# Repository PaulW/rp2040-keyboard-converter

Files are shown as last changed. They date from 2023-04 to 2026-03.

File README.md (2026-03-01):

# RP2040 Multi-Protocol Keyboard & Mouse Converter



A USB HID converter for keyboards and mice, using the RP2040's PIO (Programmable I/O) hardware to support multiple protocols.

**Features:**
- Multi-protocol support (AT/PS2, XT, Amiga, Apple M0110)
- Simultaneous keyboard and mouse conversion
- USB HID Boot Protocol for BIOS/UEFI compatibility
- Command Mode for firmware updates without physical access
- Persistent configuration storage

**Quick Links:** [📖 Full Documentation](docs/README.md) | [🚀 Getting Started](docs/getting-started/README.md) | [🔧 Hardware Setup](docs/hardware/README.md) | [💬 Discussions](https://github.com/PaulW/rp2040-keyboard-converter/discussions)

---

## 📚 Documentation

Complete documentation is available in the [`docs/`](docs/) directory. Here's what's covered:

**For Users:**
- [Getting Started](docs/getting-started/README.md) - Setup, building, and flashing firmware
- [Hardware Setup](docs/hardware/README.md) - Wiring diagrams and connector information
- [Supported Protocols](docs/protocols/README.md) - AT/PS2, XT, Amiga, M0110 specifications
- [Supported Keyboards](docs/keyboards/README.md) - Compatible keyboards and configurations
- [Scancode Sets](docs/scancodes/README.md) - Scancode sets and translation reference
- [Features Guide](docs/features/README.md) - Command Mode, LED support, configuration

**For Developers:**
- [Development Guide](docs/development/README.md) - Contributing, code standards, adding keyboards/protocols
- [Advanced Topics](docs/advanced/README.md) - Architecture, performance analysis, troubleshooting

**Quick Reference:**

| I want to... | See... |
|---|---|
| Build and flash firmware | [Getting Started](docs/getting-started/README.md) |
| Connect my keyboard | [Hardware Setup](docs/hardware/README.md) |
| Check compatibility | [Supported Keyboards](docs/keyboards/README.md) |
| Use Command Mode | [Features Guide](docs/features/README.md) |
| Contribute code | [Development Guide](docs/development/README.md) |

---

## ⚡ Quick Start

### 1. Clone Repository

```bash
git clone --recurse-submodules https://github.com/PaulW/rp2040-keyboard-converter.git
cd rp2040-keyboard-converter
```

### 2. Build Firmware

```bash
# Build Docker container (one-time setup)
docker compose build

# Compile firmware for your keyboard
docker compose run --rm -e KEYBOARD="modelm/enhanced" builder

# Optional: Add mouse support
docker compose run --rm -e KEYBOARD="modelm/enhanced" -e MOUSE="at-ps2" builder
```

### 3. Flash to RP2040

1. Hold **BOOT** button, press **RESET**, release **BOOT**
2. Copy `build/rp2040-converter.uf2` to the `RPI-RP2` drive
3. Device reboots automatically with new firmware

**📖 Detailed Instructions:** See [Getting Started Guide](docs/getting-started/README.md)

---

## 🔌 Supported Hardware

### Protocols

| Protocol | Type | Status | Documentation |
|---|---|---|---|
| **AT/PS2** | Keyboard & Mouse | ✅ Full Support | [Specification](docs/protocols/at-ps2.md) |
| **XT** | Keyboard | ✅ Full Support | [Specification](docs/protocols/xt.md) |
| **Amiga** | Keyboard | ✅ Full Support | [Specification](docs/protocols/amiga.md) |
| **M0110** | Keyboard | ⚠️ Partial Support | [Specification](docs/protocols/m0110.md) |

### Example Keyboards

| Manufacturer | Models | Protocol |
|---|---|---|
| **IBM** | Model F (PC/AT), Model M (Enhanced/122-key) | AT/PS2 |
| **Cherry** | G80-0614H, G80-1104H | XT |
| **Commodore** | Amiga A500/A2000 | Amiga |
| **Apple** | M0110/M0110A | M0110 |

**📋 Complete List:** See [Supported Keyboards](docs/keyboards/README.md)

---

## 🛠️ Available Build Configurations

Configure firmware for your specific keyboard when building:

```bash
# IBM keyboards
docker compose run --rm -e KEYBOARD="modelf/pcat" builder
docker compose run --rm -e KEYBOARD="modelm/enhanced" builder
docker compose run --rm -e KEYBOARD="modelm/m122" builder

# Other keyboards
docker compose run --rm -e KEYBOARD="cherry/G80-0614H" builder
docker compose run --rm -e KEYBOARD="amiga/a500" builder
docker compose run --rm -e KEYBOARD="apple/m0110a" builder
```

**🔍 See all configurations:** [`src/keyboards/`](src/keyboards/)

---

## ⚙️ Key Features

### Command Mode
Access firmware functions without physical board access:
- **Bootloader Mode** - Update firmware via USB (press B)
- **Debug Logging** - Adjust UART output level (press D)
- **Factory Reset** - Restore default settings (press F)
- **LED Brightness** - Adjust status LED (press L)
- **Shift Override** - Toggle non-standard shift legend remapping (press S)
- **Flow Tracking** - Toggle pipeline latency tracing, developer builds only (press T)

**Activation:** Hold both Shift keys for 3 seconds

**📖 Details:** [Command Mode Documentation](docs/features/command-mode.md)

### Configuration Storage
Settings persist across reboots and firmware updates:
- Log level preferences
- LED brightness
- Future: Macros and key remapping

**📖 Details:** [Configuration Storage](docs/features/config-storage.md)

### USB HID Boot Protocol
6-key rollover for maximum compatibility:
- Works in BIOS/UEFI
- Compatible with all operating systems
- No driver installation required

**📖 Details:** [USB HID Documentation](docs/features/usb-hid.md)

---

## 🔍 Debugging & Development

For troubleshooting and development information:
- **UART Debug Output** - Connect USB-UART adapter to GPIO 0/1 for diagnostics
- **Command Mode** - Adjust log levels without reflashing (press D in Command Mode)
- **Architecture Details** - See [Advanced Topics](docs/advanced/README.md) for system architecture
- **Development Tools** - See [Development Guide](docs/development/README.md) for lint scripts and testing

---

## 🤝 Contributing

Contributions are welcome! The project welcomes:
- New keyboard/protocol support
- Feature development (NKRO, dynamic keymaps, etc.)
- Hardware designs (PCBs, adapters, cases)
- Documentation improvements

**Before submitting PRs:**
1. Run `./tools/lint.sh` (must pass with zero errors/warnings)
2. Test your configuration builds successfully
3. Review [Development Guide](docs/development/README.md) for coding standards

---

## 📜 License

The project is licensed under **GPLv3** or later. Third-party libraries and code used in this project have their own licenses as follows:

* **Pico-SDK (https://github.com/raspberrypi/pico-sdk)**: License information can be found in the Pico-SDK repository.

* **TinyUSB (https://github.com/hathach/tinyusb)**: License information can be found in the TinyUSB repository. These licenses remain intact in any included portions of code from those shared resources.

* **Ringbuffer implementation (source files: ringbuf.c, etc.)**:
  * Based on code originally created by Hasu@tmk for the TMK Keyboard Firmware project.
  * Potential source references:
    * https://github.com/tmk/tinyusb_ps2/blob/main/ringbuf.h
    * https://github.com/tmk/tmk_keyboard/blob/master/tmk_core/ring_buffer.h
  * License: Likely GPLv2 or later (same as TMK) due to its inclusion in the TMK repository, but the exact origin is unclear.

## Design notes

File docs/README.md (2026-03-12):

# Documentation

**RP2040 Multi-Protocol Keyboard & Mouse Converter**

The RP2040 Multi-Protocol Keyboard & Mouse Converter lets you use vintage keyboards and mice with modern computers via USB. It originally started out as a converter for an IBM Model F PC/AT Keyboard I found in my parents' attic, and has since expanded to support a growing list of protocols, so you can connect a variety of vintage keyboards and mice to modern systems.

This documentation aims to cover everything from initial setup and configuration, through to hardware requirements, the different protocols supported, available features, and how to contribute to the project if you're interested. It may not cover absolutely everything, but should help you understand how it all works and get you up and running.

---

## 🚀 Getting Started

If you're new to the project, or just want to get up and running quickly, the [Quick Start Guide](getting-started/README.md) will walk you through everything from basic hardware setup to building and flashing the firmware.

## 🔧 Hardware

I've used a Waveshare RP2040-Zero for this project, as that's what I already had to hand. The RP2040's PIO (Programmable I/O) hardware provides dedicated state machines that can handle the microsecond-level timing requirements of vintage keyboard protocols without CPU intervention, which is why I chose it for this converter—and it was also a good excuse to learn something new.

- **[Hardware Overview](hardware/README.md)** - In-depth hardware guide with wiring diagrams
- **[Custom PCB](hardware/custom-pcb.md)** - Custom PCB design for IBM Model F

## 📡 Protocols

I've been working on adding support for a variety of protocols used by different devices, and I'm planning to expand this further as I get hold of more keyboards or mice to test with. The [Protocol Overview](protocols/README.md) provides details on what's currently supported, along with technical details on how each protocol is implemented.

### ⌨️ Keyboards

I've documented details about specific devices I currently own and have used to develop this project—hopefully enough detail that you can work out a configuration for your own device too. Check out [Supported Keyboards](keyboards/README.md) for more information.

### ✨ Features

As the project's evolved, I've added various features to make using the converter a bit more streamlined. This will continue to evolve over time as new features are added, but current documentation can be found in the [Features Documentation](features/README.md).

### 🔢 Scancodes

When a key is pressed, the keyboard sends a scancode—just a number identifying which key it was. Different protocols use different scancode sets, and the [Scancode Documentation](scancodes/README.md) explains how each one works, which keyboards use them, and how translation to HID keycodes happens.

### 🎓 Advanced Topics

If you're interested in understanding how the converter works, or need more specific information, I've put together some more technical information which covers things like the architecture, performance characteristics, and inner workings:

- **[Architecture Overview](advanced/README.md)** - System architecture, performance, PIO programming, build system, and troubleshooting

### 👨‍💻 Development

If you're interested in contributing to the project, or want to understand the codebase better, the development guide covers everything you need to know about the project's structure, coding standards, and how to add support for new devices or protocols:

- **[Development Guide](development/README.md)** - Contributing guidelines, code standards, testing, and architecture decisions

---

## 🔍 Quick Reference

### Common Tasks

| I want to... | Go to... |
| --- | --- |
| **Get started quickly** | [Quick Start Guide](getting-started/README.md) |
| **Build the firmware** | [Building Firmware](getting-started/building-firmware.md) |
| **Connect my keyboard** | [Hardware Setup](getting-started/hardware-setup.md) |
| **See what keyboards are already supported** | [Supported Keyboards](keyboards/README.md) |
| **Check supported Protocols** | [Protocol Overview](protocols/README.md) |
| **Understand scancode translation** | [Scancode Sets](scancodes/README.md) |
| **Understand architecture** | [Advanced Topics](advanced/README.md) |
| **Add a new keyboard** | [Development Guide](development/README.md) |
| **Contribute code** | [Development Guide](development/README.md) |

---

## 🔗 External Resources

- **[Main README](../README.md)** - Project overview
- **[Source Code](../src/)** - Firmware source code
- **[Pico SDK Documentation](https://www.raspberrypi.com/documentation/pico-sdk/)** - RP2040 SDK
- **[TinyUSB Documentation](https://docs.tinyusb.org/)** - USB stack
- **[GitHub Issues](https://github.com/PaulW/rp2040-keyboard-converter/issues)** - Report bugs or request features
- **[GitHub Discussions](https://github.com/PaulW/rp2040-keyboard-converter/discussions)** - Ask questions

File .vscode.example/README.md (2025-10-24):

# VS Code Configuration Examples

This directory contains example VS Code configuration files for local development with IntelliSense and CMake integration.

## Setup for Local Development (Optional)

**Note:** Local development setup is **optional**. You can use Docker for all builds without any local tooling.

### Prerequisites

#### macOS

1. **CMake** (for IntelliSense and build configuration)
   ```bash
   brew install cmake
   ```

2. **ARM GCC Toolchain** (for compiling)
   ```bash
   brew install --cask gcc-arm-embedded
   ```
   - Installs to: `/Applications/ArmGNUToolchain/*/arm-none-eabi/bin/`
   - Symlinked to: `/opt/homebrew/bin/arm-none-eabi-gcc`

3. **Pico SDK Submodule** (already included if you cloned with `--recurse-submodules`)
   ```bash
   git submodule update --init --recursive
   ```

#### Linux

1. **CMake**
   ```bash
   # Debian/Ubuntu
   sudo apt-get install cmake
   
   # Fedora
   sudo dnf install cmake
   
   # Arch
   sudo pacman -S cmake
   ```

2. **ARM GCC Toolchain**
   ```bash
   # Debian/Ubuntu
   sudo apt-get install gcc-arm-none-eabi
   
   # Fedora
   sudo dnf install arm-none-eabi-gcc-cs
   
   # Arch
   sudo pacman -S arm-none-eabi-gcc
   ```
   - Typically installs to: `/usr/bin/arm-none-eabi-gcc`

3. **Pico SDK Submodule**
   ```bash
   git submodule update --init --recursive
   ```

#### Windows

1. **CMake**
   - Download from [cmake.org](https://cmake.org/download/)
   - Or use: `winget install Kitware.CMake`

2. **ARM GCC Toolchain**
   - Download from [ARM Developer](https://developer.arm.com/tools-and-software/open-source-software/developer-tools/gnu-toolchain/gnu-rm)
   - Typically installs to: `C:\Program Files (x86)\GNU Arm Embedded Toolchain\<version>\bin\arm-none-eabi-gcc.exe`

3. **Pico SDK Submodule**
   ```bash
   git submodule update --init --recursive
   ```

### Installation

1. Copy the example configuration files to `.vscode/`:
   ```bash
   cp -r .vscode.example/ .vscode/
   ```

2. Configure CMake to generate `compile_commands.json`:
   ```bash
   mkdir -p .build-cache
   cd .build-cache
   cmake -DCMAKE_BUILD_TYPE=Debug \
         -DCMAKE_EXPORT_COMPILE_COMMANDS=ON \
         -DKEYBOARD=modelm/enhanced \
         -DMOUSE=at-ps2 \
         ../src
   cp compile_commands.json ..
   ```

3. Reload VS Code:
   - Press `Cmd+Shift+P` (Mac) or `Ctrl+Shift+P` (Windows/Linux)
   - Run **"Developer: Reload Window"**

### What You Get

- ✅ **IntelliSense** - Autocomplete for Pico SDK functions
- ✅ **Go to Definition** - Navigate to SDK headers and implementation
- ✅ **Error Checking** - Real-time syntax and type checking
- ✅ **Symbol Navigation** - Jump between functions and definitions
- ✅ **CMake Integration** - Configure and build from VS Code
- ✅ **File Associations** - 24+ header files properly recognized as C (project headers, Pico SDK, TinyUSB)
- ✅ **Code Formatting** - Google style with 100 column limit pre-configured
- ✅ **Doxygen Comments** - `/**` style for documentation

### Customization

Edit `.vscode/settings.json` to change the keyboard/mouse configuration:

```json
"cmake.configureEnvironment": {
  "KEYBOARD": "your-keyboard-here",
  "MOUSE": "at-ps2"
}
```

Available keyboards: `modelm/enhanced`, `modelf/pcat`, `xt/ibm5150`, `apple/m0110a`, `amiga/a500`

### Platform-Specific Notes

#### macOS
- ARM toolchain path: `/opt/homebrew/bin/arm-none-eabi-gcc` (Apple Silicon) or `/usr/local/bin/arm-none-eabi-gcc` (Intel)
- The example `c_cpp_properties.json` uses the Homebrew path
- If you installed the toolchain differently, update `compilerPath` in `.vscode/c_cpp_properties.json`

#### Linux
- ARM toolchain typically at: `/usr/bin/arm-none-eabi-gcc`
- Update `compilerPath` in `.vscode/c_cpp_properties.json` to match your installation
- Configuration name can be changed from "RP2040" to "Linux" if desired

#### Windows
- ARM toolchain path example: `C:/Program Files (x86)/GNU Arm Embedded Toolchain/10 2021.10/bin/arm-none-eabi-gcc.exe`
- Use forward slashes (`/`) in paths, not backslashes
- Update `compilerPath` in `.vscode/c_cpp_properties.json` to match your installation
- Create a "Windows" configuration in `c_cpp_properties.json` if needed

### Notes

- `.vscode/` is in `.gitignore` - your settings won't be committed
- `compile_commands.json` is regenerated each time you run CMake
- Docker builds don't require any of this setup
- **Compiler path varies by platform**: Update `compilerPath` in `c_cpp_properties.json` to match your system
  - macOS (Homebrew): `/opt/homebrew/bin/arm-none-eabi-gcc`
  - Linux: `/usr/bin/arm-none-eabi-gcc`
  - Windows: `C:/Program Files (x86)/GNU Arm Embedded Toolchain/<version>/bin/arm-none-eabi-gcc.exe`

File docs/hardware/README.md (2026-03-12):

# Hardware Guide

This guide covers everything you need to know about the hardware side of building the converter—from choosing the right components to understanding why certain design decisions were made. Whether you're planning a simple breadboard prototype or designing a custom PCB to fit inside your keyboard, you'll find what you need here.

---

## What's in This Guide

- **[Build Approaches](#choosing-your-build-approach)** - Breadboard vs PCB: which is right for you?
- **[Component Deep Dive](#understanding-components)** - Everything about RP2040 boards and level shifters
- **[Connectors and Cables](#connectors-and-cables)** - Finding the right connectors and where to get them
- **[Status LEDs](#status-leds)** - Adding visual feedback with WS2812B RGB LEDs
- **[Breadboards and Prototyping Supplies](#breadboards-and-prototyping-supplies)** - What you need for breadboard builds
- **[Custom PCB](#custom-pcb)** - Professional PCB design for internal installations

---

## Choosing Your Build Approach

There are a few different ways you can build this converter, and each has its trade-offs. I'd say it's worth taking a few minutes to think about what you're trying to achieve before you start buying components or wiring things up.

### Breadboard Prototype

**Best for**: First-time builds, testing, experimentation, or if you want to support multiple keyboards

A breadboard build is where I'd recommend starting. There's no soldering involved, you can put it together in under an hour, and if something's not working you can easily swap things around. It's forgiving, which is great if you're new to this or just want to test whether your keyboard actually works before you commit to anything permanent.

**What makes breadboards great:**

- **Quick to set up**: You can have it up and running in a single sitting
- **No soldering needed**: Just jumper wires and pre-made modules
- **Easy to modify**: Want to try different pins? Just pull it out and move it
- **Low cost**: Just the cost of a microcontroller, some jumper wires, and a connector
- **Reusable**: Take it apart and use the bits for something else
- **Great for learning**: You can actually see all the connections

**The trade-offs:**

- **Needs an external enclosure**: Breadboards require external housing
- **Connections can work loose**: Breadboards are fine for testing, but they're not great for long-term reliability
- **More wiring**: It's not as tidy as a PCB
- **Not ideal for portability**: If you're taking your keyboard places, loose connections aren't brilliant

**When this makes sense:**

- You're new to electronics and want something forgiving
- You're testing multiple keyboards or protocols
- You're developing new features or troubleshooting issues
- You want to try it out before committing to something permanent
- Budget's a concern

For the step-by-step breadboard build, check out the **[Getting Started Guide](../getting-started/hardware-setup.md)**.

---

### Custom PCB

**Best for**: Permanent installations, internal keyboard mounting, or if you want it to look professional

If you have a keyboard you really care about—maybe it's a collectible, or just something you want to use long-term—a custom PCB is worth considering. Everything's on one neat board, no loose wiring, and if you design it right you can mount it inside the keyboard so it's completely hidden. I built one for my IBM Model F PC/AT, and you'd never know it was there from the outside.

**What makes PCBs great:**

- **Looks professional**: Clean and compact
- **Internal installation**: Hide it inside the keyboard case—no external box
- **Solid connections**: Soldered joints don't work loose
- **Compact**: You can design boards to fit specific spaces
- **Integrated**: Everything on one board—level shifter, RP2040, connectors
- **Strain relief**: Proper mounting means cables aren't going to pull things apart

**The trade-offs though:**

- **Higher upfront cost**: PCB fabrication and components cost more upfront than a dev board solution
- **Needs PCB skills**: You'll need to know your way around KiCad or similar, and be comfortable soldering
- **Less flexible**: If you want to change protocols or pins, you're designing a new board
- **Keyboard-specific**: Designs are optimised for particular keyboards
- **Takes longer**: Design, order, wait for delivery, and assemble—longer than a breadboard build

**When this makes sense:**

- You have a valuable or collectible keyboard that deserves a proper installation
- You're comfortable with PCB design and soldering (or keen to learn)
- You want the converter to be invisible or minimally invasive
- You have a specific keyboard in mind for permanent conversion
- You're planning to convert multiple units of the same keyboard

**Real example**: My custom PCB for the IBM Model F PC/AT is only 40×30mm and mounts on the keyboard's internal frame using existing screw holes. It's got the level shifter, USB-C, RP2040, everything—completely invisible from outside.

Check out the **[Custom PCB Guide](custom-pcb.md)** for the full design, fabrication files, and installation photos.

---

## Understanding Components

Every converter needs the same core components, whether you're building on breadboard or designing a PCB. Let me walk you through what each one does and why it matters.

### RP2040 Microcontroller Board

This is the brain of the whole operation. The RP2040 handles all the protocol translation, USB communication, and features like Command Mode and Keytest.

**Why the RP2040 works so well for this:**

Other converters use Atmel AVR chips (like in Arduino Pro Micro boards), and they work fine. But the RP2040 has something really useful: **PIO state machines**. These are like little independent hardware processors that can monitor signals with microsecond precision without the main CPU needing to do anything. This means the converter can handle keyboard timing without using much CPU at all.

Traditional microcontrollers either bit-bang protocols in software (struggles with timing) or use fixed hardware peripherals like UART or SPI (not flexible enough). PIO gives you hardware-level timing with software-level flexibility—each state machine runs independently, watching the CLOCK and DATA lines.

**Key specs:**

- **Dual ARM Cortex-M0+ cores** running at 125MHz (we only use one)
- **264KB SRAM** - plenty of room, we run the code from RAM for performance
- **Eight PIO state machines** - hardware-level I/O with microsecond precision
- **30 GPIO pins** - flexible, can be assigned to any function
- **Native USB 1.1** support via TinyUSB
- **Low power** - minimal CPU usage even when typing

**Which board should you get?**

They're all based on the same RP2040 chip, so they're functionally identical. It comes down to size and USB connector.

| Board | Size | USB |
| --- | --- | --- |
| **Raspberry Pi Pico** | 51×21mm | Micro-B |
| **WaveShare RP2040-Zero** | 23.5×18mm | USB-C |
| **Pimoroni Tiny 2040** | 22×18mm | USB-C |
| **Adafruit Feather RP2040** | 51×23mm | USB-C |

The Raspberry Pi Pico has an RP2040 dual-core microcontroller, 26 multi-function GPIO pins, and is available with or without pre-soldered headers. The Waveshare RP2040-Zero has a smaller physical footprint (23.5×18mm), a USB-C connector, and a built-in WS2812B RGB LED on GPIO 16. This LED is compatible with the converter's WS2812B status LED support — set `LED_PIN` to 16 in [`config.h`](../../src/config.h) to use it. See [Status LEDs](#status-leds) for details.

### Bi-Directional Level Shifter

**This is the most important safety component** - don't skip it!

Here's the thing: your keyboard speaks 5V logic, but the RP2040 speaks 3.3V logic. The RP2040's GPIO pins are **NOT 5V tolerant**. If you connect 5V directly to them, you'll damage the chip. There's no "it might survive"—it just dies.

**What it does:**

It sits between your keyboard and the RP2040, translating voltages in both directions:

- Keyboard → RP2040: Converts 5V down to 3.3V (safe for the RP2040)
- RP2040 → Keyboard: Converts 3.3V up to 5V (proper logic levels for the keyboard)

**Why bi-directional?**

Many keyboard protocols require both the keyboard and host to drive the signal lines in both directions. A bi-directional level shifter handles this automatically without needing any direction control signals.

**Which level shifter should you get?**

**BSS138-Based 4-Channel Level Shifter**

Uses BSS138 N-channel MOSFETs for bidirectional level shifting. Suitable for the low-frequency clock and data signals used by AT/PS2 and XT protocols:

- **Channels**: 4 independent channels (2 used for CLOCK/DATA, 2 spare)
- **Speed**: Capable of MHz-range signals; more than sufficient for kHz keyboard protocols

**TXB0104 4-Bit Level Shifter** (Alternative)

Uses the TXB0104 with automatic direction sensing:

- **Chip**: TXB0104 automatic direction sensing
- **Channels**: 4 channels
- **Speed**: 100 Mbps data rate

**Important notes:**

- Both sides need their voltage references (LV=3.3V, HV=5V)
- All grounds must be tied together (keyboard, level shifter, RP2040)
- Never connect keyboard signals directly to RP2040—always through the level shifter
- GPIO pins are configurable in firmware (no fixed assignments)

**How to wire it:**

```text
Level Shifter Module:
LV (Low Voltage)  ─── RP2040 3V3 pin
LV1 (Channel 1)   ─── RP2040 GPIO (you choose which one)
LV2 (Channel 2)   ─── RP2040 GPIO (you choose which one)
LV3, LV4          ─── Unused (available for mouse or future expansion)
GND               ─── Common ground

HV (High Voltage) ─── Keyboard +5V or RP2040 VSYS
HV1 (Channel 1)   ─── Keyboard CLOCK line
HV2 (Channel 2)   ─── Keyboard DATA line
HV3, HV4          ─── Unused
GND               ─── Common ground
```

---

## Connectors and Cables

The connector you need depends on your keyboard. IBM-compatible connectors are widely used, but other keyboards use different types entirely.

### Most Common Connectors

**PS/2 (Mini-DIN-6)**

This is what you'll find on AT/PS2 keyboards and mice from the late 1980s onwards. It's a 6-pin round connector that was widespread through the '90s and 2000s.

- **Used by**: AT/PS2 keyboards and mice
- **Availability**: Pretty easy to find—eBay, electronics distributors, or just buy a PS/2 extension cable and cut it in half

**DIN-5 (180°)**

The older, larger connector you'll find on IBM PC/XT and early AT keyboards. It's got a 180° pin arrangement (not the 240° arrangement used for audio equipment—don't mix them up).

- **Used by**: IBM PC/XT and early AT keyboards
- **Availability**: eBay, or salvage from old motherboards

**Other Keyboards**

Some keyboards use completely different connectors—telephone-style modular jacks, internal PCB headers, or proprietary designs. You'll need to identify what your specific keyboard uses and find the pinout.

### Where to Get Connectors

**Easiest option**: Buy a keyboard extension cable on eBay and cut it in half. You get a connector with wires already attached.

**Other options:**

- **Breakout boards**: Search for "PS/2 breakout Arduino"—these give you screw terminals or pin headers
- **Salvage**: Desolder connectors from damaged motherboards or old keyboards (free, but needs desoldering skills)
- **Distributors**: Mouser, Digi-Key, or Farnell stock panel mount sockets if you want something proper

### Finding Your Keyboard's Pinout

The documentation might help—check if there's a specific page for your keyboard model in the **[protocol documentation](../protocols/README.md)**. If not, you'll need to trace the connections yourself or search online for pinout diagrams.

### USB Cables

Don't forget you'll need a USB cable to connect the RP2040 to your computer!

**What you need depends on your board:**

- **Raspberry Pi Pico**: USB-A to Micro-B
- **WaveShare RP2040-Zero / Pimoroni Tiny 2040**: USB-A to USB-C (or USB-C to USB-C for modern computers)

**Quality matters**: Cheap charging-only cables won't work—make sure it's rated for data transfer. If your converter isn't being recognised by your computer, try a different cable before you start troubleshooting everything else. Cable issues can be easy to miss.

---

## Status LEDs

The converter supports WS2812B addressable RGB LEDs for visual feedback. This is completely optional, but it's useful—you can see at a glance what state the converter's in without needing to check your computer.

### What the LED Shows

**Status Colours:**

- **🟢 Green**: Everything's working, converter's ready
- **🟠 Orange**: Waiting for keyboard initialisation
- **🟣 Magenta**: Bootloader mode (ready for firmware flashing)
- **💚💙 Flashing Green/Blue**: Command Mode active
- **💚💖 Flashing Green/Pink**: Log level selection mode
- **🌈 Rainbow**: Brightness adjustment mode

**Lock Indicators:**
If you use 4 LEDs instead of 1, the extra 3 show lock key states:

- **LED 2**: Num Lock
- **LED 3**: Caps Lock
- **LED 4**: Scroll Lock

### What You Need

**WS2812B LEDs** (also called "NeoPixels"):

- **Individual LEDs**: Around £1-2 each, easiest for breadboard
- **LED strips**: £5-8, useful if you want multiple LEDs (just use the first 1-4)
- **Breakout boards**: £2-5, pre-mounted LEDs with easier connections

**Where to buy**: Adafruit, SparkFun, Amazon, eBay—just search for "WS2812B" or "NeoPixel"

### Wiring

The WS2812B is 3.3V tolerant, so you can connect it straight to the RP2040:

```text
WS2812B LED:
3.3V  ──→ RP2040 3V3 (not 5V!)
GND   ──→ RP2040 GND
DIN   ──→ RP2040 GPIO 29 (default, can be changed)
```

**Important**: Use DIN (Data In), not DOUT (Data Out).

### Multiple LEDs (For Lock Indicators)

Chain them together by connecting DOUT of one LED to DIN of the next:

```text
GPIO 29 ──→ LED1 DIN
            LED1 DOUT ──→ LED2 DIN
                          LED2 DOUT ──→ LED3 DIN
                                        LED3 DOUT ──→ LED4 DIN

All LEDs share 3.3V and GND in parallel
```

**LED assignments:**

1. Status LED
2. Num Lock indicator
3. Caps Lock indicator
4. Scroll Lock indicator

### Using LED Strips

For WS2812B LED strips:

1. Cut after the 4th LED (if you want 4 total)
2. Find the input end (arrows show data direction)
3. Connect 3.3V, GND, and DIN to the first LED
4. The strip's already chained internally

**Tip**: LED strips often use JST connectors—you can either get a JST breakout adapter or solder wires directly to the pads.

### Changing the GPIO Pin

Default is GPIO 29 (defined in [`src/config.h`](../../src/config.h)). To change it:

1. Edit [`src/config.h`](../../src/config.h)
2. Find `#define LED_PIN 29`
3. Change to your preferred GPIO
4. Rebuild firmware

---

## Breadboards and Prototyping Supplies

If you're building a breadboard prototype (which I'd recommend for your first build), here's what you'll want to get.

### Breadboards

**Half-size breadboard** (400 tie-points, ~30 rows): About £3-5, and it's plenty big enough for the converter plus level shifter and RP2040 board. Full-size breadboards work too, but they're overkill unless you're planning to add loads of extra stuff.

### Jumper Wires

Get yourself an assorted kit with different lengths—you're looking at £5-10 for a decent set. Colour coding really helps keep track of what's what:

- **Red**: Power (VCC, 5V, 3.3V)
- **Black**: Ground
- **Yellow**: Clock signals
- **Green**: Data signals
- **Other colours**: Whatever else you need

**Wire types you'll want:**

- **Male-to-Male**: Breadboard-to-breadboard connections
- **Male-to-Female**: Breadboard to pin headers (on the RP2040 or level shifter)
- **Female-to-Female**: Less common for this project, but sometimes handy

**Tip**: Pre-formed wire kits are worth the small extra cost over loose assortments. Poor connections cause intermittent faults that can be difficult to debug.

### Enclosures (Optional but Recommended)

Once you have everything working, you'll want to protect it and stop things from shorting out:

**Project boxes**: Hammond 1591 series, Takachi cases, or generic ABS boxes run about £5-15. You'll want something around 100×60×25mm minimum to fit the RP2040, breadboard, and level shifter comfortably. Make sure you can access the USB port and route the keyboard cable properly.

**3D printed cases**: Loads of designs on Thingiverse and Printables for specific RP2040 boards. Search for "[your board name] case" and you'll find plenty of options. Some even include mounting for breadboards.

**DIY**: If you have access to CAD software (FreeCAD, Fusion 360, OnShape), you can design your own. Just measure your components, add a few mm clearance, design some mounting features, and export the STL.

---

## Custom PCB Guide

For detailed information about designing and building custom PCBs, including a complete worked example for the IBM Model F PC/AT, see the dedicated **[Custom PCB Guide](custom-pcb.md)**.

That guide covers:

- Complete PCB design process (schematic, layout, fabrication)
- Bill of materials and component selection
- Fabrication options (JLCPCB SMT assembly, DIY soldering)
- Installation guide with photos
- Cost considerations and fabrication options

---

## Related Documentation

**For building your first converter:**

- **[Getting Started Guide](../getting-started/README.md)** - Step-by-step build instructions
- **[Hardware Setup](../getting-started/hardware-setup.md)** - Detailed breadboard wiring guide

**Protocol-specific information:**

- **[Protocols Overview](../protocols/README.md)** - All supported protocols

**Keyboard configurations:**

- **[Supported Keyboards](../keyboards/README.md)** - Keyboard-specific configs and quirks

**Source code:**

- Keyboard configurations: [`src/keyboards/`](../../src/keyboards/)
- Protocol implementations: [`src/protocols/`](../../src/protocols/)

---

**Questions or stuck on something?**
Use [GitHub Discussions](https://github.com/PaulW/rp2040-keyboard-converter/discussions) or [open an issue](https://github.com/PaulW/rp2040-keyboard-converter/issues) if you've found a problem.

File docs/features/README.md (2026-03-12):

# Features Documentation

The converter includes several features that make it practical for daily use whilst keeping the architecture clean and non-blocking. This page gives you an overview of what's available—each feature has its own detailed guide linked below if you want to dive deeper.

## Core Features

### USB HID Interface

**[USB HID Guide](usb-hid.md)**

The converter uses standard USB HID Boot Protocol, which means it works everywhere without drivers—BIOS screens, UEFI setup, Windows, macOS, Linux, BSD, and other operating systems. The Boot Protocol is intentionally simple and universally supported, which is exactly what you want when converting keyboards.

The interface reports up to 6 simultaneous regular keys plus all 8 modifiers (left and right Shift, Ctrl, Alt, and GUI). This is called 6-Key Rollover (6KRO), and mirrors the USB HID Boot Protocol report format used by the converter.

When built with mouse support, the converter can handle simultaneous keyboard and mouse conversion if you have an AT/PS2 mouse to connect. LED indicators (Caps Lock, Num Lock, Scroll Lock) synchronise properly with the host OS, so the keyboard's lock LEDs update when you press the lock keys—assuming your keyboard protocol supports LED control.

**See:** [USB HID Guide](usb-hid.md) for complete technical details about report formats, timing, and USB polling

---

### Command Mode

**[Command Mode Guide](command-mode.md)**

Command Mode provides access to special functions without requiring firmware reflashing or device disconnection.

**Activation:**

- Hold both shift keys for 3 seconds
- LED begins alternating between green and blue
- Mode auto-exits after 3 seconds of inactivity or immediately after executing a command

**Available Commands:**

- 🔄 **'B'**: Enter bootloader (BOOTSEL mode for firmware updates)
- 🐛 **'D'**: Change log level (then press 1/2/3 for ERROR/INFO/DEBUG)
- ⚙️ **'F'**: Factory reset (restore default configuration and reboot)
- 💡 **'L'**: LED brightness (then press +/- to adjust, 0=off to 10=max)
- ↕️ **'S'**: Toggle shift-override (keyboards with non-standard shift legends only)
- 🔬 **'T'**: Toggle flow tracking _(developer builds only — requires `FLOW_TRACKING_ENABLED 1` and DEBUG log level)_

**See also:** [Flow Tracking Guide](../advanced/flow-tracking.md) for enabling, reading the UART output, and how it works internally

**LED Feedback:**

- Alternating green/blue - Command Mode active
- Solid green - Normal operation resumed

**See:** [Command Mode Guide](command-mode.md) for complete activation instructions and command reference

---

### Configuration Storage

**[Configuration Storage Guide](config-storage.md)**

Configuration settings persist across reboots using the flash storage system. LED brightness, log level, and protocol settings are saved to the last 4KB sector of internal flash memory, eliminating the need for reconfiguration after power cycling.

The implementation uses a dual-copy redundancy system for data integrity. Two copies (A and B) are stored, each with CRC validation to detect corruption. Writes alternate between the copies for wear leveling, which extends flash life to about 10,000 write cycles per location before degradation. That's plenty for configuration updates that happen occasionally rather than continuously.

Currently stored settings include your log level (ERROR, INFO, or DEBUG), LED brightness level (0-10 scale), protocol initialisation parameters, and timing thresholds.

**See:** [Configuration Storage Guide](config-storage.md) for technical details about flash allocation and redundancy

---

### LED Indicators

**[LED Support Guide](led-support.md)** · **[LED Indicators Guide](led-indicators.md)**

LED indicators provide visual feedback about converter status, including operational state, Command Mode activation, and error conditions. Every converter requires at least one status LED, with optional WS2812 RGB LEDs available for enhanced visibility.

**Converter Status Indicators:**

- Status LED (RGB): Shows operational state and command mode
- Power indication
- Error states and protocol issues

The status LED shows different colours depending on what's happening. Solid green means everything's working normally. Solid orange (`CONVERTER_LEDS_STATUS_NOT_READY_COLOUR`) appears whenever the converter is not ready—during startup whilst firmware initialises, or if the keyboard/mouse is uninitialised. Alternating green and blue indicates Command Mode is active and waiting for you to press a command key. Solid magenta means bootloader mode (firmware flash mode). These patterns make it easy to tell what's going on without needing to connect debug tools.

**Keyboard Lock Indicators:**

For keyboard lock indicators (Caps Lock, Num Lock, Scroll Lock), the converter handles synchronisation automatically. When a lock key is pressed, the host OS sends LED states back through the HID protocol. The converter forwards these states to the keyboard using the appropriate LED command format for the protocol. AT/PS2 keyboards receive the standard 0xED LED command followed by a bitmap. Amiga keyboards have special handling for CAPS LOCK only (bit 7 of the CAPS LOCK scancode represents the LED state). XT and Apple M0110 keyboards do not support LED control—both use unidirectional protocols with no host-to-keyboard commands. See the protocol implementations in `src/protocols/` and respective protocol documentation for detailed behaviour.

**Optional WS2812 RGB LED:**

- Status indicator (Command Mode)
- Configurable brightness

WS2812 RGB LEDs (NeoPixels) can be added for enhanced visual feedback. These connect to GPIO 29 by default and support configurable brightness through Command Mode. WS2812 support is optional and disabled by default to conserve power.

**See:** [LED Support Guide](led-support.md) for status patterns, WS2812 configuration, and brightness control; [LED Indicators Guide](led-indicators.md) for keyboard lock LED synchronisation and protocol details

---

### Mouse Support

**[Mouse Support Guide](mouse-support.md)**

Mouse support allows connection of a mouse alongside the keyboard, providing complete period-accurate input hardware. The mouse operates independently from the keyboard using separate GPIO pins and a separate PIO state machine, preventing any signal interference.

AT/PS2 protocol mice that follow the standard packet formats are currently supported. The converter handles standard 3-byte packets (buttons, X movement, Y movement) and extended 4-byte packets for mice with scroll wheels (IntelliMouse protocol). Scroll wheel detection occurs automatically during initialisation.

Mouse support is protocol-agnostic and works with any keyboard protocol. An AT/PS2 mouse can be paired with XT, Amiga, or M0110 keyboards because the mouse uses dedicated hardware lines (CLOCK and DATA separate from keyboard lines), allowing parallel operation without coordination. Press keys whilst moving the mouse, scroll whilst holding modifier keys, click whilst typing—everything works as expected because the signals never cross paths.

To enable mouse support, add the MOUSE environment variable when building firmware:

**Example:**

```bash
# Build with keyboard + mouse
docker compose run --rm -e KEYBOARD="modelm/enhanced" -e MOUSE="at-ps2" builder
```

**Hardware Requirements:**

- Separate CLOCK and DATA lines for mouse (independent from keyboard)
- Level shifters required (5V → 3.3V)
- GPIO pins configured in [`config.h`](../../src/config.h)

**See:** [Mouse Support Guide](mouse-support.md) for complete wiring instructions and protocol details

---

### Keyboard Layers

**[Keyboard Layers Guide](layers.md)**

Keyboard layers provide a way to access multiple sets of key functions from the same physical keys. Think of them as transparent overlays—activate a layer and the keys do different things. Use cases include compact keyboards or adding media controls to hardware that lacks dedicated keys.

The converter supports 4 switchable layers plus base Layer 0 (layers 0–4). Layer 0 is always active as the base layer, and upper layers overlay on top. Keys can be transparent in upper layers, falling through to lower active layers until a keycode is found, so you only need to define the keys that actually change.

**Layer activation methods:**

- **Momentary (MO)**: Active whilst held, like a traditional layer key (does not persist)
- **Toggle (TG)**: Stays on until toggled off again (persists across reboots via `config_set_layer_state()` and `config_save()`)
- **Switch To (TO)**: Permanently switches to that layer (persists across reboots via `config_set_layer_state()` and `config_save()`)
- **One-Shot (OSL)**: Activates for exactly one keypress (does not persist)

Practical use cases include adding media controls (volume, playback) to keyboards that lack dedicated keys, accessing function keys F13-F24 on compact keyboards, providing numpad navigation on keyboards without a NumLock key, or switching between QWERTY and alternative layouts like Dvorak or Colemak.

The layer system is entirely optional. If you do not use any layer-switch keycodes (MO, TG, TO, OSL), a single-layer keymap will work as expected. Layers add flexibility without requiring hardware modifications.

**See:** [Keyboard Layers Guide](layers.md) for concepts and practical examples, or [Custom Keymaps Guide](../development/custom-keymaps.md) for implementation details

---

### Logging

**[Logging Guide](logging.md)**

The converter provides detailed UART-based logging to help you understand what it's doing and diagnose problems. This is particularly useful when you're adding support for a new keyboard or troubleshooting protocol issues—you can watch the raw scancodes come in, see how they're processed, and spot where things go wrong.

The logging implementation uses DMA-driven UART, which means log messages transmit in the background without blocking keyboard processing. Even at DEBUG log level (which outputs every scancode), logging never adds latency to your keystrokes. The UART operates completely independently from USB, so debug output keeps working even if the USB connection has problems—exactly when you need it most.

You can adjust the log level through Command Mode without reflashing firmware. Press D in Command Mode, then 1 for ERROR (just critical errors), 2 for INFO (initialisation and state changes), or 3 for DEBUG (everything including individual scancodes). The setting persists across reboots, so you only need to set it once.

Log output looks like this:

```text
[INFO] Keyboard interface initialised (AT/PS2)
[DBG] Scancode: 0x1C (Make)
[ERR] Parity error detected
[INFO] Command mode activated
```

To view logs, connect a USB-to-UART adapter to GPIO 0 (TX) and GPIO 1 (RX, optional) with a shared ground connection. Set your terminal program to 115200 baud, 8 data bits, no parity, 1 stop bit. Any standard terminal program works—screen, minicom, PuTTY, or CoolTerm.

**See:** [Logging Guide](logging.md) for complete wiring instructions, terminal setup, and log format reference

---

## Architectural Principles

All these features follow the same architectural principles that keep the converter responsive and reliable.

### Non-Blocking Architecture

Nothing in the converter ever blocks. No `sleep_ms()`, no `busy_wait_us()`, no polling loops that halt execution. This is critical for maintaining the microsecond-level timing that keyboard protocols require. Even a brief blocking operation can cause the ring buffer to overflow and drop scancodes.

Instead, everything uses non-blocking state machines with timeouts:

```c
// ❌ BAD: Blocking
sleep_ms(100);

// ✅ GOOD: State machine with timeout
static uint32_t state_start = 0;
if (to_ms_since_boot(get_absolute_time()) - state_start > 100) {
  // Timeout reached, proceed
}
```

This pattern appears throughout the codebase—protocol handlers, Command Mode, LED updates. The main loop runs continuously without blocking, checking state machines and processing events as they occur, which is what keeps the converter working reliably.

**Note:** `config_save()` is an intentional exception. Calling it during layer Toggle (TG) or Switch-To (TO) operations does block — it issues `flash_range_erase()` and `flash_range_program()` to persist the new layer state to flash, which briefly halts HID events and USB reports during the erase/write cycle. This is by design, as flash writes require interrupts to be disabled.

**See:** [Architecture Guide](../advanced/architecture.md) for complete details about the non-blocking design

---

### Performance Optimisation

The converter runs on an RP2040 microcontroller with 264KB SRAM and dual 125MHz ARM Cortex-M0+ cores — the converter uses a single core only.

The 32-byte ring buffer provides adequate burst handling—it can queue up several scancodes before the main loop processes them. The non-blocking architecture ensures the converter remains responsive even under continuous input.

Actual memory figures are reported in the build output.

**See:** [Advanced Topics](../advanced/README.md) for detailed performance analysis and measurements

---

## Related Documentation

If you want to dive deeper into how these features work or understand the implementation details, have a look at these guides:

**Getting Started:**

- [Getting Started Guide](../getting-started/README.md) - Initial setup and first firmware build
- [Hardware Setup](../getting-started/hardware-setup.md) - Wiring diagrams and connections

**Technical Details:**

- [Protocols Overview](../protocols/README.md) - How keyboard protocols work
- [Advanced Topics](../advanced/README.md) - System architecture and troubleshooting
- [Development Guide](../development/README.md) - Contributing and code standards

**Source Code References:**

- Command Mode: [`command_mode.c`](../../src/common/lib/command_mode.c)
- HID Interface: [`hid_interface.c`](../../src/common/lib/hid_interface.c)
- Config Storage: [`config_storage.c`](../../src/common/lib/config_storage.c)
- Flow Tracker: [`flow_tracker.c`](../../src/common/lib/flow_tracker.c)

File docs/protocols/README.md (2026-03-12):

# Protocol Documentation

Early keyboards used different communication protocols. With no standardised interface in the early computer marketplace, each manufacturer developed their own approach. As I've collected different keyboards over time, I've implemented support for multiple protocols to get them working with modern systems, and I hope to add more as and when I get hold of anything new.

Below you'll find details on each protocol, plus quick reference tables if you're not sure which one your keyboard uses.

---

## Supported Protocols

### Keyboard Protocols

| Protocol | Example Keyboards | Documentation |
| --- | --- | --- |
| **AT/PS2** | IBM Model M, IBM Model F PC/AT | **[→ Full Guide](at-ps2.md)** |
| **XT** | IBM Model F XT | **[→ Full Guide](xt.md)** |
| **Amiga** | Commodore Amiga A500/A1000/A2000/A3000 | **[→ Full Guide](amiga.md)**  |
| **Apple M0110** | Macintosh M0110, M0110A, M0110B | **[→ Full Guide](m0110.md)**  |

### Mouse Protocols

| Protocol | Documentation |
| --- | --- |
| **AT/PS2 Mouse** | **[→ Full Guide](at-ps2.md#mouse-implementation)** |

**Note**: Mouse protocol documentation is included in the AT/PS2 guide, as both keyboard and mouse use the same underlying protocol with different data formats.

---

## Quick Protocol Selection

If you're not sure which protocol your keyboard uses, this table should help:

| Your Keyboard | Protocol |
| --- | --- |
| IBM Model M Enhanced (1391401) | AT/PS2 |
| IBM Model M (101/102-key) | AT/PS2 |
| IBM Model F PC/AT | AT/PS2 |
| IBM Model F XT | XT |
| Commodore Amiga keyboard (any model) | Amiga |
| Apple Macintosh M0110/M0110A | M0110 |
| Keyboards with 5-pin DIN connector | See note 1 |
| Keyboards with 6-pin mini-DIN connector | See note 2 |

> **Note 1 — 5-pin DIN connector:** The 5-pin DIN connector was shared by XT, AT/PS2, and Amiga keyboards — the connector alone doesn't tell you the protocol. See [xt.md](xt.md), [at-ps2.md](at-ps2.md), [amiga.md](amiga.md) to identify yours.
>
> **Note 2 — 6-pin mini-DIN connector:** The 6-pin mini-DIN (PS/2-style) connector indicates PS/2-era keyboards; consult [at-ps2.md](at-ps2.md) and the model-specific docs to confirm the protocol.

**Still unsure?** See the [Keyboards Documentation](../keyboards/README.md) for detailed keyboard identification.

---

## Feature Comparison

Here's how the protocols stack up against each other:

| Feature | AT/PS2 | XT | Amiga | M0110 |
| --- | --- | --- | --- | --- |
| **Direction** | Bidirectional | Unidirectional | Bidirectional | Poll-based |
| **LED Control** | ✅ Yes | ❌ No | ❌ No (keyboard manages own state) | ❌ No |
| **Error Detection** | ✅ Parity | ❌ None | ✅ Handshake | ❌ Minimal |
| **Host Commands** | ✅ Yes | ❌ No | ✅ Limited | ✅ Yes |
| **Complexity** | High | Low | High | Medium |

**For detailed technical specifications, timing diagrams, and implementation notes, see each protocol's dedicated documentation.**

**Hardware note:** Most vintage keyboards and mice use 5V logic, but the RP2040's GPIO pins are 3.3V and not 5V tolerant. You'll need bidirectional level shifters (BSS138-based modules work well) on both the CLOCK and DATA lines. See the [Hardware Setup](../hardware/README.md) guide for wiring details.

---

## Related Documentation

**Detailed Guides:**

- **[AT/PS2 Protocol](at-ps2.md)** - Comprehensive guide with keyboard and mouse implementation
- **[XT Protocol](xt.md)** - Full specifications and genuine vs clone detection
- **[Amiga Protocol](amiga.md)** - Handshake timing and special features
- **[Apple M0110 Protocol](m0110.md)** - Poll-based protocol and command reference

**Hardware and Setup:**

- **[Hardware Setup](../hardware/README.md)** - Physical connections and wiring
- **[Keyboards](../keyboards/README.md)** - Supported keyboard models
- **[Getting Started](../getting-started/README.md)** - Quick start guide

**Advanced Topics:**

- **[Advanced Topics](../advanced/README.md)** - Implementation details and PIO programs
- **[Scancode Sets](../scancodes/README.md)** - Scancode translation and encoding

**Source Code:**

- Protocol implementations: [`src/protocols/`](../../src/protocols/)
- PIO programs: within [`src/protocols/`](../../src/protocols/) (e.g., `interface.pio`, `keyboard_interface.pio`)

---

**Questions or stuck on something?**
Use [GitHub Discussions](https://github.com/PaulW/rp2040-keyboard-converter/discussions) or [open an issue](https://github.com/PaulW/rp2040-keyboard-converter/issues) if you've found a problem.

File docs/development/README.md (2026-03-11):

# Development Documentation

This guide helps developers contribute to the RP2040 keyboard converter project, whether you're adding support for a new keyboard, implementing a different protocol, or fixing bugs. The project maintains strict architectural constraints to achieve precise timing and deterministic performance, so understanding these principles before contributing is essential.

## Getting Started with Development

### Contributing Guide

Contributing to an embedded systems project requires understanding both the hardware constraints and the software architecture. Before writing any code, you need to internalise the critical design principles that make this converter work reliably across dozens of keyboard models.

Start by reviewing the [Code Standards](code-standards.md) documentation—this contains the critical architecture rules that must never be violated. The standards explain why blocking operations break protocol timing, why Core 1 stays disabled, and how the ring buffer maintains data integrity without locks. Every rejected pull request traces back to violating principles documented there.

Next, review the [Advanced Topics guide](../advanced/README.md) to understand how PIO state machines handle protocol timing, how the ring buffer coordinates interrupt and main loop contexts, and why code executes from SRAM rather than flash. This architectural overview connects the individual rules to the overall system design, helping you understand the "why" behind each constraint.

Finally, familiarise yourself with the [Protocol Documentation](../protocols/README.md) and the `src/protocols/` directory to understand the supported interfaces and their timing constraints.

The contribution process follows standard Git workflows with careful attention to quality. Fork the repository and clone it locally, then create a feature branch using conventional commit prefixes (`git checkout -b feat/my-feature`). Make your changes following the code standards detailed below, ensuring every function has clear comments and variable names explain their purpose. Before committing, run [`./tools/lint.sh`](../../tools/lint.sh) to catch architecture violations—the script must pass with zero errors and zero warnings, or continuous integration will reject your pull request.

Commit messages follow the conventional commits format, using prefixes like `feat:` for new features, `fix:` for bug corrections, `docs:` for documentation updates, `refactor:` for code restructuring, and `test:` for testing additions. Each commit message should explain what changed and why, helping reviewers understand your reasoning without needing to decode the diff. Finally, create a pull request with a clear description of what you've changed, why the change is necessary, and how you've tested it.

The CI pipeline automatically builds all keyboard configurations in the build matrix, runs lint checks, and enforces memory limits (Flash <230KB, RAM <150KB). CodeRabbit provides automated review focusing on embedded systems best practices and architecture compliance.

---

### Code Standards

Code quality in embedded systems goes beyond style preferences—it's about writing deterministic, maintainable code that behaves predictably under timing constraints. The project follows C11 standards with conventions optimised for readability and debugging.

Use 4-space indentation throughout (never tabs), which ensures consistent display across editors without configuration. Function and variable names use snake_case for familiarity to C programmers, whilst macros and constants use UPPER_CASE to make their compile-time nature immediately obvious. Choose descriptive names that explain purpose without needing comments—`keyboard_state_machine_task()` tells you more than `kbd_sm()` ever could.

The critical architecture rules deserve special emphasis because violating them breaks functionality rather than just style. Never use blocking operations like `sleep_ms()`, `sleep_us()`, `busy_wait_ms()`, or `busy_wait_us()` anywhere in production code. The main loop must continuously service the ring buffer and USB stack, so even brief blocking causes scancode loss. If you need time-based behaviour, implement non-blocking state machines that check elapsed time on each iteration using `to_ms_since_boot(get_absolute_time())`.

Never call multicore APIs (`multicore_*`, `core1_*`) or attempt to use Core 1. The single-core architecture eliminates synchronisation complexity and delivers predictable latency. Adding multicore would introduce bugs without performance benefit. Never use `printf()` or related functions in interrupt context—these functions use DMA-driven UART that conflicts with interrupt handlers. Use the `LOG_*` macros instead, which handle interrupt-safe output buffering.

Never call `ringbuf_reset()` with interrupts enabled. The ring buffer implements lock-free single-producer/single-consumer (SPSC) semantics, which breaks if you reset both pointers whilst an interrupt might be writing. Only reset during initialisation before enabling interrupts, or within an explicit interrupt-disabled critical section. All code must execute from SRAM using the `copy_to_ram` binary type—this ensures deterministic timing without flash cache misses affecting latency measurements.

Use volatile qualifiers and memory barriers (`__dmb()`) when sharing data between interrupt and main contexts. The compiler and CPU both reorder operations for optimisation, which breaks interrupt communication without explicit synchronisation. Place `volatile` on variables written in IRQ and read in main, then use `__dmb()` after volatile writes and before volatile reads to enforce ordering.

Here's the pattern for non-blocking timeouts:

- ❌ No multicore APIs (`multicore_*`, `core1_*`)
- ❌ No `printf` in IRQ context (use `LOG_*` macros)
- ❌ No `ringbuf_reset()` with IRQs enabled
- ✅ All code runs from SRAM (`copy_to_ram`)
- ✅ Non-blocking state machines for timing
- ✅ Volatile + memory barriers for IRQ communication

**Example (Non-blocking timeout):**

```c
static uint32_t timer = 0;
static enum { IDLE, WAITING, DONE } state = IDLE;

void my_task(void) {
  uint32_t now = to_ms_since_boot(get_absolute_time());

  switch (state) {
    case IDLE:
      timer = now;
      state = WAITING;
      break;
    case WAITING:
      if (now - timer >= TIMEOUT_MS) {
        state = DONE;
      }
      break;
    case DONE:
      // Process
      state = IDLE;
      break;
  }
}
```

---

### Testing

Testing embedded systems requires multiple verification layers—automated checks catch architecture violations, build testing ensures compilation across configurations, and hardware validation confirms real-world functionality. Each layer serves a different purpose in the quality assurance process.

Run the lint script before every commit: `./tools/lint.sh` must pass with zero errors and zero warnings. The script runs 17 comprehensive checks including blocking operations (`sleep_ms`, `sleep_us`, `busy_wait_us`, `busy_wait_ms`), multicore API usage (`multicore_*`, `core1_*`), printf calls in interrupt context, indentation consistency (4-space required), volatile variable usage with memory barriers, header guards, include order, file headers, and protocol setup patterns. The script provides detailed error messages showing exactly which line violates which rule, making fixes straightforward. See [`tools/README.md`](../../tools/README.md) for complete check descriptions.

Build testing verifies that your changes compile successfully across different keyboard configurations. Test at least one configuration locally using Docker: `docker compose run --rm -e KEYBOARD="modelm/enhanced" builder`. If your changes affect protocol handling, test multiple protocols: `modelf/pcat` (AT/PS2), `modelf/xt` (XT), and `amiga/standard` (Amiga). The CI pipeline tests all configurations in the build matrix automatically, but catching build failures locally saves iteration time.

Hardware testing with actual keyboards remains essential—timing behaviour, signal characteristics, and protocol quirks manifest only with real hardware. Follow the [Hardware Setup guide](../getting-started/hardware-setup.md) for wiring and level shifting. Test all keys systematically, paying special attention to extended keys (E0 prefixes), modifiers, and the Pause key (eleven-byte sequence). Use [Command Mode's keytest function](../features/command-mode.md) to verify HID reports for each key press. Test Command Mode bootloader entry (hold Left Shift + Right Shift for 3 seconds) to ensure the special mode still works. Monitor UART logs using the [Logging guide](../features/logging.md) to observe protocol state transitions and catch errors.

Additional testing resources include [`./tools/lint.sh`](../../tools/lint.sh) for lint checks, [`.github/workflows/ci.yml`](../../.github/workflows/ci.yml) for the complete CI build matrix, and [Building Firmware](../getting-started/building-firmware.md) for Docker build procedures.

---

## Development Guides

Detailed guides for the most common development tasks:

- **[Contributing Guide](contributing.md)** - Pull request process, branch naming, and commit format
- **[Adding Keyboards](adding-keyboards.md)** - Step-by-step guide to supporting a new keyboard model
- **[Custom Keymaps](custom-keymaps.md)** - Remapping keys and configuring layers
- **[Protocol Implementation](protocol-implementation.md)** - Adding a new keyboard protocol
- **[Code Standards](code-standards.md)** - Architecture rules and coding conventions

### Adding Protocol Support

How to add support for new keyboard protocols:

**Steps:**

1. **Research**: Understand timing, framing, communication flow
2. **Create Directory**: `src/protocols/<name>/`
3. **PIO Program**: Write `.pio` for bit timing and framing

Start by researching the protocol thoroughly—you need to understand timing (clock frequency, bit duration, frame structure), signaling (voltage levels, idle states, edge polarities), and communication flow (unidirectional vs bidirectional, who generates the clock, how errors get detected). Datasheets, oscilloscope captures, and existing implementations all provide valuable information.

Create a directory structure at `src/protocols/<name>/` containing all the protocol-specific files. The PIO program (`<name>.pio`) implements the low-level bit timing and frame synchronisation in PIO assembly—this hardware state machine handles clock edge detection, bit shifting, and interrupt generation without CPU involvement. The protocol interface (`keyboard_interface.h` and `keyboard_interface.c`) implements the state machine for protocol initialisation, error recovery, and LED command handling. The common interface (`common_interface.c`) provides standardised `keyboard_init()`, `keyboard_task()`, and `keyboard_set_leds()` functions that the main loop calls, isolating protocol-specific details from the rest of the system.

**Protocol Setup Pattern:** All protocol implementations follow a standard initialisation sequence. See the [Protocol Implementation Guide](protocol-implementation.md) for the complete pattern and explanation of why each step matters. Following this pattern ensures consistency, proper resource allocation, and correct error handling across all protocols.

Document the protocol comprehensively in a `README.md` file including timing diagrams, electrical specifications, state machine descriptions, and oscilloscope captures if available. This documentation helps future maintainers understand the protocol without reverse-engineering your code.

Study the reference implementations to understand the patterns. The [`src/protocols/xt/`](../../src/protocols/xt/) implementation demonstrates simple unidirectional protocols (see [XT protocol docs](../protocols/xt.md) for details). The [`src/protocols/at-ps2/`](../../src/protocols/at-ps2/) implementation shows complex bidirectional communication with host-to-device commands (see [AT/PS2 protocol docs](../protocols/at-ps2.md)). The [`src/protocols/amiga/`](../../src/protocols/amiga/) implementation illustrates unique handshake timing (see [Amiga protocol docs](../protocols/amiga.md)). The [`src/protocols/apple-m0110/`](../../src/protocols/apple-m0110/) handles variable timing protocols (see [M0110 protocol docs](../protocols/m0110.md)).

Finally, test with actual hardware—protocol timing issues only manifest with real keyboards, not in simulation. The [Protocols overview](../protocols/README.md) explains the overall protocol architecture, whilst the [PIO helper library](../../src/common/lib/pio_helper.c) provides utilities for loading and managing PIO programs.

---

### Adding Keyboard Support

Adding support for a specific keyboard model mostly involves configuration and keymap definition—the protocol and scancode infrastructure already handle the low-level communication, so you're primarily mapping physical keys to HID keycodes and providing metadata.

Start by identifying which protocol the keyboard speaks (AT/PS2, XT, Amiga, or M0110), which scancode set it uses (Set 1, Set 2, Set 3, or protocol-specific), and what connector it has (5-pin DIN, 6-pin mini-DIN, RJ-11, etc.). The keyboard's manual, online documentation, or community knowledge bases usually provide this information. If uncertain, test with a logic analyzer to observe the actual signals.

Create a directory at [`src/keyboards/`](../../src/keyboards/)`<brand>/<model>/` to hold all keyboard-specific files. The `keyboard.config` file uses simple KEY=value pairs to specify the keyboard's characteristics:

```ini
# src/keyboards/modelm/enhanced/keyboard.config
MAKE=IBM
MODEL=Model M Enhanced PC Keyboard
DESCRIPTION=IBM Personal Computer AT Enhanced Keyboard
PROTOCOL=at-ps2
CODESET=set123
```

See [`src/keyboards/modelm/enhanced/keyboard.config`](../../src/keyboards/modelm/enhanced/keyboard.config) for a complete example. The build system reads this configuration and automatically includes the appropriate protocol handler and scancode processor.

Define the keymap in `keyboard.c` using the layout macros that match the keyboard's physical arrangement. The KEYMAP macros arrange keycodes spatially to mirror the actual key positions, making it easy to verify correctness by visual inspection:

```c
// src/keyboards/modelm/enhanced/keyboard.c
#include "keyboard.h"

const uint8_t KEYMAP[256] = KEYMAP_US_ANSI(
  KC_ESC, KC_F1, KC_F2, ...
);
```

If the keyboard lacks both shift keys (like the Apple M0110 which has only one shift), override the Command Mode activation keys by defining `CMD_MODE_KEY1` and `CMD_MODE_KEY2` in `keyboard.h` before including other headers. The default combination (Left Shift + Right Shift) won't work on single-shift keyboards. See [Command Mode customisation](../features/command-mode.md#keyboard-specific-configuration) for details on implementing these overrides.

Create a `README.md` documenting the keyboard's specifications, connector pinout, any quirks or special behaviour, and build instructions. This helps users understand what they're building firmware for and assists troubleshooting.

Build and test with the actual hardware—verify all keys produce correct characters, test modifier combinations, confirm LEDs respond to system state, and validate Command Mode entry. Explore the [`src/keyboards/`](../../src/keyboards/) directory for examples, review the [Keyboards documentation](../keyboards/README.md) for patterns, and examine [`CMakeLists.txt`](../../src/CMakeLists.txt) to understand build integration.

---

### Adding Scancode Sets

Supporting a new scancode set requires implementing a state machine that assembles multibyte sequences and a mapping table that translates scancodes to USB HID keycodes. The challenge lies in handling protocol-specific conventions like prefix bytes, make/break codes, and extended key sequences.

Research the scancode format thoroughly—understand whether the protocol uses separate make and break codes or a single code with a prefix, whether extended keys require special prefixes (like E0 in AT/PS2 Set 2), and whether any keys send multibyte sequences (like the Pause key's eleven-byte sequence). Manufacturer documentation, community reverse-engineering efforts, and existing converter projects provide this information.

Create a directory at [`src/scancodes/`](../../src/scancodes/)`<set>/` for all scancode-specific files (see existing implementations in [docs/scancodes/](../scancodes/README.md) for examples). Implement the state machine in `scancode_processor.h` and `scancode_processor.c`—this code receives individual bytes from the protocol handler and assembles them into complete scancode events. The state machine tracks whether it's expecting a prefix byte, whether the next code represents a key press or release, and how to handle special cases like Pause or Print Screen.

Define the scancode-to-HID mapping in `scancode_map.h`, creating a lookup table that translates each scancode to its corresponding USB HID keycode. This simple mapping handles the bulk of translation, with the state machine managing sequence assembly complexity.

Document the scancode set completely in `README.md`, including tables showing every scancode's meaning, the prefix conventions, and examples of multibyte sequences. This documentation becomes invaluable when debugging why a specific key doesn't work correctly.

Test exhaustively with hardware—press every key to verify correct translation, test all modifier combinations to catch mapping errors, validate that extended keys work properly, and confirm that special sequences like Pause and Print Screen generate correct HID codes.

Reference implementations demonstrate the patterns. The [Scancode Set 2](../scancodes/set2.md) implementation handles AT/PS2 with E0 and F0 prefixes. [Scancode Set 1](../scancodes/set1.md) shows simple make/break codes without prefixes. The [Amiga scancode processor](../scancodes/amiga.md) demonstrates 7-bit protocol-specific codes. The [combined Set 1/2/3 processor](../scancodes/set123.md) handles keyboards that can switch sets dynamically.

The [Scancode Sets documentation](../scancodes/README.md) provides detailed documentation for each set, whilst [HID keycodes](../../src/common/lib/hid_keycodes.h) defines all available USB HID codes for mapping.

---

### Build System

Understanding the build system helps when adding keyboards or debugging configuration issues (see [Advanced Topics - Build System](../advanced/build-system.md) for architectural details). The build flow transforms a keyboard name into a complete firmware binary tailored for that specific model.

The Docker environment provides: `docker compose run --rm -e KEYBOARD="modelm/enhanced" builder`. This command sets the `KEYBOARD` environment variable, which points to a configuration file at [`src/keyboards/`](../../src/keyboards/)`<brand>/<model>/keyboard.config`. The configuration file defines the protocol (`PROTOCOL=at-ps2`), scancode set (`CODESET=set123`), and other keyboard-specific parameters. CMake reads this configuration and automatically includes the appropriate protocol handler, scancode processor, and keymap files. The build outputs `build/rp2040-converter.uf2` ready for drag-and-drop flashing, along with `.elf` and `.elf.map` files for debugging.

For local development without Docker, initialise the Pico SDK submodule (`git submodule update --init --recursive`), configure the build directory (`cmake -B build`), and compile (`cmake --build build`). The local build path requires the Pico SDK and ARM toolchain installed manually, but provides faster iteration when actively developing.

Build resources include the [Building Firmware guide](../getting-started/building-firmware.md) for step-by-step procedures, [`CMakeLists.txt`](../../src/CMakeLists.txt) for build logic, [Docker setup](../../docker-compose.yml) for environment configuration, and [`keyboard.config` format examples](../../src/keyboards/modelm/enhanced/keyboard.config).

---

## Architecture Deep Dives

### Critical Architecture Rules

Before writing any code, read the [Code Standards](code-standards.md) documentation completely. This isn't a suggestion—it's the authoritative source for architectural constraints that must never be violated. Every architectural decision traces back to achieving precise timing with deterministic latency.

The five absolute prohibitions exist for specific technical reasons. No blocking operations (`sleep_ms`, `sleep_us`, `busy_wait_us`, `busy_wait_ms`) because the main loop must service the ring buffer and USB stack continuously—protocols require precise timing that blocking operations destroy. No multicore APIs (`multicore_*`, `core1_*`) because Core 1 stays disabled—the single-core architecture eliminates synchronisation complexity whilst delivering predictable latency. No `printf` in IRQ context because printf uses DMA-driven UART that conflicts with interrupt handlers—use `LOG_*` macros instead, which implement interrupt-safe buffering. No `ringbuf_reset()` with interrupts enabled because the lock-free SPSC design breaks if both pointers reset whilst an interrupt might be writing—only reset during initialisation or within explicit interrupt-disabled sections. No Flash execution because flash cache misses introduce unpredictable latency—code must run from SRAM using `copy_to_ram` to guarantee deterministic timing.

Understanding the "why" behind each rule helps you write compliant code naturally rather than fighting constraints. See [Advanced Topics](../advanced/README.md) for complete architecture documentation, [Code Standards](code-standards.md) for authoritative rules, and the [main loop implementation](../../src/main.c) for reference patterns.

---

### Ring Buffer Implementation

The ring buffer implements the critical handoff between interrupt context (where scancodes arrive) and the main loop (where they're processed). This lock-free single-producer/single-consumer (SPSC) design achieves thread-safety without locks, atomics, or blocking operations.

The 32-byte capacity (defined as `RINGBUF_SIZE` in [ringbuf.h](../../src/common/lib/ringbuf.h)) handles burst typing without overflow because the main loop polls frequently. The interrupt handler acts as the sole producer, writing to the head pointer. The main loop acts as the sole consumer, reading from the tail pointer. This strict separation means each context owns one pointer exclusively, eliminating concurrent modification possibilities.

Usage follows a clear pattern. In IRQ context (producer): read data from hardware, check if buffer is full using `ringbuf_is_full()`, then add to buffer with `ringbuf_put()` if space exists. In main loop context (consumer): check if buffer has data using `ringbuf_is_empty()`, then retrieve with `ringbuf_get()` if data exists, and process the scancode.

Three operations are strictly forbidden: never read from IRQ context (only write), never write from main loop (only read), and never call `ringbuf_reset()` with interrupts enabled. Violating these rules corrupts buffer state and causes dropped or duplicate scancodes. See [`src/common/lib/ringbuf.c`](../../src/common/lib/ringbuf.c) and [`ringbuf.h`](../../src/common/lib/ringbuf.h) for implementation details.

---

### PIO Programming

The RP2040's Programmable I/O subsystem provides eight independent state machines (four per PIO block) that execute custom assembly programs. These aren't general-purpose processors—they're specialised for GPIO manipulation with a minimal instruction set focused on bit shifting, pin waiting, and conditional jumps. This specialisation enables precise protocol timing without CPU involvement.

PIO handles protocol bit timing by monitoring clock edges and sampling data at precisely the right moment, frame synchronisation by detecting start/stop conditions and assembling complete bytes, clock generation when protocols require the host to provide timing signals, and edge detection with precision that software interrupt handlers can't achieve.

Rather than studying simplified examples, examine the real implementations to understand production-quality PIO programming. The [AT/PS2 PIO program](../../src/protocols/at-ps2/interface.pio) demonstrates bidirectional communication with clock synchronisation. The [XT PIO program](../../src/protocols/xt/keyboard_interface.pio) shows simple unidirectional receive with minimal state. The [Amiga PIO program](../../src/protocols/amiga/keyboard_interface.pio) implements handshake timing for synchronous protocols. The [M0110 PIO program](../../src/protocols/apple-m0110/keyboard_interface.pio) handles variable-timing protocols that adapt to signal conditions.

Additional PIO resources include the [PIO helper library](../../src/common/lib/pio_helper.c) and [header](../../src/common/lib/pio_helper.h) for loading and managing PIO programs, the [Advanced Topics](../advanced/README.md) for architectural context, and the [RP2040 Datasheet](https://datasheets.raspberrypi.com/rp2040/rp2040-datasheet.pdf) PIO specification for complete instruction set reference.

---

## Documentation

### Documentation Structure

The project maintains separate public and private documentation with clear boundaries. Public documentation (everything in `docs/`, `README.md` files, and source code comments) gets committed to version control and appears in the repository. This includes user guides, protocol specifications, architecture documentation, and development guides—anything that helps users or contributors understand and work with the project.

Private documentation (`docs-internal/`) stays local and never gets committed. This directory holds development notes, investigation findings, performance analysis, architecture decision records, and other working documents that inform development but don't need public visibility. Git hooks and lint checks actively prevent committing these files, and referencing them in public documentation triggers build failures.

The separation serves an important purpose: docs-internal provides a space for thorough investigation and analysis without worrying about polish or completeness, whilst public docs maintain high standards for accuracy and clarity. You can freely use docs-internal as a reference source during development—it often contains detailed findings and historical context that inform decisions. Just extract relevant information into properly formatted public documentation rather than linking to the private files.

Documentation resources include the project structure documented across multiple guides, the main [README](../../README.md) providing project overview, and comprehensive guides in [Getting Started](../getting-started/README.md), [Protocols](../protocols/README.md), and [Features](../features/README.md) directories.

---

## Git Workflow

### Branch Naming

Branch names follow conventional commit prefixes to indicate the type of work: `feat/add-new-protocol` for new features, `fix/at-ps2-timing` for bug fixes, `docs/protocol-guide` for documentation updates, `refactor/simplify-ringbuf` for code restructuring, and `test/add-unit-tests` for testing additions. This convention makes the branch purpose immediately clear in the branch list and Pull Request interface.

---

### Commit Messages

Commit messages follow the conventional commits format to maintain a clear, parseable history. The format includes a type prefix (`feat`, `fix`, `docs`, `refactor`, `test`, or `chore`), a colon, and a short description that completes the sentence "This commit will...". The optional body provides additional context about what changed and why. The optional footer references related issues or indicates breaking changes.

Good commit messages explain both what changed and why the change was necessary. "feat: Add support for Amiga protocol" tells you what, whilst the body explains "Implements Amiga keyboard protocol with handshake timing and Caps Lock synchronisation via pulse." Reference related issues in the footer using "Closes #42" for features or "Fixes #38" for bug fixes—this automatically links commits to issues and closes them when merged.

For bug fixes, explain the incorrect behaviour and what caused it, not just what code changed: "Device was not responding correctly to LED commands. Fixed timing to match specification (10-16.7 kHz clock). Fixes #38" tells the complete story.

---

### Pull Request Template

The pull request template (`.github/PULL_REQUEST_TEMPLATE.md`) provides structure for describing changes comprehensively. Sections include the change description explaining what you've modified and why it matters, an architecture checklist confirming you've read the code standards and followed all critical rules, testing performed detailing how you've verified the changes work correctly, breaking changes noting any incompatibilities with previous versions, and documentation updated confirming you've revised relevant guides.

Requirements for all PRs include lint script passing with zero errors and warnings, build tests passing for at least one configuration (preferably multiple if your changes affect protocols), hardware testing with actual keyboards when changes affect protocol or keyboard support, and documentation updated to reflect any new behaviour or configuration options.

---

## Tools & Enforcement

### Lint Script

The lint script (`./tools/lint.sh`) provides automated checking for architectural violations before commits reach CI. Run it before every commit—it must pass with zero errors and zero warnings, or the PR will be rejected.

The script scans for blocking operations (`sleep_ms`, `busy_wait_us`, etc.), multicore API usage (`multicore_*`, `core1_*` functions), `printf` calls in interrupt context (which cause DMA conflicts), references to `docs-internal` in public files (which would expose local-only documentation), and ring buffer safety violations (like calling `ringbuf_reset()` without proper guards).

`./tools/lint.sh` checks all source files, or `./tools/lint.sh src/main.c` checks a specific file. The script returns exit code 0 on pass, 1 when errors are found, and 2 when warnings are present. CI integration ensures all pull requests pass lint checks before merge consideration.

---

### CodeRabbit

Automated pull request reviews through CodeRabbit provide AI-assisted analysis focusing on embedded systems best practices and architectural compliance. The bot reviews every PR, highlighting potential issues with blocking operations, memory safety, protocol timing, and adherence to architectural patterns.

CodeRabbit configuration defines path-specific instructions (different rules for protocols vs keyboards vs common libraries), custom pre-merge checks (must pass lint, must compile all configurations, must respect memory limits), and knowledge base integration ensuring reviews align with project architecture.

Custom checks flag potential architectural issues for review: no blocking operations anywhere in the code, no multicore usage attempts, interrupt safety for all shared data structures, RAM execution requirements met, and checks for patterns or anti-patterns related to protocol timing that warrant manual verification. These checks are heuristic; they raise issues for further testing and review rather than proving timing correctness.

---

## Related Documentation

**Architecture:**

- [Advanced Topics](../advanced/README.md) - Complete system architecture, performance analysis, PIO programming, critical design principles
- [Code Standards](code-standards.md) - Authoritative architectural constraints and rules

**Implementation:**

- [Protocol Implementation](protocol-implementation.md) - Guide to implementing a new keyboard protocol
- [Protocol Overview](../protocols/README.md) - Protocol specifications and signal details
- [Keyboard Configuration](../keyboards/README.md) - Supported keyboards and configuration format
- [Features](../features/README.md) - Command Mode, Config Storage, LED Support, Logging, Mouse Support, USB HID

**Project:**

- [Main README](../../README.md) - Project overview and quick start
- [License](../../LICENSE) - MIT License terms

---

**Questions or stuck on something?**
Use [GitHub Discussions](https://github.com/PaulW/rp2040-keyboard-converter/discussions) or [open an issue](https://github.com/PaulW/rp2040-keyboard-converter/issues) if you've found a problem.

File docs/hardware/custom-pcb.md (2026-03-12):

# Custom PCB Design

When I found an IBM Model F PC/AT keyboard (model 6450225) in my parents' attic, I knew I wanted to convert it properly—not with an external adapter and messy cables, but with something that'd fit neatly inside the case. This custom PCB is the result of that project, and I'm sharing the design files and documentation here in case anyone else wants to build their own.

## Table of Contents

- [Custom PCB Design](#custom-pcb-design)
  - [Table of Contents](#table-of-contents)
  - [Why Build a Custom PCB?](#why-build-a-custom-pcb)
  - [Design and Specifications](#design-and-specifications)
  - [PCB Layout](#pcb-layout)
    - [PCB Trace Design (Top)](#pcb-trace-design-top)
    - [PCB Trace Design (Bottom)](#pcb-trace-design-bottom)
    - [2D PCB Render (Top)](#2d-pcb-render-top)
    - [2D PCB Render (Bottom)](#2d-pcb-render-bottom)
    - [3D PCB Render (Top)](#3d-pcb-render-top)
    - [3D PCB Render (Bottom)](#3d-pcb-render-bottom)
  - [Manufacturing](#manufacturing)
    - [Manufactured PCBs](#manufactured-pcbs)
  - [Installation](#installation)
    - [Installed Converter Board](#installed-converter-board)
    - [Fully Assembled Board](#fully-assembled-board)
  - [Design Iterations](#design-iterations)
  - [Fabrication Files](#fabrication-files)
  - [Related Documentation](#related-documentation)

---

## Why Build a Custom PCB?

The breadboard prototype worked perfectly well for testing, but it's not something you'd want to live with long-term. A custom PCB solves several problems:

**What it gives you:**

- Everything on one neat board—no loose wiring inside the keyboard
- Fits in the available space without modifying the case
- Only the USB cable exits the keyboard (looks stock from the outside)
- Proper level shifting built in (no separate modules)
- Reliable connections that won't work loose

**What it includes:**

- RP2040 microcontroller
- Bi-directional level shifters (5V ↔ 3.3V)
- USB Type-C connector
- Power regulation (3.3V LDO), decoupling capacitors, and crystal oscillator (12MHz)

---

## Design and Specifications

I designed this in EasyEDA, which is free and has decent integration with JLCPCB's manufacturing service. The board measures 40×30mm—specifically designed to fit inside the IBM Model F PC/AT (model 6450225) and mount using the existing screw holes on the internal frame.

**What's on the board:**

- **RP2040 microcontroller** - Same chip as the Raspberry Pi Pico
- **Level shifters** - BSS138 MOSFETs for bi-directional 5V ↔ 3.3V translation
- **USB Type-C connector** - Much nicer than Micro-B
- **Power regulation** - 3.3V for the RP2040 from USB 5V
- **Decoupling capacitors** - Standard RP2040 requirements
- **Crystal oscillator** - 12MHz for USB timing

**GPIO connections:**

- Keyboard CLOCK: GPIO 17
- Keyboard DATA: GPIO 16
- Status LED: GPIO 25 (built-in RP2040 LED)
- USB: Native RP2040 USB (uses dedicated USB D+/D− pins — not GPIO 20/21)

The PCB is 1.6mm thick (standard), 1oz copper, with HASL lead-free finish. Nothing exotic—just bog-standard PCB specs that any manufacturer can handle.

---

## PCB Layout

Here's what the design looks like. I went through a couple of revisions before settling on this layout—the first attempt had terrible component placement and didn't fit the keyboard properly.

### PCB Trace Design (Top)

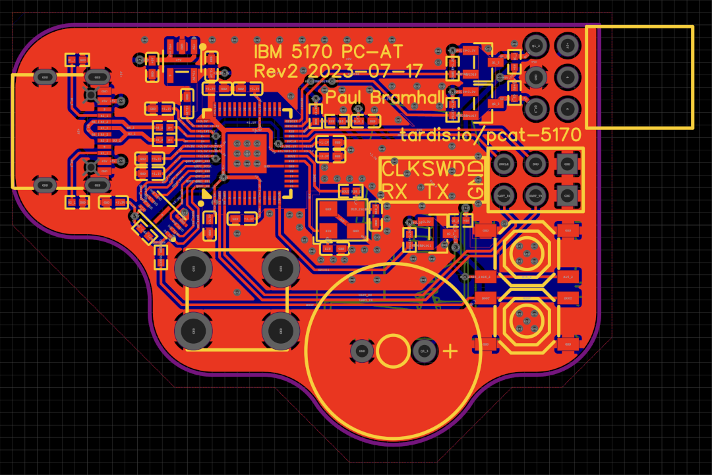
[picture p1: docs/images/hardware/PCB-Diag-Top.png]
PCB Trace Top


### PCB Trace Design (Bottom)

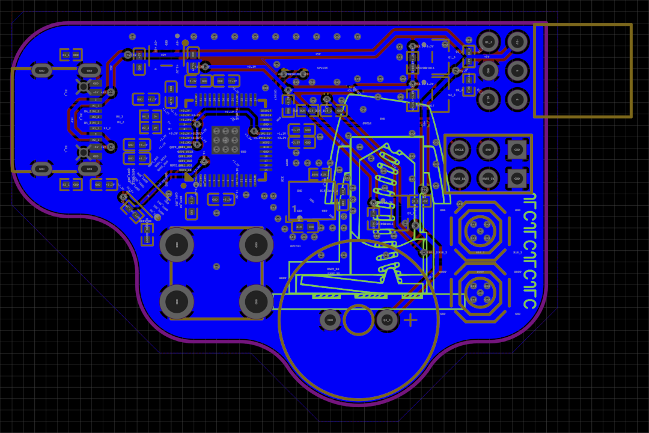
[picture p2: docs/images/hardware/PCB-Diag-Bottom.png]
PCB Trace Bottom


### 2D PCB Render (Top)

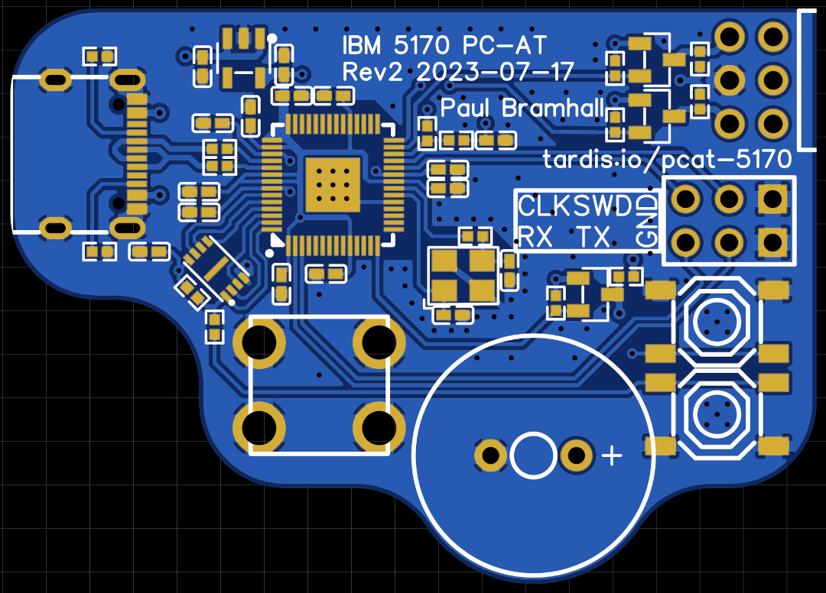
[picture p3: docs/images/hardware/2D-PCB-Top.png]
2D PCB Top


### 2D PCB Render (Bottom)

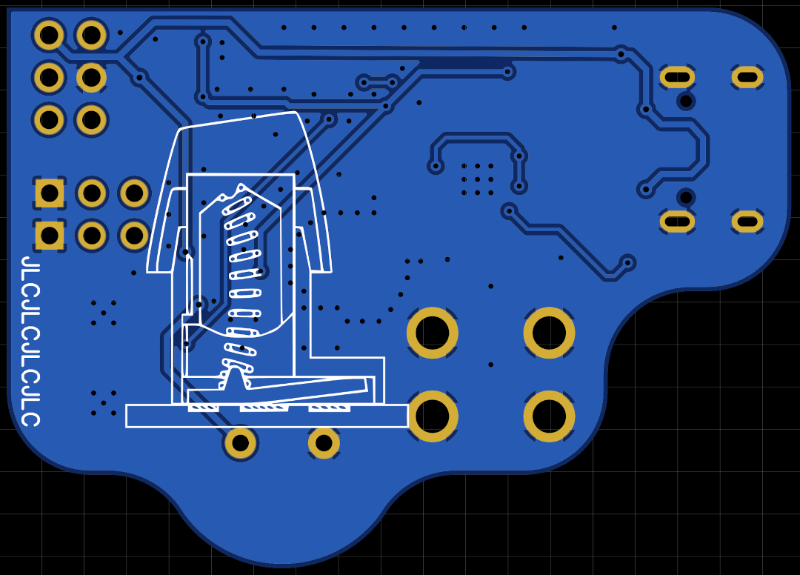
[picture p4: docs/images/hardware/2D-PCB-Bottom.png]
2D PCB Bottom


### 3D PCB Render (Top)

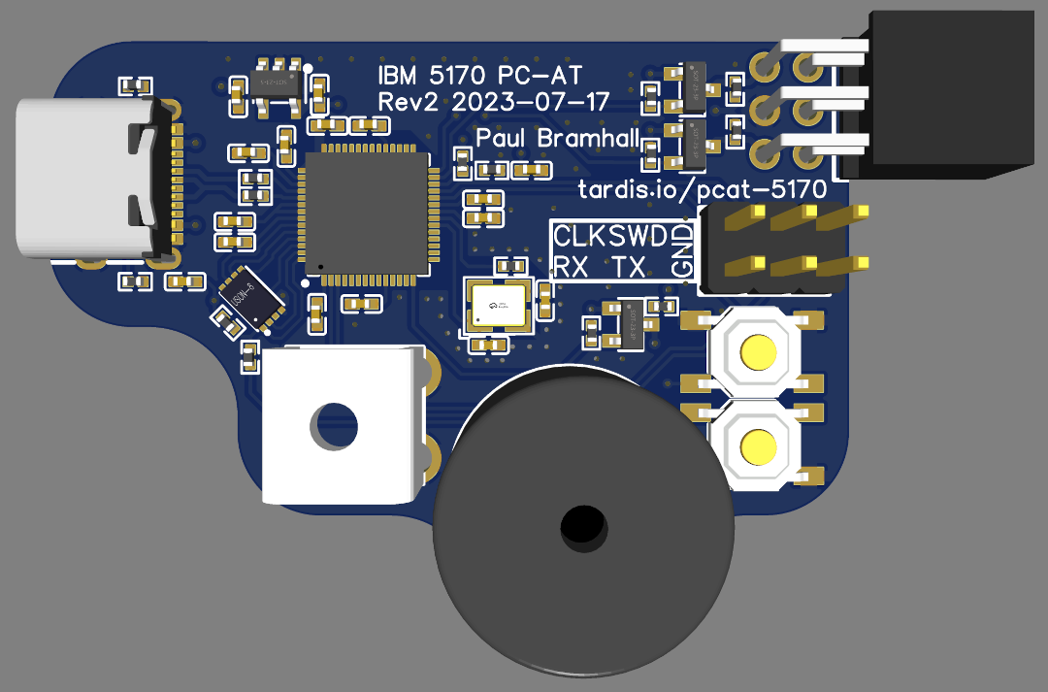
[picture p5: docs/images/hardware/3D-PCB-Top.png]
3D PCB Top


### 3D PCB Render (Bottom)

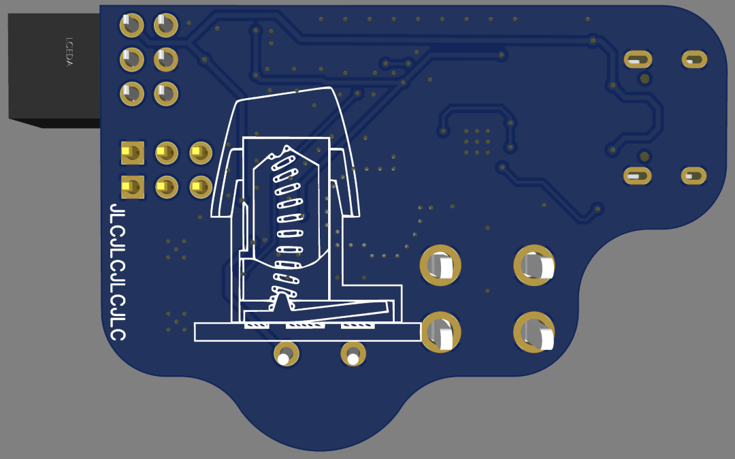
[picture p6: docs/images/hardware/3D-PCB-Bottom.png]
3D PCB Bottom


---

## Manufacturing

I used JLCPCB for fabrication and assembly. Their SMT assembly service lets you upload your Gerber files, BOM, and pick-and-place file, and they'll build the boards for you.

### Manufactured PCBs

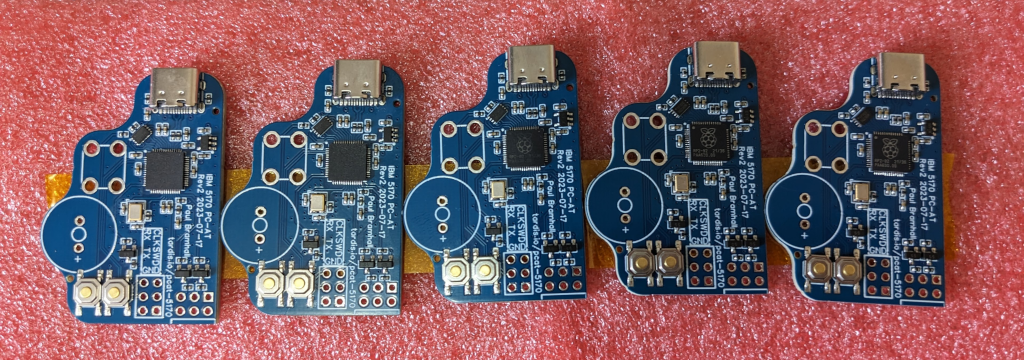
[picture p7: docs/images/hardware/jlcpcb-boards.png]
Manufactured PCBs from JLCPCB


**The process:**

1. Upload Gerber files to JLCPCB
2. Select PCB specs (1.6mm, 1oz copper, HASL lead-free)
3. Enable SMT assembly service
4. Upload BOM and pick-and-place files
5. Review component availability (some might be out of stock)
6. Confirm and order

**What you get:**
Minimum order is 5 PCBs. Pricing and lead times vary — check the JLCPCB website for current figures.

---

## Installation

### Installed Converter Board

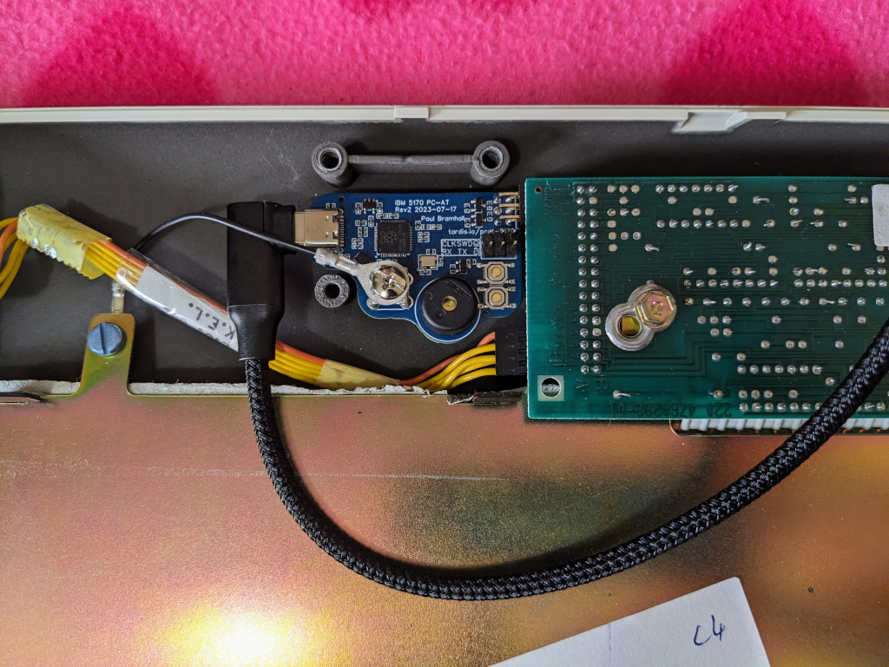
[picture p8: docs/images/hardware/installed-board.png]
Installed converter inside keyboard


Installing the board is simple—it mounts on the keyboard's internal frame, so you're not drilling or modifying anything permanent.

**Steps:**

1. Open the keyboard case (see my [separate case video](https://www.paulbramhall.uk/bits-n-bobs/keyboards/1986-ibm-model-f-at/separating-the-case-of-the-ibm-model-f-at/) if you need help with this—it's a bit tricky)
2. Locate the keyboard controller board
3. Remove the existing cable from the controller
4. Connect the converter to the controller's output connector
5. Attach the Ground cable from the backplate to the converter board
6. Route the USB cable through the existing cable channel
7. Close the case

From the outside, it looks completely stock. The only giveaway is the USB-C cable instead of the original DIN-5 connector.

### Fully Assembled Board

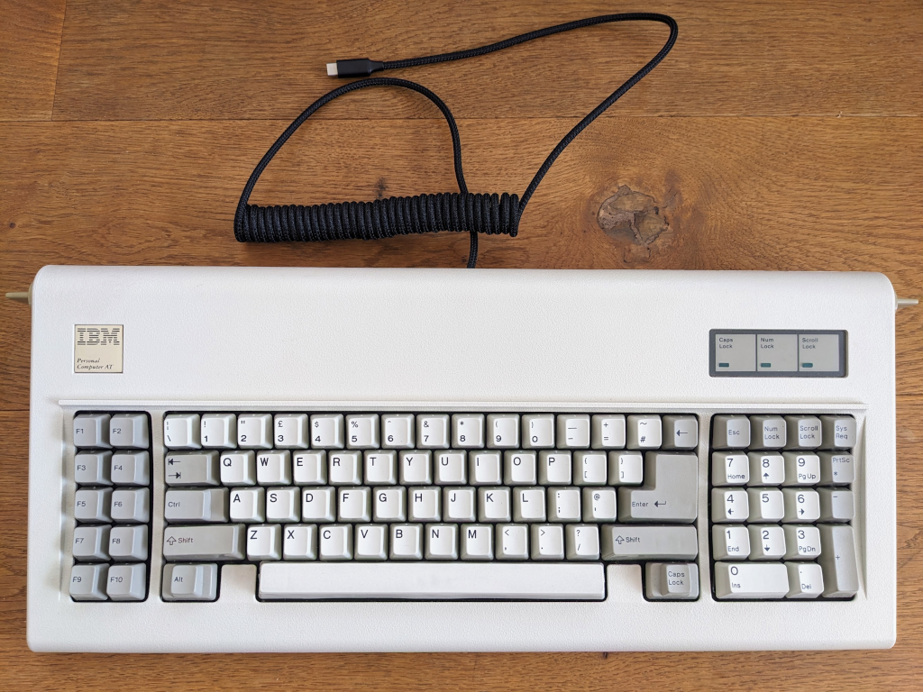
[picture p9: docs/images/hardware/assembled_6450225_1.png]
Fully assembled converter board


---

## Design Iterations

This is actually Revision 2 of the design. The first version was more of a test-fit to get measurements—the component placement was terrible, and it didn't fit the keyboard case properly. Live and learn.

**Changes in Rev 2:**

- Completely redid component placement
- Optimised trace routing (fewer vias, cleaner layout)
- Adjusted board outline to fit the case better
- Added proper level shifter circuit (Rev 1 didn't have this)

If you're using the fabrication files, you're getting Rev 2—that's the current version that actually works properly.

---

## Fabrication Files

All the files you need to manufacture this PCB are in the [`fabrication/`](fabrication/) directory:

**What's included:**

- **[Schematic (PDF)](../images/hardware/Schematic.pdf)** - Complete electrical schematic
- **Gerber files** - PCB manufacturing files (what the manufacturer uses to make the boards)
- **BOM (Bill of Materials)** - Component list with JLCPCB part numbers
- **Pick-and-Place** - Component placement coordinates for SMT assembly
- **EasyEDA project files** - If you want to modify the design

**Using these files:**
The Gerber, BOM, and pick-and-place files are what you'll upload to JLCPCB (or any other manufacturer). The schematic is there for reference if you want to understand how it works or make modifications.

If you're ordering from JLCPCB, their website walks you through the process pretty clearly. You'll need to review the component availability—sometimes parts go out of stock, and you might need to find substitutes.

---

## Related Documentation

**For building your first converter:**

- **[Hardware Overview](README.md)** - General hardware guide and component selection
- **[Getting Started Guide](../getting-started/hardware-setup.md)** - Breadboard wiring for testing

**Keyboard-specific:**

- User-facing documentation: [IBM Model F PC/AT](../keyboards/ibm/model-f-pcat.md)
- Source code configuration: [`src/keyboards/modelf/pcat/`](../../src/keyboards/modelf/pcat/)

**External resources:**

- [EasyEDA](https://easyeda.com/) - Free PCB design tool (what I used)
- [JLCPCB](https://jlcpcb.com/) - PCB manufacturer with SMT assembly
- [RP2040 Datasheet](https://datasheets.raspberrypi.com/rp2040/rp2040-datasheet.pdf) - If you want to modify the design

---

**Questions or stuck on something?**
Use [GitHub Discussions](https://github.com/PaulW/rp2040-keyboard-converter/discussions) or [open an issue](https://github.com/PaulW/rp2040-keyboard-converter/issues) if you've found a problem.

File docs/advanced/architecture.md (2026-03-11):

# System Architecture

If you're wanting to understand how everything fits together inside the converter—whether you're debugging timing issues, adding a new protocol, or just curious—this should give you a decent overview of what's going on under the hood.

I won't dive into every single implementation detail here (that's what the source code's for), but I'll cover the key pieces and how they all connect together.

---

## The Big Picture

The converter's built around a single-core architecture running entirely from SRAM. Everything happens on Core 0 of the RP2040, with Core 1 sitting idle. This keeps things simple and avoids all the complexity of synchronising between cores.

The whole design is focused on keeping latency as low as possible whilst making sure nothing blocks. There's no `sleep_ms()` calls or busy-waiting anywhere in the main pipeline—everything uses state machines that check timestamps to see if enough time's passed. This means the main loop runs continuously without ever stalling.

**Why SRAM execution?** The RP2040's Flash memory has variable access latency due to caching, which isn't ideal when you need deterministic timing for protocol handling. Running the entire program from SRAM eliminates that overhead and gives us predictable execution timing. It does mean we're more constrained on code size, but for what we're doing it's absolutely worth the trade-off.

---

## How Data Flows Through the System

When you press a key on your keyboard, here's the journey it takes before it appears on your computer—it will differ slightly depending on the protocol and keyboard, but the general flow looks like this:

```text
┌──────────────┐
│ Physical Key │  You press a key
│    Press     │
└──────┬───────┘
       │
       ▼
┌──────────────────────────┐
│   PIO State Machine      │  Hardware captures clock/data signals
│  (Protocol Timing)       │  Assembles bits into scancode bytes
└──────┬───────────────────┘
       │
       ▼
┌──────────────────────────┐
│   Interrupt Handler      │  PIO fires an interrupt when byte's ready
│   (IRQ Context)          │  Extracts scancode, writes to ring buffer
└──────┬───────────────────┘
       │
       ▼
┌──────────────────────────┐
│   Ring Buffer (32 bytes) │  Lock-free FIFO queue
│   (Shared Memory)        │  IRQ writes, main loop reads
└──────┬───────────────────┘
       │
       ▼
┌──────────────────────────┐
│  Scancode Processor      │  Handles multibyte sequences
│  (Main Loop - CPU)       │  Deals with E0/F0 prefixes, Pause key
└──────┬───────────────────┘
       │
       ▼
┌──────────────────────────┐
│  Keymap Translation      │  Maps scancode → HID keycode
│  Command Mode Handler    │  Detects command key combinations
└──────┬───────────────────┘
       │
       ▼
┌──────────────────────────┐
│    HID Interface         │  Assembles HID report
│    (Main Loop)           │  Waits for tud_hid_ready()
└──────┬───────────────────┘
       │
       ▼
┌──────────────────────────┐
│   TinyUSB Stack          │  USB communication with host
│   (USB Callbacks)        │  8ms polling interval
└──────┬───────────────────┘
       │
       ▼
┌──────────────┐
│  Host OS     │  Key appears on your computer
│  Receives    │
└──────────────┘
```

The pipeline's deliberately non-blocking throughout—everything's either hardware-driven (PIO handles protocol timing) or poll-based in the main loop. The USB host polls every 8ms (configured by `bInterval` in usb_descriptors.c), which becomes the main bottleneck for maximum throughput. The actual processing (scancodes, keymap translation, HID report assembly) happens quickly enough that USB polling is the limiting factor.

---

## The Main Components

### PIO State Machines

The RP2040's Programmable I/O blocks are doing the heavy lifting for protocol timing. These are dedicated hardware state machines that can bit-bang protocols with precise timing, completely independently of what the CPU's doing.

Each protocol has its own PIO program—effectively a tiny assembly program that runs on the PIO hardware. These programs handle the clock and data line timing, shifting in bits, and assembling them into scancode bytes. When a complete byte's ready, the PIO fires an interrupt to let the CPU know there's data waiting.

**Why use PIO rather than GPIO interrupts?** Timing. These protocols need precise sampling of data lines relative to clock edges. Doing that reliably in software on the CPU would be difficult—you'd need to handle other interrupts, and interrupt latency can vary. The PIO hardware handles this deterministically, freeing the CPU to focus on higher-level processing.

The PIO programs are written in `.pio` files (PIO assembly), which get compiled into header files during the build. If you're adding a new protocol, you'll likely need to write a PIO program that understands that protocol's timing.

### Interrupt Handlers

When the PIO completes receiving a scancode byte, it fires an interrupt. The interrupt handler's job is pretty simple: grab the byte from the PIO, do any pre-processing or validation steps of the data before writing it to the ring buffer, and get out as fast as possible.

**Critical rule:** Interrupt handlers must be non-blocking and fast. No `printf()`, no `sleep_ms()`, no loops. Just read the data, write it to the buffer, and return.

The ring buffer write is lock-free—the IRQ is the only producer (writes to `head`), whilst the main loop is the only consumer (writes to `tail`). This means no mutexes or critical sections needed. We do use `volatile` qualifiers and memory barriers (`__dmb()`) to ensure visibility between contexts, but that's it.

### Ring Buffer

The ring buffer's a 32-byte FIFO queue that sits between the interrupt handler and the main loop. It's sized to handle bursts of scancodes from fast typing without overflowing.

**Why 32 bytes?** It's a power of two (which makes the modulo arithmetic cheap), and it's large enough to buffer several scancodes during worst-case scenarios. In practice, the main loop processes scancodes fast enough that the buffer rarely gets more than a few bytes deep.

The buffer uses a single-producer/single-consumer model:

- **Producer (IRQ):** Writes new scancodes, increments `head` pointer
- **Consumer (Main loop):** Reads scancodes, increments `tail` pointer

When `head == tail`, the buffer's empty. When `(head + 1) % 32 == tail`, it's full. The implementation's lock-free because only one context writes each pointer.

One thing to watch out for: you can't call `ringbuf_reset()` whilst interrupts are enabled. That would break the single-writer invariant. Resets only happen during initialisation or state machine resets where the protocol handler's already disabled interrupts. All keyboard protocols follow a standard setup pattern that includes `ringbuf_reset()` before enabling interrupts—see the [Protocol Implementation Guide](../development/protocol-implementation.md) for details.

### Scancode Processor

Not all scancodes are single bytes. Some protocols (like AT/PS2 Scancode Set 2) use multibyte sequences—escape prefixes like `E0` and `F0` (for extended keys and key releases), and even longer sequences like the Pause key which sends `E1 14 77 E1 F0 14 F0 77`.

The scancode processor runs in the main loop on the CPU (not in the PIO—the PIO only handles bit-level protocol timing). It reads bytes from the ring buffer and assembles them into complete scancode events. Once it's got a complete sequence, it knows whether it's a make (key press) or break (key release), and what the actual scancode is.

Each protocol can have its own scancode processor implementation, since the rules differ between Scancode Set 1, Set 2, Set 3, and the various other protocols. The processor's responsible for maintaining state across bytes and figuring out when a complete event's ready. Documentation for these is in [docs/scancodes/](../scancodes/README.md), with source implementations in [`src/scancodes/`](../../src/scancodes/).

### Keymap Translation

Once we've got a complete scancode (make or break), we need to translate it into a USB HID keycode. That's where the keyboard-specific keymaps come in.

Each keyboard configuration has a keymap—a lookup table that maps scancodes to HID keycodes. The keymap's defined in the keyboard's `keyboard.c` file using macros like `KEYMAP_ANSI()` or `KEYMAP_ISO()` that match the physical layout of the keyboard.

This is also where Command Mode detection happens. Before we send a key event to the HID interface, Command Mode checks if you're holding down the activation keys (default: both shifts). If you are, it starts monitoring for command key presses instead of sending them as normal keystrokes.

### HID Interface

The HID interface takes HID keycodes from the keymap translation and assembles them into USB HID reports. These reports describe which keys are currently pressed, which modifiers are active, and so on.

**Important quirk:** We can only send a HID report when `tud_hid_ready()` returns true. This function checks whether the USB host is ready to accept more data. The host polls USB devices every 8ms (configured by `bInterval` in usb_descriptors.c), so there's a natural rate limit here—we're often waiting for the USB host to be ready before we can send the next report.

The HID interface maintains the current keystroke state (which keys are pressed) and only sends reports when something changes. This reduces unnecessary USB traffic and keeps things efficient.

### TinyUSB Stack

TinyUSB handles all the low-level USB communication—enumeration, descriptor handling, endpoint management, and so on. It's a well-tested, mature USB stack that runs on lots of different microcontrollers, including the RP2040.

We're using it in device mode, where the RP2040 acts as a USB HID keyboard and mouse. TinyUSB handles all the USB protocol details, and we just interface with it through a few callbacks and functions like `tud_hid_keyboard_report()` and `tud_hid_mouse_report()`.

---

## Memory Layout

The RP2040 has 264KB of SRAM. Actual usage depends on build configuration (which protocols and keyboards are compiled in), leaving plenty of headroom. The exact usage varies based on which features you've enabled. The linker reports precise memory consumption during build.

**Flash usage** also depends on configuration. The RP2040's got 2MB of Flash, so there's no shortage of space. CI limits enforce maximum 230KB flash and 150KB RAM (see [.github/workflows/ci.yml](../../.github/workflows/ci.yml)).

**Critical detail:** Even though the code's stored in Flash, it's copied to SRAM at boot time and executed from there. This is enforced by the build system (`pico_set_binary_type(copy_to_ram)` in CMakeLists.txt) and verified at compile time by a `#error` check in `main.c` if you accidentally build for Flash execution. SRAM execution's faster and more reliable for this kind of real-time work.

---

## Execution Contexts

There are three main execution contexts in the converter:

### Interrupt Context (IRQ Handlers)

This is where the PIO interrupt handlers run when the hardware has data ready. IRQ context has the highest priority—it can preempt the main loop at any time.

**Rules for IRQ context:**

- Must be fast
- No blocking operations (`sleep_ms`, `busy_wait_us`, etc.)
- No `printf()` or other UART operations (use `LOG_*` macros which are DMA-safe)
- No complex processing—just queue data and return
- Use `volatile` and memory barriers for shared data

The interrupt handlers in this project follow these rules strictly. They extract scancodes from the PIO, write them to the ring buffer, and return. That's it.

### Main Loop Context

The main loop runs continuously, processing queued scancodes, managing protocol state, and sending USB HID reports.

The main loop never blocks. All time-based operations use `to_ms_since_boot(get_absolute_time())` to check if enough time's passed, rather than sleeping. This keeps the loop responsive and ensures we can handle bursts of scancodes without delay.

**Typical main loop iteration:**

1. Check ring buffer for new scancodes
2. Process any scancodes through the scancode processor
3. Run protocol state machine tasks (initialisation, LED commands, etc.)
4. Check Command Mode state
5. If there's a HID event and USB is ready, send report
6. Handle mouse events if mouse support's enabled
7. Run TinyUSB stack tasks
8. Repeat

### USB Callback Context

TinyUSB calls back into our code from USB interrupt context when USB events happen (enumeration, configuration, control requests, etc.). These callbacks need to be fast and non-blocking, similar to the protocol interrupt handlers.

USB callbacks in this implementation set flags or copy small amounts of data. The bulk of USB processing happens in the main loop when we call `tud_task()`.

---

## Thread Safety and Synchronisation

We use a few different patterns to ensure data stays consistent across execution contexts:
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

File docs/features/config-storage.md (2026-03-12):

# Configuration Storage

The converter needs to remember certain settings between power cycles—things like your preferred log level or LED brightness. This page explains how those settings are stored reliably in the RP2040's internal flash memory, and why the system is designed to protect your configuration even if power is lost during a write operation.

---
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

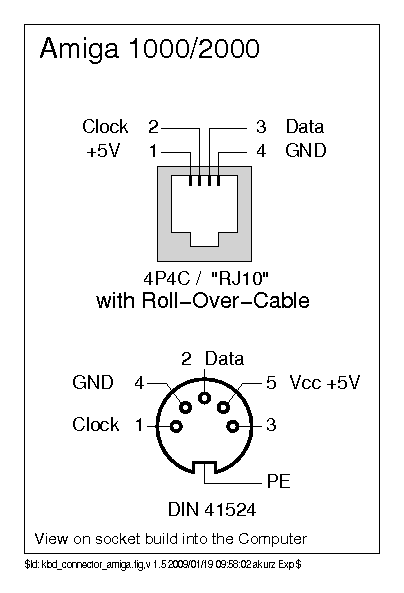
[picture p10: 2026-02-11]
docs/images/connectors/kbd_connector_amiga.png

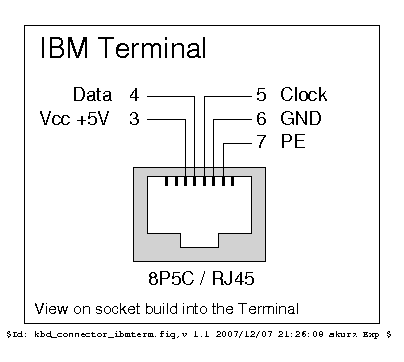
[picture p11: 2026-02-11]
docs/images/connectors/kbd_connector_ibmterm.png

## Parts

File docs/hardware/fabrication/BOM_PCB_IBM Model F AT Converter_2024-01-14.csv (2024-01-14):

ID | Name | Designator | Footprint | Quantity | Manufacturer Part | Manufacturer | Supplier | Supplier Part | Price
1 | 2*3P-RH | HEADER1 | HDR-TH_6P-P2.54-H-F-R2-C3-S2.54-W10.0 | 1 | 2.54-2*3P弯母 | BOOMELE(博穆精密) | LCSC | C56182 | 0.093
2 | 2x3P | HEADER2 | HDR-TH_6P-P2.54-V-R2-C3-S2.54_A2541WV-2X3P | 1 | 210-72-03GB01 | PINREX(频锐科技) | LCSC | C402781 | 0.027
3 | TPRT9013-33GB | U1 | SOT-23-5_L3.0-W1.7-P0.95-LS2.8-BL | 1 | TPRT9013-33GB | TECH PUBLIC(台舟) | LCSC | C587158 | 0.079
4 | TS-1187A-B-A-B | BOOT,RESET | SW-SMD_4P-L5.1-W5.1-P3.70-LS6.5-TL-2 | 2 | TS-1187A-B-A-B | XKB Connectivity(中国星坤) | LCSC | C318884 | 0.016
5 | TYPE-C 16PIN 2MD(073) | USB1 | USB-C-SMD_TYPE-C-6PIN-2MD-073 | 1 | TYPE-C 16PIN 2MD(073) | SHOU HAN(首韩) | LCSC | C2765186 | 0.053
6 | PS1420P02CT | BUZZER | BUZ-TH_BD14.0-P5.00-D0.7-FD | 1 | PS1420P02CT | TDK | LCSC | C91080
7 | 27pF | C1,C2 | C0402 | 2 | 0402CG270J500NT | FH(风华) | LCSC | C1557 | 0.001
8 | 100nF | C3,C5,C6,C7,C8,C9,C10,C11,C12,C13 | C0402 | 10 | CL05B104KO5NNNC | SAMSUNG(三星) | LCSC | C1525 | 0.001
9 | 1uF | C4,C15,C16,C17 | C0402 | 4 | CL05A105KA5NQNC | SAMSUNG(三星) | LCSC | C52923 | 0.004
10 | W25Q16JVUXIQ | FLASH | USON-8_L3.0-W2.0-P0.50-BL-EP | 1 | W25Q16JVUXIQ | WINBOND(华邦) | LCSC | C2843335 | 0.576
11 | 7691 | GND | CONN-TH_4P-P5.00-S7.00_L8.0-W8.0 | 1 | 7691 | Keystone | LCSC | C238163 | 0.969
12 | BSS138 | Q1,Q2,Q3 | SOT-23-3_L2.9-W1.3-P1.90-LS2.4-BR | 3 | BSS138 | CJ(江苏长电/长晶) | LCSC | C78284 | 0.022
13 | 5.1kΩ | R1,R2 | R0402 | 2 | 0402WGF5101TCE | UNI-ROYAL(厚声) | LCSC | C25905 | 0.001
14 | 22Ω | R3,R4 | R0402 | 2 | 0402WGF220JTCE | UNI-ROYAL(厚声) | LCSC | C25092 | 0.001
15 | 1kΩ | R16,R17,R18 | R0402 | 3 | 0402WGF1001TCE | UNI-ROYAL(厚声) | LCSC | C11702 | 0.001
16 | 10kΩ | R19,R20,R21,R22,R23,R24,R25,R26 | R0402 | 8 | 0402WGF1002TCE | UNI-ROYAL(厚声) | LCSC | C25744 | 0.001
17 | RP2040 | RP2040 | LQFN-56_L7.0-W7.0-P0.4-EP | 1 | RP2040 | Raspberry Pi(树莓派) | LCSC | C2040 | 1.076
18 | 12MHz | X1 | OSC-SMD_4P-L3.2-W2.5-BL | 1 | X322512MSB4SI | YXC(扬兴晶振) | LCSC | C9002 | 0.059

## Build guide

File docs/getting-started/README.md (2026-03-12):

# Getting Started

This guide will focus on getting you up and running quickly with a standard PS/2 keyboard connected to an RP2040 board. We'll try and keep things as simple yet comprehensive as possible.

## Why Convert Peripherals?

I've always preferred older keyboards and mice. Modern replacements are readily available, but I find older hardware more satisfying to use — I prefer the feel, weight, and solid construction that I just don't find in modern replacements I've tried.

I've always felt that older keyboards and mice have a certain charm and quality about them. The way they feel to use—even older membrane keyboards feel much more robust and solid compared to modern equivalents I've used (I weirdly like the feel of my Alps CL18821). To me, they just feel like they were built to last.

Also, with the popularity of older computers and retro gaming, there's a growing community of enthusiasts who appreciate the tech and want to use it with their modern systems.

## What Makes This Project Different? A Bit of History...

When I started looking into keyboard converters, the projects I came across—TMK, QMK, and Soarer's Converter—were built for AVR microcontrollers such as the ATmega32U4. I hadn't worked with AVR boards before, and was already exploring what I could do with the RP2040, so I decided to see if I could build something for that instead. With finding an old IBM Model F Keyboard in my parents loft, I thought it would be a fun challenge to see if I could build something using an RP2040 board instead (I wanted to learn more about how the PIO state machines worked, having already played about with the Raspberry Pi and its GPIO capabilities previously).

When I first started to look into building something to use my keyboard, the examples I could find were Atmel based, or using other controllers such as a Teensy. I did however then come across an article on Adafruit '[IBM PC Keyboard to USB HID with CircuitPython](https://learn.adafruit.com/ibm-pc-keyboard-to-usb-hid-with-circuitpython/overview)', and this was an invaluable resource to help me get started testing whether the keyboard I had still worked. Now I already had experience using Python from my job, so to start with this was a nice and easy way to understand how things worked, and also a really good guide to help me understand more about how to connect things up.

The main problem though for this, is that it wasn't really a simple 'plug-and-play' solution. The Adafruit example was designed for an XT Keyboard, and the one I had was a PC/AT (so a completely different protocol). Signalling was somewhat similar in how it worked, I just needed to adapt it slightly to handle the differences of the AT/PS2 protocol compared to that of the XT protocol. So for simply reading the data being sent from the keyboard, this was a great starting point.

The only thing I wasn't a fan of with this approach though, is that even though CircuitPython is great for easily prototyping things and getting them off the ground quickly, I felt it wasn't as optimal an approach for something I'd like to use long-term. So I decided to look into building something more from the ground up in C using the official Raspberry Pi Pico SDK. As (at the time) there wasn't really any existing projects or examples out there working in a way I was looking for, I decided to build my own firmware from scratch.

Now, there has since been work going on to support platforms such as QMK on the RP2040 (Markus Fritsche, for example, has been adding support [on his QMK fork](https://github.com/marfrit/qmk_firmware/tree/pio_m4_converter/keyboards/converter/pio_ps2_converter)). This started around the same time I did this project, and it's useful to see how that has evolved over time. Credit to Markus and others working on that. I'm certainly not trying to compete with it, or re-invent the wheel—I just wanted to build something that suited my own needs and share it with others who might find it useful.

Over time, this project's evolved to support more protocols, allowing both a keyboard and mouse to be connected simultaneously, and has various features I felt would just make using it a bit handier overall (at least for my own use-cases). I've tried to document everything as best I can, so hopefully others can find it useful too.

## Quick Start

Pick where you want to start based on what you're trying to do:

### Connecting Your Device to an RP2040 Board

Start with the **[Hardware Setup Guide](hardware-setup.md)**.

This guide walks you through the basics of wiring your device to a RP2040 board step-by-step. You'll see exactly what parts you need, how to connect everything on a breadboard, and how to verify your setup works before moving on to firmware. If you want more detailed technical explanations about different voltage levels and component selection, check out the more in-depth [Hardware Documentation](../hardware/README.md).

### Compiling Firmware for Your Device

This guide explains the Docker-based build process I use, which gives you a consistent environment no matter what operating system you're using. You'll learn how to specify your device configuration, enable optional features like simultaneous keyboard and mouse support, and understand what the build produces. The Docker approach means you don't need to install ARM compilers, CMake, or SDK versions locally — it handles all of that for you.

**You'll need:**

- [Docker Desktop](https://www.docker.com/products/docker-desktop)
- [Git CLI](https://github.com/git-guides/install-git)

Once you have the base requirements installed, and you're ready to build the firmware, follow the **[Building Firmware Guide](building-firmware.md)**. I've tried to keep this as simple as possible.

### Installing Firmware on Your RP2040

Once you've successfully built the firmware, follow the **[Flashing Firmware Guide](flashing-firmware.md)**. This will guide you through getting the firmware onto your RP2040 using a simple drag-and-drop process, how to use Command Mode for later firmware updates (so you don't need to physically press any buttons on the RP2040, as long as you've already built and flashed it once), and some troubleshooting steps if something doesn't work as expected.

Once the firmware's installed, you should be good to go! The board will reboot itself automatically (assuming everything went well), and it should now identify itself as a standard USB keyboard (and mouse if you've enabled that too). As long as you correctly configured the build time settings and your device is properly wired up, it should start working pretty much straight away.

---

## Need Help?

If you run into any issues or have questions, these are the best places to go:

- **[GitHub Discussions](https://github.com/PaulW/rp2040-keyboard-converter/discussions)** - Ask questions, share your build, or discuss features
- 🐛 **[GitHub Issues](https://github.com/PaulW/rp2040-keyboard-converter/issues)** - If you think you've found a bug or have hardware problems, log them here

**Before posting though, it's worth:**

1. Search through the existing discussions and issues—there's a good chance your question might have already been answered
2. Provide as much detail as you can: your keyboard model, what type of RP2040 board you're using, exact error messages, and photos of your wiring if it's relevant (pictures really do help!)

---

**[Next: Hardware Setup →](hardware-setup.md)**

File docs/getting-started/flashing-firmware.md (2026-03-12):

# Flashing Firmware

**Time Required**: 5-10 minutes

Now that you've built your firmware, it's time to get it onto your RP2040 board. Flashing requires putting the board into bootloader mode, at which point it appears as a USB mass-storage device. Copy the built UF2 file to that drive and the board reboots automatically with the new firmware loaded.

---

## Prerequisites

Before you can flash the firmware, you'll need:

- **Compiled firmware** - The `rp2040-converter.uf2` file from [Building Firmware](building-firmware.md)
- **Assembled hardware** - Your wired converter from [Hardware Setup](hardware-setup.md)
- **USB cable** - Connected from your RP2040 to your computer
- **Access to BOOT and RESET buttons** - On your RP2040 board (for first-time flash only)

**Note**: After this initial flash, you can update firmware using Command Mode—no need to access the buttons again!

---

## Understanding the Flashing Process

The RP2040 operates in two modes:

1. **Bootloader Mode** - Acts as a USB drive named `RPI-RP2`, ready to receive firmware
2. **Normal Mode** - Runs your converter firmware, translating keyboard/mouse input

**The flashing process is pretty simple:**

- You enter bootloader mode (the board appears as a USB drive)
- Copy the `.uf2` file to the drive
- The RP2040 automatically writes the firmware to its flash memory
- It reboots into normal mode
- Your converter starts working immediately

The RP2040 has a built-in bootloader that appears as a USB drive called `RPI-RP2` when you activate it—no special software needed, you just copy a file to it.

---

## Step 1: Locate the BOOT and RESET Buttons

First, locate the buttons on your RP2040 board. Where they are depends on which board you're using:

### Raspberry Pi Pico

- **BOOTSEL button**: Small button labeled "BOOTSEL" near the USB connector
- **RESET**: Not present (use USB unplug/replug instead, or add external reset button)

### Waveshare RP2040-Zero

- **BOOT button**: Small button labeled "BOOT" or "B"
- **RESET button**: Small button labeled "RESET" or "R"
- Located on the back of the board

(This is the board I use, by the way—it's compact and has both buttons, which makes life easier)

### Other RP2040 Boards

If you're using a different board, have a look at your board's documentation:

- BOOT/BOOTSEL button (always present—it's required for the bootloader)
- RESET button (may be absent on some boards)
- Some boards have a single button that serves both functions

**Tip**: If your board doesn't have a RESET button, you can enter bootloader mode by:

1. Disconnect USB cable
2. Hold BOOT button
3. Reconnect USB cable whilst holding BOOT
4. Release BOOT button

---

## Step 2: Enter Bootloader Mode

This is the important bit—you need to put your RP2040 into a state where it can receive new firmware.

### Method 1: Using BOOT + RESET Buttons (Recommended)

**If your board has both buttons:**

1. **Hold the BOOT button** - Press and hold (don't release yet)
2. **Press and release RESET** - Quickly tap the RESET button whilst holding BOOT
3. **Release BOOT button** - Let go of BOOT
4. **Verify**: A USB drive named `RPI-RP2` should appear on your computer

**Visual sequence:**

```text
BOOT: Press ████████████████████░░░░ Release
RESET: ░░░░ Tap ░░░░░░░░░░░░░░░
Time: 0s    1s         2s         3s
```

### Method 2: Using BOOT Button Only (No RESET Button)

**If your board lacks a RESET button:**

1. **Disconnect USB cable** - Unplug from RP2040
2. **Hold BOOT button** - Press and hold
3. **Reconnect USB cable** - Plug back in whilst holding BOOT
4. **Release BOOT button** - Let go after 2 seconds
5. **Verify**: `RPI-RP2` drive appears

### What You Should See

**On Windows:**

- File Explorer shows a new drive: `RPI-RP2 (D:)` or similar
- The drive contains two files: `INDEX.HTM` and `INFO_UF2.TXT`

**On macOS:**

- A new volume appears on your desktop: `RPI-RP2`
- It'll also show up in the Finder sidebar
- Contains the same two files

**On Linux:**

- The drive auto-mounts to `/media/<username>/RPI-RP2` or similar
- Shows the same two files

**Status LED (if installed):**

- **Will NOT turn magenta/purple** when using BOOT/RESET buttons
- LED will either remain **off** (if board was powered off)
- Or retain its **last state** (if board was already running when you pressed BOOT/RESET)
- Magenta LED is **only for Command Mode bootloader entry** (pressing 'B')

**Tip**: The `INFO_UF2.TXT` file contains your board's unique ID and bootloader version. This confirms you're in bootloader mode.

---

## Step 3: Flash the Firmware

Now you just need to copy your compiled firmware to the RP2040.

### Locate Your Firmware File

Your firmware file is sitting in your project's `build/` directory:

**Path**: `rp2040-keyboard-converter/build/rp2040-converter.uf2`

**File details:**

- Name: `rp2040-converter.uf2`
- Size: ~80-120 KB (depending on your configuration)
- This was created when you ran the build command

### Copy the Firmware

**Method 1: Drag and Drop (All Operating Systems)**

1. Open your file manager (Finder on macOS, Explorer on Windows, or your file browser on Linux)
2. Navigate to the `build/` folder in your project
3. Find `rp2040-converter.uf2`
4. **Drag the file** to the `RPI-RP2` drive
5. **Wait** - The file copies, then the drive disappears (the RP2040 reboots automatically)

**Method 2: Command Line (macOS/Linux)**

```bash
# From your project directory
cp build/rp2040-converter.uf2 /Volumes/RPI-RP2/
```

**Method 3: Command Line (Windows PowerShell)**

```powershell
# From your project directory
# Replace D: with your RPI-RP2 drive letter
Copy-Item build\rp2040-converter.uf2 D:\
```

### What Happens Next

**During flashing (takes 1-2 seconds):**

- The RP2040's onboard LED may blink rapidly (if there is one)
- The `RPI-RP2` drive disappears from your computer
- You might see a brief "drive removed" notification, or some other warning about being removed unexpectedly (that's normal)
- Your status LED (if you've installed one) remains in its previous state (it doesn't change during the BOOT/RESET method)

**After flashing:**

- The RP2040 automatically reboots
- Your new firmware starts running immediately
- The status LED shows orange (if an LED is installed—means it's waiting for device initialisation), and should change to green if everything's OK!

**Important**: The `RPI-RP2` drive disappearing is **normal and expected**. This means the firmware was successfully written and the RP2040 rebooted into normal mode.

---

## Step 4: Verify It's Working

Now let's test your newly flashed converter to confirm everything's working as it should.

### Initial Power-Up Checks

**1. Status LED (if installed):**

- **🟠 Orange**: Waiting for keyboard initialisation (normal at startup)
- **🟢 Green**: Converter ready (keyboard initialised successfully)
- **No light**: Either no LED installed, configuration or wiring issue

**2. Computer Recognition:**

- Your computer should detect a new USB keyboard (and mouse, if you built with mouse support)
- Windows: "Device connected" sound, Device Manager shows "USB Keyboard"
- macOS: Keyboard Setup Assistant may appear (click through to finish setup)
- Linux: Device appears in `lsusb` output
- **If using 4 LEDs**: You may see LEDs 2-4 (Num/Caps/Scroll Lock) change state as your computer sets the initial lock key status

### Testing Keyboard Input

**Basic functionality test:**

1. **Open a text editor** - Notepad (Windows), TextEdit (macOS), or whatever editor you prefer
2. **Type on your keyboard** - Try various keys
3. **Verify output appears** - The characters should appear in the editor
4. **Test special keys**:
   - Shift + letters (for uppercase)
   - Caps Lock (to ensure it toggles correctly)
   - Function keys (F1-F12)
   - Arrow keys, Home, End, Page Up/Down
   - Number pad (if your keyboard has one)

**Lock key indicators (if using 4 LEDs):**

- Press **Num Lock** - LED 2 should light up (unless you're connecting to a Apple Mac which doesnt use Num Lock)
- Press **Caps Lock** - LED 3 should light up
- Press **Scroll Lock** - LED 4 should light up

### Testing Mouse Input (if built with mouse support)

**Basic functionality test:**

1. **Move the mouse** - Cursor should move on screen
2. **Click buttons** - Left/right clicks should register
3. **Scroll wheel** (if mouse has one) - Page should scroll

---

## Step 5: Understanding Command Mode

Command Mode lets you update firmware and adjust settings **without having physical access to the RP2040 board**. Once your keyboard's tucked away inside a case or under a desk, Command Mode means you don't have to take everything apart just to update the firmware.

### What is Command Mode?

It's a special menu you can access by holding both shift keys for 3 seconds. Once you're in, you can:

- Enter bootloader mode for firmware updates (no BOOT button needed!)
- Adjust LED brightness
- Change debug log verbosity
- Toggle Shift-Override (press S) to modify key behaviour for keyboards with non-standard shift legends
- Reset to factory settings

For normal firmware updates — where the current firmware starts up successfully and Command Mode is reachable — you won't need to touch the BOOT and RESET buttons again. If the firmware is ever corrupted or the board no longer boots, you'll need to fall back to the physical BOOT button method described earlier in this guide.

### Entering Command Mode

**How to activate:**

1. **Press and hold BOTH shift keys** - Left Shift + Right Shift (don't press any other keys!)
2. **Hold for 3 seconds** - Status LED will start flashing green/blue
3. **Release shift keys** - You're now in Command Mode
4. **Press a command key** - See options below

**Important**: You must hold **ONLY** the two shift keys. If you press any other key (including modifiers like Ctrl or Alt), Command Mode won't activate.

**Note**: The default key combination is Left Shift + Right Shift, but this is configurable. Some keyboards (like those with a single shift key) may define different keys in their `keyboard.h` file. Check your specific keyboard's documentation if the default combination doesn't work.

**Visual feedback:**

- **Flashing Green/Blue (100ms intervals)**: Command Mode active, waiting for command
- **Times out after 3 seconds** if no key pressed

### Available Commands

Once Command Mode is active (flashing green/blue LED), press one of these keys:

| Key | Command | Description |
| ----- | --- | --- |
| **B** | **Bootloader** | Enter bootloader mode for firmware updates |
| **L** | **LED Brightness** | Adjust status LED brightness (0-10) |
| **D** | **Debug Level** | Change UART log verbosity (ERROR/INFO/DEBUG) |
| **F** | **Factory Reset**  | Restore all settings to defaults and reboot |
| **S** | **Shift-Override** | Toggle Shift-Override for non-standard shift legends |

We'll cover the Bootloader command in detail next. The other commands are explained in the [Features documentation](../features/command-mode.md).

---

## Step 6: Updating Firmware (Command Mode Method)

After your initial flash, use Command Mode to update firmware without touching the BOOT button. This is especially handy when your converter is installed and you want to try a different keyboard configuration or install updated firmware.

### When to Use This Method

**Use Command Mode for updates when:**

- ✅ Your converter's already installed and working
- ✅ You've built new firmware and want to flash it
- ✅ The BOOT/RESET buttons are hard to access
- ✅ You want a quick, handy update process

**Use the BOOT button method when:**

- ❌ You're flashing for the first time (no firmware installed yet)
- ❌ The firmware is corrupted or not booting
- ❌ Command Mode isn't responding

### Update Process Using Command Mode

**Full steps:**

1. **Build your new firmware** - Follow [Building Firmware](building-firmware.md) to create updated `rp2040-converter.uf2`

2. **Enter Command Mode**:
   - Press and hold both shift keys for 3 seconds
   - LED flashes green/blue rapidly
   - Release shift keys

3. **Press 'B' key** - Enters bootloader mode
   - LED turns **magenta** (purple/pink)
   - `RPI-RP2` drive appears on your computer
   - **Important**: The RP2040 stays in bootloader mode until you either copy a firmware file OR disconnect/reconnect power. Your existing firmware and settings remain safe—nothing is erased unless you flash a new .uf2 file (even then, your saved settings are preserved). You can safely exit bootloader mode by disconnecting and reconnecting USB.

4. **Copy firmware file**:
   - Drag `rp2040-converter.uf2` to `RPI-RP2` drive
   - Or use command line: `cp build/rp2040-converter.uf2 /Volumes/RPI-RP2/`

5. **Automatic reboot**:
   - Drive disappears (normal!)
   - RP2040 reboots with new firmware
   - LED shows orange → green as converter initialises

**Tip**: Once you press 'B', the bootloader stays active indefinitely—take your time copying the firmware file. There's no timeout once you're in bootloader mode.

### Troubleshooting Command Mode Updates

**Problem: LED doesn't flash green/blue when holding shifts**

- Make sure you're holding **ONLY** the two shift keys (no other keys!)
- Hold for full 3 seconds
- Check that firmware supports Command Mode (all recent builds do)
- If your keyboard uses custom Command Mode keys (not the default Left+Right Shift), check your keyboard's documentation for the correct combination

**Problem: Pressed 'B' but no RPI-RP2 drive appears**

- LED should turn magenta—if not, 'B' key didn't register
- Try entering Command Mode again
- As fallback, use BOOT button method (Step 2)

**Problem: Pressed 'B', saw magenta LED, but drive didn't appear on computer**

- Wait a few seconds—some systems take longer to mount USB drives
- Try unplugging and reconnecting USB cable (will exit bootloader, then re-enter via Command Mode)
- Check USB cable and port are working
- As fallback, use BOOT button method (Step 2)

---

## Troubleshooting

Running into issues? Here are troubleshooting steps and solutions:

---

### ❌ RPI-RP2 drive doesn't appear

**What this means**: Your RP2040 didn't enter bootloader mode.

**How to fix it**:

1. **Try again with precise timing**:
   - Hold the BOOT button firmly (don't just tap it)
   - Press RESET whilst continuing to hold BOOT
   - Hold BOOT for 2 full seconds after releasing RESET

2. **Check your USB cable**:
   - Make sure you're using a data cable (not a charge-only cable)
   - Try a different USB port on your computer
   - Try a different USB cable

3. **Verify board functionality**:
   - Does the RP2040's onboard LED light up when USB is connected?
   - If not, the board may have a power issue

4. **Try the alternative method**:
   - Disconnect USB
   - Hold BOOT
   - Reconnect USB whilst holding BOOT
   - Wait 2 seconds, then release BOOT

---

### ❌ Drive appears, but file won't copy

**What this means**: File copy error or drive not writable.

**How to fix it**:

1. **Check file size**:
   - `rp2040-converter.uf2` should be 80-120 KB
   - If file is 0 KB or very large, rebuild firmware

2. **Check file name**:
   - Must end in `.uf2` extension
   - Case-sensitive on macOS/Linux

3. **Try command line copy** instead of drag-and-drop:

   ```bash
   # macOS/Linux
   cp build/rp2040-converter.uf2 /Volumes/RPI-RP2/
   ```

   ```powershell
   # Windows (PowerShell)
   Copy-Item build\rp2040-converter.uf2 D:\
   ```

4. **Check drive permissions**:
   - Drive should be writable (not read-only)
   - On Linux, you may need sudo: `sudo cp ...`

---

### ❌ Firmware copied, but converter doesn't work

**What this means**: The firmware flashed successfully, but something's not quite right with the configuration.

**How to fix it**:

1. **Check your Status LED** (if you've installed one):
   - **Orange**: Waiting for keyboard (check your keyboard power and wiring)
   - **Off**: Either no LED installed, or there's an LED wiring problem
   - **Rapid flashing**: Error state (check UART output for details)

2. **Verify your keyboard configuration**:
   - Did you build firmware for the correct keyboard model?
   - Example: An AT/PS2 keyboard needs AT/PS2 protocol firmware
   - Rebuild with the correct `KEYBOARD` parameter if needed

3. **Check your hardware connections**:
   - Verify the CLOCK and DATA connections from [Hardware Setup](hardware-setup.md)
   - Make sure the level shifter is powered (3.3V and 5V)
   - Check keyboard power (5V to device)

4. **Try a different keyboard** (if available):
   - This confirms if the issue is firmware or hardware
   - Use the same protocol (e.g., another AT/PS2 keyboard)

---

### ❌ Computer doesn't recognise converter as keyboard

**What this means**: RP2040 is powered, but USB HID interface not working.

**How to fix it**:

1. **Check Device Manager / System Info**:
   - **Windows**: Device Manager → Human Interface Devices
   - **macOS**: System Information → USB
   - **Linux**: Run `lsusb` in terminal
   - Look for "USB Keyboard" or "HID Device"

2. **Try different USB port**:
   - Use direct motherboard USB port (not hub)
   - USB 2.0 ports often more reliable than USB 3.0 for this

3. **Verify firmware built correctly**:
   - Check build output had no errors
   - Firmware file size reasonable (80-120 KB)

4. **Re-flash firmware**:
   - Enter bootloader mode again
   - Copy firmware file again
   - Ensure drive disappears (indicates successful flash)

---

### ❌ Some keys don't work or produce wrong characters

**What this means**: There's a keymap mismatch or scancode issue.

**How to fix it**:

1. **Verify your keyboard configuration**:
   - Are you using the right keyboard model?
   - Example: A Model M Enhanced vs Model M Classic have different layouts
   - Check [Supported Keyboards](../keyboards/README.md) for your exact model

2. **Test for a systematic pattern**:
   - Do specific keys consistently fail (e.g., all Function keys)?
   - Do keys produce the wrong but consistent output (e.g., 'A' types 'B')?
   - This helps identify whether it's a scancode or keymap issue

3. **Check for a protocol mismatch**:
   - An AT/PS2 keyboard needs AT/PS2 protocol firmware
   - An XT keyboard needs XT protocol firmware
   - A protocol mismatch causes unpredictable key behaviour

4. **Have a look at your keyboard documentation**:
   - Some keyboards have quirks or variations
   - See `src/keyboards/<your-keyboard>/README.md` for details

---

### 💡 Still having issues?

If none of these solutions work:

1. **Enable debug output**:
   - Connect UART adapter to RP2040 GPIO 0 (TX) and GPIO 1 (RX)
   - Use Command Mode ('D' key) to set debug level to 3 (DEBUG)
   - Watch serial output for error messages

2. **Try a known-good configuration**:
   - Build firmware with `modelm/enhanced` (standard AT/PS2 configuration)
   - Test with a standard PS/2 keyboard if available
   - Rules out configuration-specific issues

3. **Ask for help**: Visit [GitHub Discussions](https://github.com/PaulW/rp2040-keyboard-converter/discussions) with:
   - Your keyboard model and protocol
   - Build command you used
   - Any error messages or unexpected behaviour
   - UART debug output (if available)

---

## What's Next?

Your converter should now be up and running.

### Using Your Converter

Your converter's ready for daily use:

- Plug in your keyboard
- Connect the RP2040 to your computer via USB

### Exploring Features

Learn more about what your converter can do:

- **[Command Mode](../features/command-mode.md)** - Full guide to all Command Mode features
- **[Keyboard Layouts](../keyboards/README.md)** - Details about specific keyboard models

### Customisation and Advanced Use

Ready to go deeper?

- **[Custom Keymaps](../development/custom-keymaps.md)** - Remap keys to your preference
- **[Adding New Keyboards](../development/adding-keyboards.md)** - Support your own keyboard model
- **[Build System Details](../advanced/README.md)** - Understanding the build process

### Getting Help

If you run into issues or have questions:

- 💬 [GitHub Discussions](https://github.com/PaulW/rp2040-keyboard-converter/discussions) - Community support
- 🐛 [Report Issues](https://github.com/PaulW/rp2040-keyboard-converter/issues) - Bug reports and feature requests

---

## Quick Reference

Once you're familiar with the process, here's the condensed version:

**Initial flash (physical buttons):**

```text
1. Hold BOOT button
2. Press and release RESET
3. Release BOOT
4. Copy rp2040-converter.uf2 to RPI-RP2 drive
5. Wait for automatic reboot
```

**Update firmware (Command Mode):**

```text
1. Hold both shift keys for 3 seconds
2. Press 'B' key
3. Copy rp2040-converter.uf2 to RPI-RP2 drive
4. Wait for automatic reboot
```

**Command Mode quick keys:**

- **B** = Bootloader mode (for firmware updates)
- **L** = LED brightness adjustment
- **D** = Debug log level selection
- **F** = Factory reset
- **S** = Shift-Override toggle

---

**[← Previous: Building Firmware](building-firmware.md)**

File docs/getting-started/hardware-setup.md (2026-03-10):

# Hardware Setup

By the end of this guide, you should have a working converter ready to connect whichever device you're using (keyboard, mouse, or both) and get it working on your computer.

I'm not going to dive into the deep technical details of how everything works here (that's what the [Hardware Documentation](../hardware/README.md) is for), but rather give you a simple, step-by-step guide to get you up and running as quickly as possible.

---

## What We're Building

To keep things simple, we'll be setting everything up on a breadboard that you can connect your device to. It'll handle the necessary voltage level shifting between the keyboard and the Raspberry Pi Pico, then connect to your computer via USB. This is actually the exact setup I used when I originally started development—it's simple to build, easy to modify and test different configurations.

---

## What You'll Need

**The essentials:**

- A PS/2 keyboard (or whichever supported device you're working with)
- An RP2040 board. I've used a WaveShare RP2040-Zero for mine, but a Raspberry Pi Pico or any similar board should work just fine—the only real difference between them is the pinout and physical size
- A breadboard and jumper wires (a 400-point half-size breadboard should do nicely)
- A bi-directional level shifter module (I'd really recommend one using BSS138 level shifters—I use the Adafruit one listed below and find it much easier and more compact than mucking about with a bunch of resistors)
- Whichever breakout or connector you need to connect your device (a PS/2 Mini-DIN-6 socket for PS/2 keyboards, a 5-pin DIN-5 socket for older AT/XT keyboards, that sort of thing)

**Quick shopping list:**

| Component | Quantity | Approx Cost |
| --- | --- | --- |
| [Waveshare RP2040-Zero](https://amzn.eu/d/bZ0RDjV) | 1 | £8-12 |
| [Level shifter module](https://thepihut.com/products/adafruit-4-channel-i2c-safe-bi-directional-logic-level-converter) | 1 | £2-5 |
| PS/2 connector/adapter (Mini-DIN-6) | 1 | £2-10 |
| USB cable (Micro USB or USB-C depending on your RP2040 board) | 1 | £1-5 |
| [Breadboard](https://thepihut.com/products/raspberry-pi-breadboard-half-size) | 1 | £3-5 |
| [Jumper wires](https://thepihut.com/products/premium-male-male-jumper-wires-20-x-6-150mm) | 1 set | £2-5 |

**Total**: Around £15-40 depending on what you choose and what you might already have lying about. I know it might seem like a bit of an expense just to try this out, but these components are all fairly reusable for other projects too, so they won't go to waste.

**Where to buy**: Adafruit, SparkFun, Pimoroni, Amazon, eBay—all carry these.

---

## What Do We Need the Level Shifter For?

⚠️ **This is important**: Don't connect your device directly to the RP2040!

Older keyboards and mice operate at 5V, which is far too high for the RP2040 to handle directly. If you connect them straight in without a level shifter (or some other way to step down the voltages, like resistors), you'll damage the RP2040.

The level shifter sits between them, translating voltages automatically in both directions:

- Device → RP2040: Converts 5V HIGH down to a safe 3.3V HIGH
- RP2040 → Device: Converts 3.3V HIGH up to 5V HIGH

This isn't optional—it's essential for protecting your hardware! Now, there are other ways to handle this (like using step-down resistors), but for simplicity I decided to use a dedicated level shifter module.

Another reason I use the BSS138-based level shifter modules is that they're bi-directional. Some keyboard and mouse protocols send data in both directions (from device to RP2040, and from RP2040 back to device), so having a bi-directional level shifter makes the wiring much simpler.

---

## Step 1: Identify Your Device's Connector

Now, I know we're focusing on PS/2 keyboards for this guide, but it's worth knowing how to identify your device's connector type and pinout if you want to use something different. I've added a quick overview of some of the different connector types and pinouts below, but just be aware your mileage may vary—even though different keyboards or mice might use the same connector, the pinouts can differ slightly between manufacturers. AT/PS2 keyboards and mice will all use the same standard pinout. It's just when you start looking at other devices, like Amiga or Apple M0110 keyboards, where things can differ a bit more.

**Working out the pinout:**

You'll need to know which wires carry the power and signal lines. Have a look at the **[Protocol Documentation](../protocols/README.md)** for whichever type of device you're wanting to use, as they contain specific information about wiring layouts and pinouts for each protocol.

**Tip**: It's always handy to have a multimeter to hand—it'll help you verify which wire corresponds to each pin before connecting things up.

---

## Step 2: Set Up the Breadboard

### Component Placement

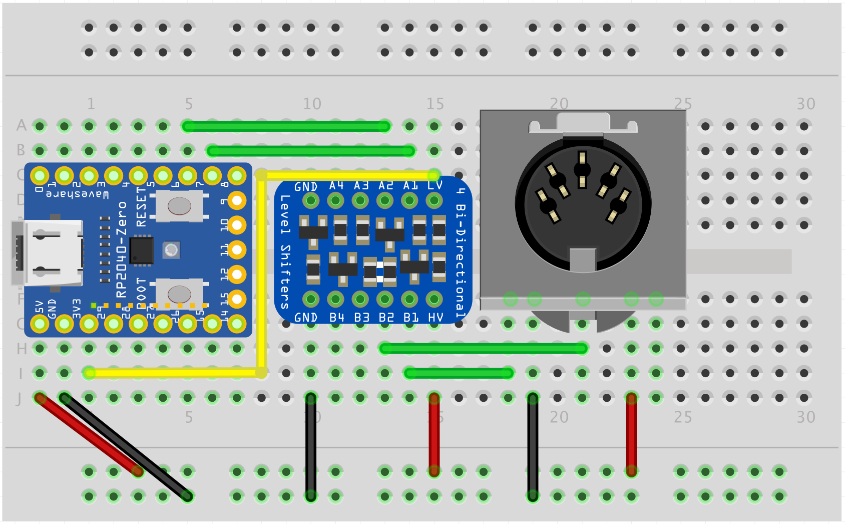
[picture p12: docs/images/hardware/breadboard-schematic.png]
Breadboard Schematic


_The breadboard schematic above shows a WaveShare RP2040-Zero, a BSS138 level shifter, and a 5-pin 180° DIN socket for the keyboard connection (you can use whatever connector you need though—it just depends on your specific keyboard or mouse). This particular example is keyboard-only (no mouse), but the principle's the same if you're adding mouse support too._

**How to lay things out:**

1. Place the RP2040 board on the left side, spanning the centre gap (so the pins are accessible on both sides)
2. Place the level shifter module on the right side, leaving a few rows between it and the RP2040
3. Keep the top and bottom power rails accessible for connections
4. Orient the modules so the pin labels are visible

**Tip**: Take a photo of your layout for reference when troubleshooting. That way, if you do move anything around, you have a visual record to compare against.

---

## Step 3: Connect the Power Lines

First, connect the power and ground connections to all the components.

| From | To | Wire Colour | Purpose |
| --- | --- | --- | --- |
| RP2040 **VSYS** pin  | Power Rail **Upper** | Red | 5V for level shifter HV side and device |
| RP2040 **GND** pin | Power Rail **Lower** | Black | Common ground |
| RP2040 **3V3** pin | BSS138 **LV** | Yellow | 3.3V for level shifter LV side |
| Power Rail **Upper** | BSS138 **HV** | Red | Connect HV Power to level shifter |
| Power Rail **Lower** | BSS138 **GND** | Black | Common Ground to level shifter |
| Power Rail **Upper** | Device **VCC** pin\* | Red | Power for device (5V) |
| Power Rail **Lower** | Device **GND** pin\* | Black | Common ground |

**Important**: Different breadboards might have slightly different layouts—I'm basing this on the one I've got, so make sure to verify the power rails on your own breadboard. Also, with the WaveShare RP2040-Zero, pins 9 to 15 shouldn't be used or connected to anything. Because they're all positioned horizontally, they'll end up on the same row on the breadboard and might cause shorts if you connect them.

**\*Device VCC/GND pins**: These will depend on the connector you're using for your device. Check the pinout for your specific connector to work out which pins are VCC and GND.

**Don't power anything on yet** - we've still got the signal lines to connect, so hold off on plugging in the USB for now.

---

## Step 4: Connect the Signal Lines

With the power lines connected, we can now wire up the signal lines. These carry the data and clock signals between the RP2040 ↔ Level Shifter ↔ Device.

### Level Shifter

As we're using the Adafruit Level Shifter, the pinout is as follows:

```text
   [Level Shifter Module]

                    LV ──┐────┌── HV
 Low Voltage Side   A1 ──┤    |── B1   High Voltage Side
 (3.3V - RP2040)    A2 ──┤    |── B2   (5V - Device side)
                    A3 ──┤    |── B3
                    A4 ──┤    |── B4
                   GND ──┘────└── GND
```

We should've already connected the LV, HV and GND pins in the previous step, so now we just need to connect the signal lines. It's important we make sure the LV side connects to the RP2040, and the HV side connects to the device. For the PS/2 keyboard example, we'll only be connecting the data and clock lines.

### Signal Line Connections

| From | To | Wire Colour | Purpose |
| --- | --- | --- | --- |
| RP2040 **DATA** pin  | Level Shifter **A1** | Green | DATA signal (3.3V side)  |
| RP2040 **CLOCK** pin | Level Shifter **A2** | Green | CLOCK signal (3.3V side) |
| Level Shifter **B1** | Device **DATA** pin  | Green | DATA signal (5V side) |
| Level Shifter **B2** | Device **CLOCK** pin | Green | CLOCK signal (5V side) |

**Note**: The Adafruit level shifter has 4 channels (A1/B1 to A4/B4)—A1-A4 are the 3.3V low voltage side, and B1-B4 are the 5V high voltage side.

**One hardware constraint to be aware of**: The firmware expects the clock pin to be data pin + 1. So if data is on `GPIO 2`, then clock needs to be on `GPIO 3`. This means you can use pairs like `2`/`3`, `6`/`7`, `10`/`11`, etc. If you follow the breadboard schematic with `GPIO 6`/`7`, you'd update `KEYBOARD_DATA_PIN` to `6` in the [`src/config.h`](../../src/config.h) file before building.

```c
#define KEYBOARD_DATA_PIN 6  // Change this to match your DATA pin
#define MOUSE_DATA_PIN 10    // Change this if you're using a mouse too
#define LED_PIN 29           // Change this if you're adding LEDs
```

### Example: Wiring a PS/2 Keyboard

PS/2 pinout (this is the female connector on the cable, looking at the pins):

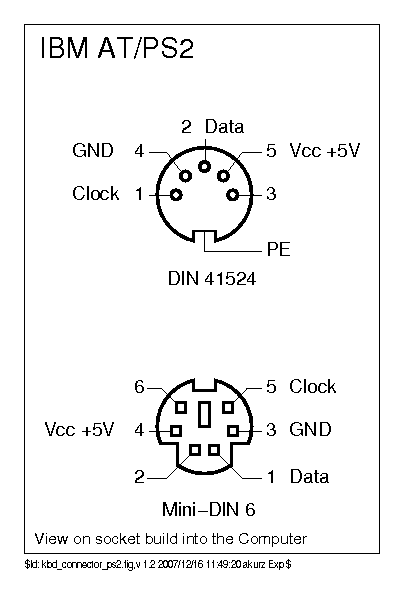
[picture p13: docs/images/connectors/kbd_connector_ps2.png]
PS/2 Connector Pinout


---

## Step 5: Adding a Status LED (Optional but Recommended)

This might go a bit beyond the basic setup we're working towards (and it's completely optional), but I wanted to mention it here as it does come in handy.

The converter can use an addressable WS2812B RGB LED to show you what's going on, providing useful visual feedback about what the converter's doing.

**What the LED shows:**

- **🟢 Green**: Converter's ready and working
- **🟠 Orange**: Waiting for device initialisation
- **🟣 Magenta**: Bootloader mode (ready for firmware flashing)
- **💚💙 Flashing Green/Blue**: Command mode active
- **💚💖 Flashing Green/Pink**: Log level selection mode
- **🌈 Rainbow**: Brightness adjustment mode

You can also use 4 LEDs if you want to show the lock key states (Num Lock, Caps Lock, Scroll Lock).

### What You Need

Just a WS2812B LED (or 'NeoPixel') and 3 jumper wires. Cost is around £2-8 depending on whether you get individual LEDs, a strip, or a breakout board. The **[Hardware Guide](../hardware/README.md#status-leds)** has detailed info on where to buy them and the different options available.

### Wiring It Up

The WS2812B is rated from 3.5V, but will operate from the RP2040's 3.3V rail in practice. Running below the rated minimum may cause slight colour shift (particularly in the blue channel) compared to devices powered at the rated voltage.

**LED Pinout** (typical WS2812B):

```text
     ┌───────────┐
     │  WS2812B  │
     │    LED    │
     │           │
VCC ─┤   ●   ●   ├─ GND
     │    ╲ ╱    │
DIN ─┤     X     ├─ DOUT
     │    ╱ ╲    │
     └───────────┘
```

**Connections:**

| WS2812B Pin | Connect To | Wire Colour | Notes |
| --- | --- | --- | --- |
| **VCC** | RP2040 **3V3** pin | Red | Use 3.3V, not 5V |
| **GND** | Power Rail **Lower** | Black | Common ground |
| **DIN** (Data In) | RP2040 **`GPIO 29`** | Any colour  | Default data pin |

**A couple of things to note**:

- Use the **DIN** (Data In) pin, not DOUT (Data Out). You'd only use DOUT if you're chaining multiple LEDs together.
- The default GPIO is pin 29 (defined in [`src/config.h`](../../src/config.h))
- If you're using an LED strip, connect to the first LED's DIN pin

**For multiple LEDs or changing the GPIO pin**, have a look at the **[Hardware Guide - Status LEDs section](../hardware/README.md#status-leds)** for detailed instructions on chaining LEDs and customising pin assignments.

---

## Step 6: Verify Connections

Before we power things up, let's just check everything we've connected.

### Things to Check

- [ ] **Power connections are solid**: 3.3V and 5V rails properly connected to the RP2040
- [ ] **All grounds tied together**: RP2040, level shifter, and device all sharing common ground
- [ ] **No voltage shorts**: 3.3V and 5V rails are separate and not touching each other
- [ ] **Level shifter powered correctly**: LV connected to 3.3V, HV connected to 5V
- [ ] **Signal paths look right**: GPIO → LV pins → HV pins → Device
- [ ] **GPIO pins match config.h**: Check your wiring matches the pin definitions in [`src/config.h`](../../src/config.h) (or update config.h to match your wiring)
- [ ] **Device connector is correct**: Clock and data wires match your connector's pinout
- [ ] **Nothing's loose**: All connections are firmly seated in the breadboard
- [ ] **LED connected properly (if using one)**: WS2812B VCC to 3.3V, GND to ground, DIN to the right GPIO (check LED_PIN in [`src/config.h`](../../src/config.h))

### Visual Verification

Compare your breadboard to the wiring diagram earlier in this guide. Take a photo and trace each connection with different coloured markers if it helps.

**Common mistakes to watch out for:**

- ❌ Connecting the device clock/data straight to the RP2040 (bypassing the level shifter)
- ❌ Swapping clock and data lines around
- ❌ Forgetting to connect the level shifter power references (those LV and HV pins)
- ❌ Using separate grounds (remember, all grounds need to be common)
- ❌ Dodgy breadboard connections (give the wires a little wiggle to make sure they're properly seated)

---

## Step 7: Test the Hardware

Now power everything up to verify it's working before we flash the firmware.

### Powering Up for the First Time

1. **Connect the USB cable** from the RP2040 to your computer
2. **The RP2040 LED (if there is one) should light up** - shows the board's getting power
3. **Your device should power on** - keyboards might flash their LEDs briefly during self-test
4. **No smoke, no burning smell** - Unless you have something seriously wrong, or something's damaged, you shouldn't see or smell anything bad

### What to Expect (Before Firmware is Loaded)

Without the firmware, the RP2040 won't respond to your device yet. This is completely normal. Here's what you should see:

✅ **RP2040 board LED is lit** (the power indicator)  
✅ **Device has power** (LEDs might light up if your keyboard has always-on indicators)  
✅ **RP2040 appears as "RPI-RP2" mass-storage device only when placed into BOOTSEL mode** (hold BOOTSEL during power-on or reset). Simply powering an unflashed board does not reliably enter this state on its own.

❌ **Keyboard does nothing when you type** (no firmware loaded yet)  
❌ **No WS2812B LED activity** (if you're using one, firmware's needed to control it, otherwise it won't light)  
❌ **Computer doesn't see it as a keyboard** (normal—you haven't flashed the firmware yet)

### If Something's Not Working

**RP2040 LED not lighting up?**

- Does it even have one? (Some boards don't)
- Check the USB cable (try a different one that you know works for data)
- Make sure the RP2040 board isn't damaged
- Try a different USB port on your computer
- If all else fails, try removing the RP2040 from the breadboard and just powering it on its own to see if the issue is with the board or the wiring

**Device not powering on?**

- Check the 5V connection from VSYS to the device VCC
- Double-check the device connector pinout (make sure VCC and GND are correct)
- If you have a multimeter, test for continuity
- Your computer might not be supplying enough power (try a powered USB hub or a different computer)

**Device LEDs flickering or acting strange?**

- Some keyboards do this during self-test, so it might be perfectly normal
- If it's constantly flickering, check for a power issue (verify that 5V connection is solid)
- It might indicate that the device itself is faulty or has an issue (try a different keyboard if you have one)

---

## Step 8: Next Steps

Your hardware's ready! Now you need to build and flash the firmware to get everything working.

### Where to Go From Here

With the hardware sorted:

1. **[Build the Firmware](building-firmware.md)** - Compile the firmware for your specific device
2. **[Flash the Firmware](flashing-firmware.md)** - Get the firmware installed on the RP2040
3. **Test it all out** - Make sure everything works together

### If Things Still Aren't Right

Hardware issues can be caused by wiring mistakes or component failures. Things to check:

- **Go through the verification checklist again** - Did you miss a connection somewhere?
- **Check the pinout diagrams** - Are clock and data swapped?
- **Double-check the level shifter orientation** - Are the HV and LV sides the right way round?
- **Test continuity** - If you have a multimeter, check the connections
- **Look for shorts** - Make sure no adjacent breadboard holes are accidentally bridged
- **WS2812B not lighting up?** - Check it's getting 3.3V power, and that DIN's connected to the right GPIO pin

**Need more help?**

- 📖 **[Hardware Deep Dive](../hardware/README.md)** - More detailed component information
- 📖 **[Advanced Topics](../advanced/README.md)** - System architecture and implementation details
- 💬 **[Ask on GitHub Discussions](https://github.com/PaulW/rp2040-keyboard-converter/discussions)** - Community support
- 🐛 **[Report Issues](https://github.com/PaulW/rp2040-keyboard-converter/issues)** - Found a bug? Let me know!

---

## Complete Wiring Diagram

Here's everything in one place as a reference:
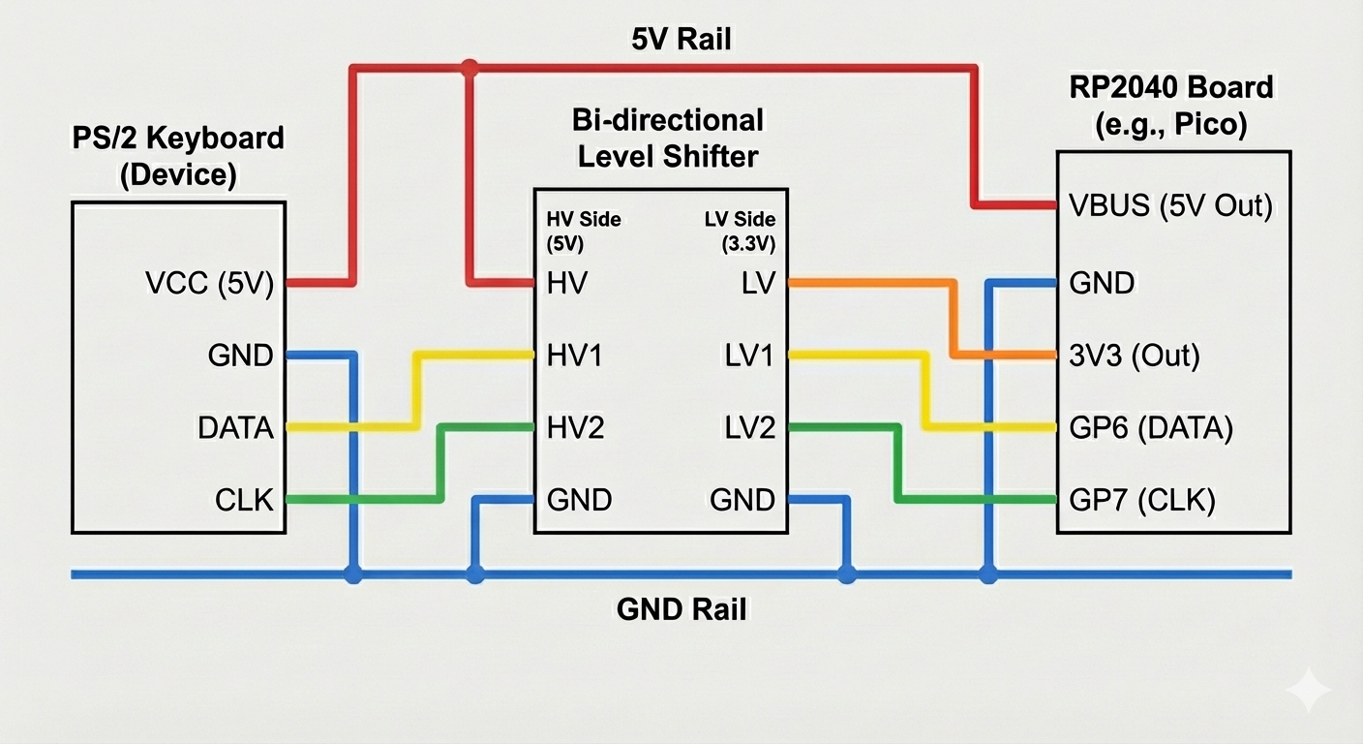
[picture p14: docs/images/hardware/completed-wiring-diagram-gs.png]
Complete Wiring Diagram


**Connection Summary:**

- Device VCC → 5V Rail → RP2040 VSYS
- Device GND → GND Rail (common to all)
- Device DATA → Level Shifter HV1 → Level Shifter LV1 → RP2040 GPIO (your DATA pin)\*
- Device CLOCK → Level Shifter HV2 → Level Shifter LV2 → RP2040 GPIO (your CLOCK pin)\*
- Level Shifter HV → 5V Rail
- Level Shifter LV → RP2040 3V3
- Level Shifter GND → GND Rail

**\* A note on GPIO pins**: The diagram shows example GPIO connections. Your actual pin numbers will match whatever you've defined in [`src/config.h`](../../src/config.h) (KEYBOARD_DATA_PIN). The hardware requires the clock pin to be data pin + 1.

---

**[← Previous: Getting Started](README.md)** | **[Next: Building Firmware →](building-firmware.md)**

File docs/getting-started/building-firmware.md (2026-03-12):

# Building Firmware

**Time Required**: 10-15 minutes (first build)

This guide will walk you through building custom firmware for your specific keyboard and mouse combination. I've set things up to use Docker, which creates a consistent build environment that works the same way on Windows, macOS, and Linux—so you won't need to manually install compilers, SDKs, or development tools.

**Why Docker?** It packages the build tools (ARM GCC compiler, Pico SDK, CMake) into a single container. You run one command, and Docker handles everything behind the scenes—same result on Windows, macOS, and Linux.

---

## Prerequisites

Before you can build the firmware, you'll need to have:

- **Docker Desktop** installed and running
  - Windows: [Docker Desktop for Windows](https://docs.docker.com/desktop/install/windows-install/)
  - macOS: [Docker Desktop for Mac](https://docs.docker.com/desktop/install/mac-install/)
  - Linux: [Docker Engine](https://docs.docker.com/engine/install/)
- **Git** (to clone the repository)
- **10 GB free disk space** (for Docker images and build artifacts)

**Note**: The Docker container includes all the required build tools (ARM GCC toolchain, Pico SDK, CMake, etc.), so you don't need to install these separately.

---

## Step 1: Clone the Repository

First, download the project source code to your computer. Open a terminal (macOS/Linux) or PowerShell (Windows) and run:

```bash
git clone https://github.com/PaulW/rp2040-keyboard-converter.git
cd rp2040-keyboard-converter
```

**What's happening here:**

- `git clone` downloads the project from GitHub to your computer
- `cd rp2040-keyboard-converter` moves you into the project directory

That's it! The Docker container includes the Pico SDK, so you don't need to download it separately.

**Note for developers:** If you're planning to do local development work (editing code with IDE autocomplete, debugging, that sort of thing), you'll want the Pico SDK locally for your development tools. In that case, clone with `--recurse-submodules`:

```bash
git clone --recurse-submodules https://github.com/PaulW/rp2040-keyboard-converter.git
```

Or add it after cloning:

```bash
git submodule update --init --recursive
```

For just building firmware, this isn't necessary—Docker has everything it needs.

---

## Step 2: Build the Docker Container

Now we'll create the Docker container with all the build tools. This is a one-time setup—you'll only do this once (unless we update the build environment), so whilst it might take a few minutes, you won't have to do it again:

```bash
docker compose build builder
```

**What's happening behind the scenes:**

1. Docker downloads a base Ubuntu Linux image
2. Installs the ARM GCC cross-compiler (converts code to RP2040-compatible binaries)
3. Installs the Pico SDK version 2.2.0 (Raspberry Pi's official libraries)
4. Configures CMake (manages the build process)
5. Sets up all necessary dependencies

**Duration**: 5-10 minutes on first run (depends on your internet speed)

**Important**: This creates a cached Docker image. Once it's built, it stays on your computer and gets reused for all future firmware builds. You won't wait this long again unless you need to rebuild the container (which is pretty rare).

---

## Step 3: Choose Your Configuration

Before building, you'll need to tell the build system which keyboard model you're using. Each keyboard has its own configuration that includes:

- **Protocol**: The communication method (AT/PS2, XT, Amiga, M0110)
- **Scancode set**: How the keyboard reports keypresses
- **Layout**: Physical key arrangement and mapping

### Finding Your Keyboard

Browse the available keyboard configurations in the **[Supported Keyboards](../keyboards/README.md)** documentation. Each keyboard has a configuration path like `modelm/enhanced` or `amiga/a500`.

You can also list all available keyboards from the terminal:

```bash
find src/keyboards -name "keyboard.config"
```

This shows paths like:

```text
src/keyboards/modelm/enhanced/keyboard.config
src/keyboards/amiga/a500/keyboard.config
src/keyboards/apple/m0110a/keyboard.config
```

The configuration path is the part after `src/keyboards/`—for example, `modelm/enhanced`.

**Not sure which configuration to use?** The `modelm/enhanced` configuration works as a general-purpose AT/PS2 configuration for standard 101/104-key layouts.

For keyboards with specific layouts or different protocols (XT, Amiga, M0110), have a look at the [Supported Keyboards](../keyboards/README.md) documentation to find the configuration that best matches your hardware.

### Mouse Support (Optional)

The converter can also support a mouse alongside your keyboard if you want. This is completely optional.

**If you want mouse support:**

- The converter supports AT/PS2 mouse protocol
- Requires separate hardware wiring (the mouse uses its own CLOCK/DATA pins—see [Hardware Setup](hardware-setup.md))
- Works with any keyboard protocol (so you could use an AT/PS2 mouse with an Amiga keyboard, for example)

**For this getting started guide**, we'll focus on keyboard-only builds. If you do need mouse support, the process is nearly identical—you'd just add `-e MOUSE="at-ps2"` to your build command. Have a look at the [Mouse Support documentation](../features/README.md#mouse-support) for the details.

---

## Step 4: Build Firmware

Now to actually compile the firmware. You tell Docker which keyboard you're using, and it handles all the compilation details.

### The Build Command

Run this command, replacing `modelm/enhanced` with your keyboard's configuration path:

```bash
docker compose run --rm -e KEYBOARD="modelm/enhanced" builder
```

**Breaking down the command:**

- `docker compose run` - Starts a Docker container from the image we built earlier
- `--rm` - Automatically removes the container when done (keeps your system clean)
- `-e KEYBOARD="modelm/enhanced"` - Sets an environment variable telling the build system which keyboard to configure for
- `builder` - The name of our build container (defined in [`docker-compose.yml`](../../docker-compose.yml))

**That's it!** This single command triggers the entire build process.

### What Happens During the Build

You don't need to understand all the details, but here's what's happening:

1. **Container starts** - Docker launches the build environment with all the tools ready
2. **Configuration loads** - CMake reads your keyboard's `keyboard.config` file
3. **Dependencies resolve** - The build system works out which source files are needed
4. **Protocol handler includes** - Adds the correct protocol code (AT/PS2, XT, Amiga, or M0110)
5. **Scancode processor includes** - Adds scancode translation for your keyboard's specific format
6. **Keymap includes** - Loads your keyboard's layout and key mappings
7. **PIO compilation** - Converts PIO assembly (hardware timing programs) into C headers
8. **Source compilation** - ARM GCC compiles all the C files into machine code for the RP2040
9. **Linking** - Combines everything into a single executable
10. **UF2 generation** - Creates the flashable firmware file
11. **Cleanup** - Container exits and removes itself

**Duration**: 30-60 seconds (after the Docker image's been built)

You don't need to know C programming, understand CMake syntax, or configure toolchains manually—just specify your keyboard, and Docker handles the rest.

### Understanding Build Output

When the build completes successfully, you'll see output that looks something like this:

```text
-- Build files have been written to: /build
Scanning dependencies of target rp2040-converter
[ 12%] Building C object CMakeFiles/rp2040-converter.dir/src/main.c.obj
[ 25%] Building C object CMakeFiles/rp2040-converter.dir/src/common/lib/hid_interface.c.obj
...
[100%] Linking CXX executable rp2040-converter.elf
   text    data     bss     dec     hex filename
 175432    2568   27144  205144   3213c rp2040-converter.elf
[100%] Built target rp2040-converter
```

**What those percentages mean**: Each source file gets compiled individually, and the percentages show progress through all the files. When it reaches 100%, everything's been compiled and linked together.

**Output files created in `./build/` directory:**

- **`rp2040-converter.uf2`** ← This is the file you'll flash to your RP2040
- `rp2040-converter.elf` - Binary with debugging symbols (for developers)
- `rp2040-converter.elf.map` - Memory layout map (for developers)

You only need the `.uf2` file for normal use—the others are for debugging and development.

---

## Step 5: Verify Build Output

Let's confirm the firmware file was created successfully. From your terminal, check the `build/` directory:

**On macOS/Linux:**

```bash
ls -lh build/rp2040-converter.uf2
```

**On Windows (PowerShell):**

```powershell
Get-ChildItem build\rp2040-converter.uf2
```

**Expected output:**

```text
-rw-r--r--  1 user  staff   88K Oct 30 10:30 build/rp2040-converter.uf2
```

**What to look for:**

- File exists in the `build/` directory
- File size: 80-120 KB range (varies by configuration)
- Size depends on keyboard configuration, enabled features, and code changes

If you see the file with a reasonable size, brilliant! Your firmware's built and ready to flash.

---

## Understanding Build Configuration

The build system uses environment variables to customise the firmware. Let's break down what each one does:

### The KEYBOARD Variable (Required)

Every build needs a keyboard configuration. This is how you tell the build system which keyboard you're using:

```bash
-e KEYBOARD="<brand>/<model>"
```

**What this does:**

- Points to the configuration file at `src/keyboards/<brand>/<model>/keyboard.config`
- Loads the correct protocol handler (AT/PS2, XT, Amiga, etc.)
- Includes the appropriate scancode set (how keys are numbered)
- Loads the keyboard-specific layout and key mappings

**Real-world example**: When you build with `KEYBOARD="modelm/enhanced"`, the system:

- Reads [`src/keyboards/modelm/enhanced/keyboard.config`](../../src/keyboards/modelm/enhanced/keyboard.config)
- Sees it needs the AT/PS2 protocol
- Includes Scancode Set 1/2/3 unified processor (`set123`)
- Loads the 101-key Enhanced keyboard layout
- Compiles in the keymap from [`src/keyboards/modelm/enhanced/keyboard.c`](../../src/keyboards/modelm/enhanced/keyboard.c)

### The MOUSE Variable (Optional)

Add mouse support to your keyboard converter:

```bash
-e MOUSE="at-ps2"
```

**What this does:**

- Includes the AT/PS2 mouse protocol handler code
- Allocates a separate PIO state machine for mouse communication
- Configures GPIO 6/7 for mouse CLOCK/DATA (independent from keyboard pins - see [`src/config.h`](../../src/config.h))
- Enables simultaneous keyboard and mouse conversion

**Currently supported**: Only `at-ps2` mouse protocol (standard PS/2 mice)

**Note**: You can use an AT/PS2 mouse with any keyboard protocol—the mouse operates independently.

---

## Troubleshooting

Running into issues? Here are some troubleshooting steps:

---

### ❌ "When building, you need to ensure you set the required Keyboard or Mouse"

**What this means**: You need to specify at least one device—either a keyboard, a mouse, or both.

**How to fix it**:
You can build with any of these options:

**Keyboard only:**

```bash
docker compose run --rm -e KEYBOARD="modelm/enhanced" builder
```

**Mouse only:**

```bash
docker compose run --rm -e MOUSE="at-ps2" builder
```

**Both keyboard and mouse:**

```bash
docker compose run --rm -e KEYBOARD="modelm/enhanced" -e MOUSE="at-ps2" builder
```

---

### ❌ "File 'keyboard.config' does not exist!" or "keyboard.config not found"

**What this means**: The keyboard path you specified doesn't exist, or you have a typo somewhere.

**How to fix it**:

1. Check which keyboards are actually available:

   ```bash
   find src/keyboards -name "keyboard.config"
   ```

2. Use the path shown after `src/keyboards/`
   - ✅ Correct: `modelm/enhanced`
   - ❌ Wrong: `src/keyboards/modelm/enhanced`
   - ❌ Wrong: `ModelM/Enhanced` (case matters!)

---

### ❌ "Keyboard config file is missing the following key(s)"

**What this means**: The keyboard configuration file exists but is incomplete or corrupted.

**How to fix it**:
The keyboard configuration file may be missing required fields. Try:

1. Verify you're using an official keyboard configuration from the repository
2. If you created a custom keyboard, check your `keyboard.config` file includes all required fields:
   - `MAKE` - Keyboard manufacturer
   - `DESCRIPTION` - Keyboard description
   - `MODEL` - Keyboard model
   - `PROTOCOL` - Protocol handler (at-ps2, xt, amiga, apple-m0110)
   - `CODESET` - Scancode set to use

3. Compare your config against a working example like [`src/keyboards/modelm/enhanced/keyboard.config`](../../src/keyboards/modelm/enhanced/keyboard.config)

---

### ❌ "Cannot connect to Docker daemon"

**What this means**: Docker isn't running on your computer.

**How to fix it**:

1. Open the Docker Desktop application
2. Wait until you see "Docker Desktop is running" (you'll see a green indicator)
3. Try your build command again

**Still not working?** Make sure Docker Desktop's actually installed. Have a look at the [Prerequisites](#prerequisites) section for installation links.

---

### ❌ Build succeeds, but no UF2 file appears

**What this means**: Docker's built the firmware, but it's not appearing in your `build/` folder. This may be a volume mounting issue.

**How to fix it**:

1. First, check if the file exists inside the Docker container:

   ```bash
   docker compose run --rm -e KEYBOARD="modelm/enhanced" builder ls -l /build
   ```

2. If you see the file listed, but it's not in your local `build/` folder, check your [`docker-compose.yml`](../../docker-compose.yml):

   ```yaml
   volumes:
     - ./build:/build
   ```

   This line should be present in the `builder` service definition.

3. Try removing the build directory and starting fresh:

   ```bash
   rm -rf build/
   mkdir build
   docker compose run --rm -e KEYBOARD="modelm/enhanced" builder
   ```

---

### ❌ Permission denied (Linux only)

**What this means**: Docker's created files owned by a different user (UID 1001), and your user can't access them.

**How to fix it**:
Run this command from your project root directory:

```bash
sudo chown -R $USER:$USER build/
```

This changes ownership of all the files in `build/` to your user account.

**Note**: The Docker container runs as UID 1001 by default (defined in [`docker-compose.yml`](../../docker-compose.yml)). If this frequently causes issues on your system, you can modify the `user:` line in `docker-compose.yml` to match your user ID.

---

### Verify Docker Installation

If build issues persist:

1. **Check your Docker installation**:

   ```bash
   docker --version
   docker compose version
   ```

   You should see version numbers. If you get "command not found", Docker isn't installed correctly.

2. **Try a clean rebuild**:

   ```bash
   rm -rf build/*
   docker compose build builder --no-cache
   docker compose run --rm -e KEYBOARD="modelm/enhanced" builder
   ```

3. **Ask for help**: Visit [GitHub Discussions](https://github.com/PaulW/rp2040-keyboard-converter/discussions) with:
   - Your operating system (Windows, macOS, Linux)
   - The full error message
   - The keyboard configuration you're trying to build

---

## Advanced: Rebuilding After Changes

As you use your converter, you might want to rebuild the firmware after making changes or trying out different keyboard configurations.

### Rebuilding with the Same Configuration

If you modify source code or configuration files, just run the build command again:

```bash
docker compose run --rm -e KEYBOARD="modelm/enhanced" builder
```

The build process runs from scratch each time—the Docker entrypoint script automatically cleans all build artifacts before compiling to ensure a fresh, consistent build every time.

**Duration**: 30-60 seconds

### Switching Keyboard Configurations

Want to try a different keyboard? Just change the `KEYBOARD` parameter:

```bash
docker compose run --rm -e KEYBOARD="amiga/a500" builder
```

The build system automatically includes the new keyboard's protocol, scancode set, and keymap. The output file (`rp2040-converter.uf2`) is overwritten with the new configuration.

### Updating Build Tools (Rare)

If the project updates its build dependencies or Pico SDK version, you'll need to rebuild the Docker image:

```bash
docker compose build builder --no-cache
```

The `--no-cache` flag forces Docker to rebuild from scratch, ignoring cached layers. This takes 5-10 minutes but ensures you have the latest build environment.

---

## Build System Details

### What Gets Included?

The build system automatically includes based on your configuration:

**Always included:**

- Core firmware ([`src/main.c`](../../src/main.c))
- USB HID interface ([`src/common/lib/hid_interface.c`](../../src/common/lib/hid_interface.c), [`hid_interface.h`](../../src/common/lib/hid_interface.h))
- Ring buffer implementation ([`src/common/lib/ringbuf.c`](../../src/common/lib/ringbuf.c), [`ringbuf.h`](../../src/common/lib/ringbuf.h))
- Command Mode ([`src/common/lib/command_mode.c`](../../src/common/lib/command_mode.c), [`command_mode.h`](../../src/common/lib/command_mode.h))
- TinyUSB stack (from Pico SDK)

**Configuration-dependent:**

- Protocol handler: [`src/protocols/`](../../src/protocols/)`<protocol>/` (from `keyboard.config`, see [Protocols](../protocols/README.md))
- Scancode processor: [`src/scancodes/`](../../src/scancodes/)`<set>/` (from `keyboard.config`, see [Scancode Sets](../scancodes/README.md))
- PIO programs: [`src/protocols/`](../../src/protocols/)`<protocol>/*.pio` (compiled to headers)
- Keyboard layout: [`src/keyboards/`](../../src/keyboards/)`<brand>/<model>/keyboard.c` (see [Keyboards](../keyboards/README.md))

### Build Outputs Explained

| File | Purpose | Size |
| --- | --- | --- |
| `rp2040-converter.uf2` | Flashable firmware (drag-and-drop) | ~80-120 KB  |
| `rp2040-converter.elf` | Binary with debug symbols | ~1-2 MB |
| `rp2040-converter.elf.map` | Memory layout and symbol addresses | ~400-600 KB |

**For flashing**: You only need the `.uf2` file.

**For debugging**: Use `.elf` with GDB or ARM debugger.

**Note**: File sizes are approximate and vary based on keyboard configuration, compile-time options, and code changes.

---

## Next Steps

Now that you have compiled firmware, proceed to:

**→ [Flashing Firmware](flashing-firmware.md)** - Install firmware on your RP2040 board

**Additional Resources:**

- [Hardware Setup](hardware-setup.md) - Physical wiring guide
- [Supported Keyboards](../keyboards/README.md) - Keyboard-specific details
- [Development Guide](../development/README.md) - Adding new keyboards or protocols
- [Build System Architecture](../advanced/build-system.md) - Technical deep-dive

---

## Quick Reference

Once you're familiar with the process, here's the condensed version:

**First-time setup:**

```bash
git clone https://github.com/PaulW/rp2040-keyboard-converter.git
cd rp2040-keyboard-converter
docker compose build builder
docker compose run --rm -e KEYBOARD="modelm/enhanced" builder
```

**Rebuild after changes:**

```bash
docker compose run --rm -e KEYBOARD="modelm/enhanced" builder
```

**Output location:**

```text
./build/rp2040-converter.uf2
```

**Find available keyboards:**

```bash
find src/keyboards -name "keyboard.config"
```

---

**[← Previous: Hardware Setup](hardware-setup.md)** | **[Next: Flashing Firmware →](flashing-firmware.md)**

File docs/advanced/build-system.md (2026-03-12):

# Build System

The build system transforms keyboard configuration into protocol-specific firmware through Docker and CMake. Set `KEYBOARD=modelm/enhanced` and the system locates the configuration, includes the protocol handler, compiles PIO programs, and links the keymap automatically.

---

## Overview

When you specify `KEYBOARD=modelm/enhanced` during build, the system locates your keyboard configuration, pulls in the appropriate protocol handler and scancode processor, compiles the matching PIO program, and links your keyboard-specific keymap.

The build produces three artifacts:

- **rp2040-converter.uf2** - Drag-and-drop firmware file for flashing
- **rp2040-converter.elf** - Debugger-compatible binary with symbols
- **rp2040-converter.elf.map** - Memory layout analysis file

---

## Build Process

### Docker Environment

The Docker-based build environment ensures reproducible builds by including a pinned version of **Pico SDK 2.2.0** with all necessary toolchain components. This produces bit-identical builds on macOS, Linux, or Windows without requiring manual ARM cross-compiler installation or SDK path configuration.

**Build the Docker image** (one-time setup):

```bash
docker compose build
```

**Build firmware for a specific keyboard:**

```bash
docker compose run --rm -e KEYBOARD="modelm/enhanced" builder
```

**Build with mouse support:**

```bash
docker compose run --rm -e KEYBOARD="modelm/enhanced" -e MOUSE="at-ps2" builder
```

The Docker container includes:

- ARM GCC cross-compiler toolchain
- CMake 3.13+ with Pico SDK integration
- Pico SDK 2.2.0 (pinned version via git submodule)
- Python 3 for build scripts
- All dependencies for parallel builds

Build time is influenced by CPU core count and single-core performance, disk I/O speed (SSD vs HDD), and available memory. Parallel compilation (`make -jN`) distributes independent translation units across CPU cores. Incremental compilation avoids recompiling unchanged translation units, so only modified files and their dependents are rebuilt.

---

## Configuration Files

### keyboard.config

Each keyboard has a [`keyboard.config`](../../src/keyboards/modelm/enhanced/keyboard.config) file in its directory: [`src/keyboards/`](../../src/keyboards/)`<brand>/<model>/keyboard.config`

**Format** (simple key=value pairs):

```bash
# src/keyboards/modelm/enhanced/keyboard.config
MAKE=IBM
MODEL=Model M Enhanced PC Keyboard
DESCRIPTION=IBM Personal Computer AT Enhanced Keyboard
PROTOCOL=at-ps2
CODESET=set123
```

**Configuration variables:**

- **MAKE:** Manufacturer name (appears in boot messages)
- **MODEL:** Keyboard model designation
- **DESCRIPTION:** Full description (appears in boot messages)
- **PROTOCOL:** Protocol handler to include — see [`src/protocols/`](../../src/protocols/) for available implementations
- **CODESET:** Scancode processor to use — see [`src/scancodes/`](../../src/scancodes/) for available options

The build system reads these values and automatically includes the appropriate components.

---

## CMake Structure

### Top-Level CMakeLists.txt

The top-level [`CMakeLists.txt`](../../src/CMakeLists.txt) orchestrates the build:

1. **Read keyboard.config** - Parses the configuration file for the specified `KEYBOARD` environment variable
2. **Include protocol handler** - Adds the appropriate protocol implementation from [`src/protocols/`](../../src/protocols/)
3. **Include scancode processor** - Adds the scancode decoder from [`src/scancodes/`](../../src/scancodes/)
4. **Compile PIO programs** - Generates C headers from `.pio` assembly files
5. **Include keyboard keymap** - Adds the keyboard-specific layout from [`src/keyboards/`](../../src/keyboards/)
6. **Configure binary type** - Sets SRAM execution mode: `pico_set_binary_type(copy_to_ram)`
7. **Link TinyUSB** - Includes USB stack and HID interface
8. **Generate outputs** - Produces UF2, ELF, and MAP files

**Key CMake configuration (line 93):**

```cmake
pico_set_binary_type(${PROJECT_NAME} copy_to_ram)
```

This instructs the linker to copy the entire program from flash into SRAM during boot, ensuring deterministic execution timing. See [Architecture - SRAM Execution](architecture.md#sram-execution) for rationale.

### Dependency Tracking

CMake tracks all dependencies automatically:

- Changing a protocol's `.pio` file triggers PIO recompilation and relinking
- Modifying a keyboard's keymap triggers recompilation of that keyboard configuration
- Updating common libraries triggers recompilation of all files that include them
- Header file changes trigger recompilation of dependent source files

This dependency tracking ensures incremental builds work correctly—you only recompile what's changed.

---

## PIO Program Compilation

PIO assembly files (`.pio`) contain the timing logic that runs on the RP2040's PIO hardware state machines. The build system compiles these into C headers during the build process.

**PIO compilation process:**

1. **pioasm tool** reads `.pio` files from protocol directories
2. Assembles PIO instructions into binary format
3. Generates C header with program constants and helper functions
4. Header includes `pio_program_t` structure for loading into hardware

**Example:** [`src/protocols/at-ps2/interface.pio`](../../src/protocols/at-ps2/interface.pio) compiles to `interface.pio.h`, which provides:

- `pio_interface_program` - PIO instruction array
- `pio_interface_program_init()` - Helper to configure state machine
- `pio_interface_wrap_target` / `pio_interface_wrap` - Program loop bounds
- Instruction count and origin information

The build system automatically discovers `.pio` files in protocol directories and compiles them. No manual configuration needed.

---

## Memory Management

### Build Output Analysis

The linker reports memory usage during build:

```text
Memory region         Used Size  Region Size  %age Used
           FLASH:      95284 B         2 MB      4.55%
             RAM:      71432 B       264 KB     26.42%
```

**Flash usage:** Program code and constant data stored persistently
**RAM usage:** Code execution space (copied from flash) + variables + stack

The converter executes from RAM (copy_to_ram), so the program consumes space in both flash (storage) and RAM (execution). This is intentional for deterministic timing.

### Memory Limits

CI enforcement in [`.github/workflows/ci.yml`](../../.github/workflows/ci.yml) fails builds exceeding:

- **Flash:** 230KB (11.5% of 2MB capacity)
- **RAM:** 150KB (56.8% of 264KB capacity)

These limits provide comfortable margins whilst preventing configurations that approach resource boundaries.

### Memory Map Analysis

The `.elf.map` file shows detailed memory layout:

```text
.text           0x20000000    0x15abc  # Code section in SRAM
.rodata         0x20015abc    0x2f40   # Read-only data
.data           0x200189fc    0x1d0    # Initialised data
.bss            0x20018bcc    0x3e8    # Uninitialised data
```

Use this file to:

- Verify code executes from SRAM addresses (0x20000000-0x20042000)
- Identify large functions or data structures
- Analyze stack usage and placement
- Debug linker errors about overlapping sections

---

## Build Configurations

### Keyboard-Only Build

Standard build with keyboard support only:

```bash
docker compose run --rm -e KEYBOARD="modelm/enhanced" builder
```

Produces firmware with:

- Selected keyboard protocol (see [`src/protocols/`](../../src/protocols/))
- Selected scancode processor
- Keyboard keymap
- Command Mode, logging, configuration storage
- No mouse support

### Keyboard + Mouse Build

Build with both keyboard and AT/PS2 mouse support:

```bash
docker compose run --rm -e KEYBOARD="modelm/enhanced" -e MOUSE="at-ps2" builder
```

Adds mouse protocol handler with:

- Separate PIO state machine for mouse protocol
- Independent CLK/DATA lines (dedicated GPIO pins)
- 3-byte or 4-byte packet decoding (standard and scroll wheel)
- Mouse HID interface alongside keyboard interface

Mouse support works with **any keyboard protocol**—the mouse uses its own AT/PS2 implementation on separate hardware lines.

### Mouse-Only Build

Build with only mouse support (no keyboard):

```bash
docker compose run --rm -e MOUSE="at-ps2" builder
```

Produces minimal firmware for mouse-only operation.

---

## Build Optimisation

### Compiler Flags

The build uses optimisation flags appropriate for embedded systems:

**Default optimisation:** `-O2` (optimise for speed with size consideration)

- Balances performance and code size
- Enables compiler optimisations including inlining, constant propagation, and dead code elimination whilst balancing code size
- Suitable for production use

**Debug builds:** `-Og` (optimise for debugging)

- Preserves debug information quality
- Minimal optimisations to keep code structure recognisable
- Used for GDB debugging sessions

**Size optimisation:** `-Os` (optimise for size)

- Prioritizes small code size over speed
- Useful for configurations approaching memory limits
- Not currently used—plenty of headroom with `-O2`

### Link-Time Optimisation (LTO)

LTO optimises across translation units during linking:

- Inlines functions across file boundaries
- Eliminates dead code more aggressively
- Reduces binary size by eliminating unused code

Currently **not enabled** to keep build times fast and debugging straightforward. Could be enabled if memory becomes constrained.

---

## Parallel Builds

The Docker container supports parallel compilation:

```bash
# Use all available CPU cores
docker compose run --rm -e KEYBOARD="modelm/enhanced" builder

# Limit to specific number of jobs
docker compose run --rm -e KEYBOARD="modelm/enhanced" -e CMAKE_BUILD_PARALLEL_LEVEL=4 builder
```

Incremental builds only recompile changed files.

---

## Build Troubleshooting

### Common Build Errors

**Error: keyboard.config not found**

```text
CMake Error: keyboard.config missing for KEYBOARD=modelm/enhanced
```

**Solution:** Verify the `KEYBOARD` environment variable matches a directory under [`src/keyboards/`](../../src/keyboards/). Check spelling and path structure.

**Error: Undefined reference to protocol\_\*\_init**

```text
undefined reference to `at_ps2_keyboard_interface_init'
```

**Solution:** The `PROTOCOL` value in keyboard.config doesn't match any implemented protocol. Check [`src/protocols/`](../../src/protocols/) for available options.

**Error: PIO program too large**

```text
PIO program exceeds available instruction memory
```

**Solution:** PIO blocks have 32 instructions each. Some complex protocols require optimisation or splitting across multiple state machines.

**Error: Region RAM overflowed**

```text
region `RAM' overflowed by XXXX bytes
```

**Solution:** Configuration exceeds 264KB SRAM. Either:

- Reduce feature set (disable mouse, logging, etc.)
- Optimise code (smaller functions, fewer globals)
- Request CI limit increase if usage is reasonable

### Build Verification

After building, verify the firmware:

1. **Check memory usage:** Look for "Memory region" output showing Flash/RAM consumption
2. **Verify UF2 exists:** `build/rp2040-converter.uf2` should be present and >100KB
3. **Check MAP file:** `build/rp2040-converter.elf.map` shows memory layout
4. **Test on hardware:** Flash to RP2040 and verify boot messages via UART

---

## CI/CD Pipeline

### Continuous Integration

The CI pipeline (see [`.github/workflows/ci.yml`](../../.github/workflows/ci.yml)) builds every configuration in the keyboard matrix on every commit:

**Build matrix:**

- All keyboards in [`src/keyboards/`](../../src/keyboards/)
- With and without mouse support
- Debug and release builds

**Automated checks:**

- Lint script must pass ([`tools/lint.sh`](../../tools/lint.sh))
- All configurations must compile successfully
- Memory limits enforced (230KB Flash, 150KB RAM)
- PIO programs must compile without errors
- No blocking operations or multicore APIs detected

Builds run on Ubuntu latest with the same Docker container used for local builds, ensuring consistency between development and CI environments.

### Memory Limit Enforcement

CI fails builds exceeding memory thresholds:

```yaml
- name: Check memory limits
  run: |
    FLASH=$(grep "FLASH:" build_output.txt | awk '{print $2}')
    RAM=$(grep "RAM:" build_output.txt | awk '{print $2}')
    [ $FLASH -lt 235520 ] || exit 1  # 230KB
    [ $RAM -lt 153600 ] || exit 1    # 150KB
```

This prevents accidental resource overruns and ensures all configurations remain within comfortable margins.

---

## Development Workflow

### Typical Development Cycle

1. **Modify source code** - Edit protocol handlers, keymaps, or core libraries
2. **Build locally** - Test compilation with Docker
3. **Flash to hardware** - Copy UF2 to RP2040 bootloader
4. **Test functionality** - Verify changes work as expected
5. **Check UART output** - Monitor debug logs for errors
6. **Run lint script** - Ensure no architecture violations
7. **Commit changes** - Push to repository
8. **CI verification** - Automated builds test all configurations

### Iterative Testing

For rapid iteration during development:

```bash
# Build, flash, test loop
while true; do
    docker compose run --rm -e KEYBOARD="modelm/enhanced" builder
    cp build/rp2040-converter.uf2 /Volumes/RPI-RP2/
    # Wait for device to reboot and test
    sleep 5
done
```

The RP2040 bootloader accepts UF2 files via drag-and-drop or command-line copy. Device reboots automatically after flashing.

---

## Related Documentation

- [Architecture](architecture.md) - SRAM execution rationale and memory layout
- [Performance](performance.md) - Resource utilisation and optimisation
- [Hardware Setup](../getting-started/hardware-setup.md) - Physical connections
- [Building Firmware](../getting-started/building-firmware.md) - Step-by-step build guide
- [Flashing Firmware](../getting-started/flashing-firmware.md) - UF2 installation
- [Adding Keyboards](../development/adding-keyboards.md) - Creating new configurations
- [Code Standards](../development/code-standards.md) - Build system conventions

---

**Questions or build issues?**
Use [GitHub Discussions](https://github.com/PaulW/rp2040-keyboard-converter/discussions) or [open an issue](https://github.com/PaulW/rp2040-keyboard-converter/issues) if you've found a problem.

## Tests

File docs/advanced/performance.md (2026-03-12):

# Performance Characteristics

These performance characteristics are based on the RP2040 hardware specifications and what's implemented in the source code. Where specific figures appear, they come from the RP2040 datasheet or direct inspection of the implementation.

---

## Design Characteristics

The design prioritises deterministic, low-latency operation through hardware acceleration and non-blocking architecture. Deterministic timing means the converter behaves identically across executions—no variable delays from caching, no race conditions from multicore synchronisation.

---

## Processing Pipeline

Each key press flows through distinct stages that operate without blocking each other:

1. **PIO Hardware Capture** - The RP2040's PIO state machines monitor keyboard protocol signals (clock and data lines) and assemble bits into complete scancodes. This happens entirely in hardware without CPU involvement.

2. **Interrupt Handler** - When a complete byte arrives, the PIO triggers an interrupt. The handler extracts the scancode and writes it to the ring buffer—a minimal operation taking only a few CPU cycles.

3. **Ring Buffer** - The [32-byte FIFO](../../src/common/lib/ringbuf.c) (defined as `RINGBUF_SIZE` in [ringbuf.h](../../src/common/lib/ringbuf.h)) bridges interrupt context and main loop. Its size provides sufficient capacity for multibyte scancode sequences arriving back-to-back whilst keeping the working set tiny for fast SRAM access.

4. **Scancode Decoder** - The main loop retrieves scancodes from the buffer and reconstructs complete key events. Some protocols use multibyte sequences (E0 prefixes, F0 break codes, the eight-byte Pause key), so the decoder maintains state across multiple reads.

5. **Keymap Translation** - Complete scancodes translate to USB HID keycodes via keyboard-specific lookup tables. Command Mode detection also happens here, intercepting special key combinations before they reach USB.

6. **HID Report Assembly** - The HID interface collects keycodes into USB boot protocol reports (six-key rollover format). Reports only send when `tud_hid_ready()` confirms the USB host is ready to receive.

7. **USB Transmission** - TinyUSB handles the low-level USB communication, transmitting reports during the host's polling interval.

This pipeline design keeps interrupt handlers minimal (microseconds), maintains non-blocking operations throughout, and leverages PIO hardware for protocol timing precision.

---

## System Timing

The RP2040 and USB host impose specific timing constraints that shape the converter's performance:

### CPU and PIO

The RP2040 runs at **125 MHz** by default (configurable, but the converter uses the default). This provides **8 nanosecond instruction cycles**—fast enough that protocol timing is never CPU-limited.

PIO state machines execute independently at the same clock rate, handling protocol timing autonomously:

- **AT/PS2 keyboards:** 10-16.7 kHz clock frequency (60-100 microseconds per bit)
- **XT keyboards:** ~10 kHz clock frequency (approximately 100 microseconds per bit)
- **Amiga keyboards:** ~16.7 kHz synchronous protocol
- **Apple M0110:** Keyboard→Host clock ~3.03 kHz, 330µs period (160µs LOW / 170µs HIGH); Host→Keyboard clock ~2.5 kHz, 400µs period (180µs LOW / 220µs HIGH)

The PIO hardware samples data lines at precise clock edges, shifts bits into registers, and triggers interrupts only when complete bytes arrive. Zero CPU overhead during bit reception.

### USB Polling

USB polling operates at **8 millisecond intervals** (configured via `bInterval = 8` in [usb_descriptors.c](../../src/common/lib/usb_descriptors.c)). This is the USB specification's full-speed polling rate for HID devices.

**Theoretical maximum throughput:** 125 reports per second (1000ms ÷ 8ms). In practice, human typing rarely exceeds 10-15 characters per second, leaving substantial headroom. Boot protocol reports support six simultaneous keys (6KRO), which accommodates even fast gaming inputs.

The USB polling interval represents the primary throughput bottleneck—not the processing pipeline. Even if the converter processed scancodes instantaneously, it could only send data as fast as the USB host polls.

---

## Resource Utilisation

The converter's resource usage is tracked against CI-enforced build limits:

### Memory

The RP2040 provides **264KB of SRAM** and **2MB of flash storage**. The converter executes entirely from SRAM (see [SRAM Execution](architecture.md#sram-execution) for why), consuming space in both flash (for persistent storage) and SRAM (for execution).

**Build limits** (enforced by CI in [`.github/workflows/ci.yml`](../../.github/workflows/ci.yml)):

- **Flash usage:** < 230KB (11.5% of 2MB capacity)
- **SRAM usage:** < 150KB (56.8% of 264KB capacity)

Actual usage varies by configuration—check the memory region summary in the build output for the exact figures for your build.

The 32-byte ring buffer fits entirely in on-chip SRAM and constitutes a small, fixed working set that remains resident there during operation. Global variables store protocol state, HID report buffers, and configuration values. The stack handles function call depth and local variables. The heap remains minimal—the code favours stack allocation to avoid fragmentation and memory leaks.

### CPU Utilisation

The non-blocking architecture keeps the CPU idle between keyboard events. PIO hardware handles protocol timing autonomously, so the CPU only wakes for complete scancodes.

**CPU usage patterns:**

- Idle (waiting for scancodes): mostly idle between keyboard events
- Processing scancodes: brief processing bursts per received byte
- USB communication: aligned with host polling (8ms intervals)

The converter doesn't perform continuous polling or busy-waiting—everything operates on interrupts or time-based state machines that check timestamps without blocking.

---

## Protocol Timing

Each keyboard protocol operates at different speeds with distinct timing characteristics. The PIO hardware handles these requirements automatically, but understanding the timing helps when debugging protocol issues or adding new protocol support.

### AT/PS2 Protocol

**Clock frequency:** 10-16.7 kHz (typical 10-15 kHz)
**Frame format:** 11 bits (start, 8 data, parity, stop)
**Frame duration:** ~1 millisecond at 10 kHz
**Bidirectional:** Host can send commands by pulling clock low

The PIO program samples data on clock falling edges, assembles bytes, and validates parity. When sending commands to the keyboard (LED updates, configuration), the PIO generates clock pulses at the same frequency.

### XT Protocol

**Clock frequency:** ~10 kHz
**Frame format:** 8 bits plus stop bit
**Unidirectional:** Keyboard to host only
**Simpler timing:** No bidirectional clock coordination required

The XT PIO program is simpler than AT/PS2 because it only needs to monitor signals, not generate them.

### Amiga Protocol

**Clock frequency:** ~16.7 kHz (derived from master clock)
**Frame format:** Synchronous handshake + 7-bit key codes
**Bidirectional:** Host provides reset pulse, keyboard responds

Timing is stricter than AT/PS2 or XT because both sides must coordinate around specific intervals. The PIO manages handshake sequences with precise timing.

### Apple M0110 Protocol

**Variable timing:** Adapts to signal conditions
**Complex state machine:** Multiple timing phases

The PIO implements state machine transitions required by this more complex protocol.

---

## Latency Analysis

Whilst the converter hasn't been measured with hardware timing equipment, the architecture's design characteristics provide insight into expected latency:

### Sources of Latency

1. **Keyboard protocol transmission:** Inherent to the protocol (1-2 milliseconds for AT/PS2 11-bit frame at 10 kHz)
2. **PIO to IRQ:** Hardware interrupt latency on RP2040
3. **Ring buffer transfer:** Interrupt handler writes, main loop reads (sub-microsecond operation)
4. **Scancode processing:** State machine handles multibyte sequences (microseconds)
5. **Keymap lookup:** Array index operation (nanoseconds)
6. **HID report assembly:** Struct manipulation (nanoseconds)
7. **USB polling wait:** Host queries device every 8ms (average 4ms wait)

The protocol transmission and USB polling are expected to dominate total latency; processing overhead (steps 2–6) is expected to be small relative to protocol and USB timing.

### Deterministic Timing

The converter's architecture ensures **deterministic timing**—latency remains consistent across executions:

- **SRAM execution:** Every instruction takes the same time, regardless of cache state
- **Non-blocking operations:** No variable delays from sleep calls or busy-waiting
- **PIO hardware timing:** Protocol handling happens at fixed clock rates
- **Single-core design:** No inter-core synchronisation overhead or race conditions

This determinism makes the converter's behaviour predictable and repeatable.

---

## Throughput Limits

The USB polling interval (8ms) imposes a hard limit on throughput:

**Maximum theoretical:** 125 reports/second (6 keys per report = 750 keypresses/second)
**Human typing speed:** 10-15 characters/second typical, 20-30 characters/second for fast typists
**Gaming inputs:** Even rapid gaming rarely exceeds 30 inputs/second

The converter provides substantial headroom above human input speeds. The 6KRO (six-key rollover) boot protocol format accommodates modifier combinations and multi-key gaming inputs without conflicts.

**Burst handling:** The 32-byte ring buffer accommodates short bursts where multiple scancodes arrive faster than USB can transmit them. The buffer drains during the next available USB polling window.

---

## Optimisation Opportunities

The current implementation prioritises correctness and determinism over raw performance. Several optimisation opportunities exist for future development:

### Potential Optimisations

1. **NKRO (N-Key Rollover):** Switch from boot protocol (6KRO) to NKRO HID descriptor for unlimited simultaneous keys. Requires host driver support.

2. **USB polling interval:** Could negotiate faster polling (1ms minimum for full-speed USB) with compatible hosts. Requires USB descriptor changes and host compatibility testing.

3. **PIO program efficiency:** Some PIO programs could be optimised for fewer instructions or faster execution. Current implementations prioritise readability and maintainability.

4. **Scancode processor:** Could use lookup tables instead of state machines for protocols with simpler multibyte sequences. Trade-off between code size and execution speed.

5. **Ring buffer size tuning:** Could reduce to 16 bytes (still ample for burst handling) to improve cache utilisation. Requires testing with worst-case multibyte sequences.

These optimisations are not currently implemented. No hardware timing measurements have been performed to establish whether they would be beneficial.

---

## Benchmarking Methodology

For those wanting to measure actual hardware performance:

### Recommended Tools

1. **Logic analyzer:** Capture keyboard protocol signals and USB traffic simultaneously. Measure time from keyboard clock edge to USB D+ transition.

2. **USB analyzer:** Monitor USB packets to verify polling intervals and report timing. Beagle USB analyzers or software capture with Wireshark.

3. **Oscilloscope:** Observe signal quality, measure rise/fall times, identify noise or ringing that affects timing.

4. **UART logging:** Enable DEBUG logging level and capture timestamps. The converter logs timing information for protocol events.

### Measurement Points

- **Protocol latency:** Time from keyboard clock edge to ring buffer write
- **Processing latency:** Time from ring buffer read to HID report ready
- **USB latency:** Time from HID report ready to USB transmission complete
- **End-to-end latency:** Time from keyboard clock edge to USB D+ transition

### Considerations

- Test with multiple keyboard models—protocol timing varies between manufacturers
- Test with different USB hosts—some hosts have higher polling latency than others
- Test under load—measure latency during fast typing, not just single keypresses
- Test multibyte sequences—extended keys (E0 prefix) and Pause key (11 bytes) have different timing

---

## Related Documentation

- [Architecture](architecture.md) - System architecture and design principles
- [Build System](build-system.md) - Build configuration and optimisation
- [Testing](testing.md) - Hardware testing and validation procedures
- [Protocol Documentation](../protocols/README.md) - Protocol timing specifications
- [Code Standards](../development/code-standards.md) - Non-blocking requirements

---

**Questions or need clarification?**
Use [GitHub Discussions](https://github.com/PaulW/rp2040-keyboard-converter/discussions) or [open an issue](https://github.com/PaulW/rp2040-keyboard-converter/issues) if you've found a problem.

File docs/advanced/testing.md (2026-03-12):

# Testing and Validation

Testing the converter properly means more than just checking that keys produce the right characters. You want to verify it handles real keyboards reliably, catches issues early, and maintains code quality throughout.

---

## Hardware Testing

Verifying the converter with actual keyboards goes beyond confirming correct typing. Software testing alone won't catch marginal signal integrity issues that work with one keyboard but fail with another, timing violations that only show up under specific conditions, electrical problems like insufficient voltage levels, or protocol edge cases where real keyboards behave differently than the specifications suggest.

Hardware testing catches these problems during development, before they appear as intermittent failures in production use.

The timing-sensitive nature of keyboard protocols means issues often hide until you test with actual hardware. A keyboard that works perfectly on the bench might fail when connected through a longer cable, or a protocol implementation that passes all software tests might miss edge cases that only specific keyboard models trigger.

---

## Essential Test Equipment

### Logic Analyser

A logic analyser captures the actual clock and data signals between keyboard and converter, showing precisely what's happening on the wire.

I use [Scoppy](https://github.com/fhdm-dev/scoppy) — a Raspberry Pi Pico-based logic analyser and oscilloscope with 8 channels and 25MS/s logic analyser mode, using an Android device as the display. It's free to download and requires no programming to set up.

**What to verify:**

- Clock frequencies match protocol specifications (10-16.7 kHz for AT/PS2, ~10 kHz for XT)
- Data transitions occur at correct clock edges (rising vs falling)
- Setup and hold times meet protocol requirements
- Converter's signal timing meets keyboard requirements (for bidirectional protocols)

**Protocol decoders:** Some logic analyser software includes AT/PS2 and UART decoders. These interpret captured waveforms automatically, showing scancodes and protocol errors without manual bit counting.

### USB-UART Adapter

A USB-UART adapter connects to the RP2040's UART pins (GPIO 0/1) to display diagnostic logging output.

**Requirements:**

- **3.3V logic levels** (5V adapters may damage RP2040)
- **TX, RX, GND connections** (no need for power pins)
- **115200 baud rate** (default UART configuration)

**What you'll see:**

- Protocol state transitions (initialisation, LED commands, etc.)
- Error conditions (`[ERR]` messages for protocol violations)
- Received scancodes in hexadecimal
- Timing measurements and performance data
- Command Mode activation and menu responses

Enable verbose logging during testing to maximise visibility. See the [Logging guide](../features/logging.md) for configuration options.

### Multimeter

A basic multimeter verifies voltage levels and continuity.

**Signal level verification:**

- Measure keyboard's CLK and DATA lines: Should be 5V (or 3.3V for some modern keyboards)
- Measure level shifter output: Should be 3.3V when interfacing with RP2040
- Verify clean high and low levels: No intermediate voltages indicating poor connections

**Connection testing:**

- Check continuity between keyboard connector and level shifter
- Verify level shifter connections to RP2040 GPIO pins
- Test ground connections (keyboard GND to level shifter to RP2040)

### Oscilloscope (Optional)

An oscilloscope reveals signal quality issues that logic analysers might miss.

**What to observe:**

- **Rise and fall times:** Should be clean transitions without excessive ringing
- **Signal overshoot:** Excessive overshoot indicates impedance mismatches
- **Noise:** Random voltage fluctuations on clock or data lines
- **Voltage sag:** Power supply issues or insufficient current capacity

Oscilloscopes are optional for basic testing but valuable when debugging timing issues or signal integrity problems.

---

## Testing Scenarios

### Basic Functionality Test

Start with the fundamentals—test that all keys work correctly under normal use.

Connect your keyboard to the converter, plug the converter into your computer, and verify it enumerates as a USB HID device. Type through the alphabet (a-z), numbers (0-9), and punctuation to make sure the basics work. Test all the modifier keys—Shift, Ctrl, Alt, and the GUI key (Windows/Command depending on your OS). Go through the function keys, both F1-F12 and F13-F24 if your keyboard has them. Check the navigation cluster: arrows, Home, End, PgUp, PgDown, Insert, and Delete. Test the numpad with Num Lock both on and off. Finally, verify special keys like Escape, Tab, Caps Lock, Backspace, and Enter all behave correctly.

Every key should produce the correct character or action. No missed keypresses, no duplicate characters, no wrong characters appearing.

### Fast Typing Test

Stress-test the pipeline with rapid typing to see if the buffering and throughput hold up.

Type rapidly at 30 or more characters per second. Try burst typing—hold a key briefly, release it, then immediately repeat with different keys. Test simultaneous keypresses by holding multiple keys down at once. Watch for any dropped keypresses during fast input, and check the UART output for buffer full warnings that would indicate the system's struggling to keep pace.

All keypresses should register correctly. You shouldn't see any `[ERR]` messages about ring buffer overflow in the UART logs, and the converter should maintain pace with human typing speeds.

**Why 30 CPS?** This represents fast typing that tests the system under load without being unrealistic.

### Command Mode Test

Verify Command Mode activates and responds correctly to commands.

Hold both Shift keys simultaneously for 3 seconds and check for activation feedback (you'll see it in the UART logging, or via LED indicator if your keyboard supports that). Once activated, press the command keys to test each function: **B** enters bootloader mode (the device should disconnect and present the RP2040 drive for firmware updates), **D** cycles through log levels, **F** does a factory reset (clearing configuration and returning to defaults), and **L** adjusts LED brightness if your protocol supports it. Make sure each command executes correctly, then test exiting Command Mode by pressing Escape or just waiting for the timeout.

Command Mode should activate after the 3-second hold, all commands should execute as documented, and normal typing should resume properly after you exit.

**Note:** If your keyboard has a non-standard modifier layout (like the Apple M0110A with its single Shift key), verify the override keys work correctly. See [`keyboard.h`](../../src/keyboards/apple/m0110a/keyboard.h) for examples of how to configure alternative activation keys.

### LED Indicator Test

Test Caps Lock, Num Lock, and Scroll Lock indicators (if protocol supports LEDs).

**Test procedure:**

1. Press Caps Lock - LED should toggle on/off
2. Press Num Lock - LED should toggle on/off
3. Press Scroll Lock - LED should toggle on/off
4. Verify LED state persists after key release
5. Check UART output for LED command sequences

**Expected results:** LEDs update immediately when lock keys are pressed. No delay or flickering. LED state matches lock key state.

**Protocol support:**

- **AT/PS2:** Full LED support (Caps, Num, Scroll)
- **XT:** No LED support (unidirectional protocol)
- **Amiga:** Caps Lock only (pulse-duration based)
- **M0110:** No built-in LED support

### Protocol Error Recovery Test

Verify the converter recovers gracefully from protocol errors.

**Test procedure:**

1. Start with converter operating normally
2. Power-cycle keyboard whilst converter is running:
   - Unplug keyboard connector
   - Wait 2-3 seconds
   - Reconnect keyboard
3. Verify converter detects disconnection (UART shows protocol errors)
4. Verify converter reinitialises protocol automatically
5. Test keyboard functions normally after reconnection

**Expected results:** Converter detects keyboard disconnection and logs `[ERR]` messages. Whether it attempts automatic reinitialisation and resumes normal operation depends on the protocol implementation — behaviour is protocol-dependent. Check the UART output and the relevant protocol documentation to understand what recovery, if any, is expected for your specific configuration.

**Common scenarios:**

- Keyboard unplugged during use
- Keyboard power-cycled (USB hub reset)
- Protocol timing violations during initialisation
- Transient electrical issues causing garbage scancodes

### Multi-OS Compatibility Test

Test the converter with multiple host operating systems to ensure HID compatibility.

**Test procedure:**

1. Test on **Windows** (7, 10, 11) - Verify HID enumeration and keystrokes
2. Test on **macOS** (10.15+) - Check modifier key mapping and special keys
3. Test on **Linux** (Ubuntu, Fedora, etc.) - Verify keyboard works in console and X11
4. Test special scenarios:
   - BIOS/UEFI firmware (boot protocol fallback)
   - USB hubs (some hubs have higher polling latency)
   - KVM switches (some pause USB polling during switching)

**Expected results:** Boot Protocol provides a consistent baseline for USB HID enumeration across major platforms, but exact behaviour (modifier key handling, special key mapping) may vary between operating systems.

### Extended Key Test

Test keys that use multibyte scancode sequences.

**Test procedure:**

1. **Extended keys (E0 prefix):**
   - Right Control, Right Alt, Right GUI
   - Navigation cluster (arrows, Home, End, PgUp, PgDown, Insert, Delete)
   - Numpad Enter and Numpad Slash
2. **Pause/Break key:** Press and verify correct handling (11-byte sequence in Set 2)
3. **Print Screen:** Press with and without modifiers
4. Check UART output to verify scancode sequences are decoded correctly

**Expected results:** All extended keys register correctly. Multibyte sequences are assembled properly. No spurious keypresses from sequence fragments.

---

## Code Quality Testing

### Lint Script

The [`tools/lint.sh`](../../tools/lint.sh) script scans the entire codebase for critical rule violations.

**What it detects:**

1. **Blocking operations:** `sleep_ms()`, `sleep_us()`, `busy_wait_ms()`, `busy_wait_us()`
2. **Multicore APIs:** `multicore_launch_core1`, `multicore_fifo_push_blocking`, `multicore_fifo_pop_blocking`, `multicore_fifo_drain`, `multicore_reset_core1`, `multicore_lockout` (forbidden — single-core architecture)
3. **printf in IRQ:** `printf()` calls in files containing `__isr` (use `LOG_*` macros)
4. **Ring buffer reset annotation:** `ringbuf_reset()` calls without required `// LINT:ALLOW ringbuf_reset` annotation (linter verifies annotation presence, not runtime IRQ protection)
5. **docs-internal exposure:** Ensures private docs never leak into repository
6. **Flash execution:** Missing `copy_to_ram` configuration in CMakeLists.txt
7. **IRQ variable safety:** Missing `volatile` or `__dmb()` barriers for IRQ-shared variables
8. **Tab characters:** Enforces no tab characters in source files (tabs are forbidden; use spaces)
9. **Header guards:** Missing `#ifndef`/`#define` guards in .h files
10. **File headers:** Missing GPL or MIT licence headers
11. **Naming conventions:** Detects camelCase (expects snake_case)
12. **Include order:** Validates include directive organisation
13. **IRQ handler attributes:** Missing `__isr` attribute on interrupt handlers
14. **Compile-time validation:** Advisory only (does not affect pass/fail) — counts `_Static_assert` and `#error` directives; reports if none are found, but does not fail the check
15. **Protocol ring buffer setup:** Missing `ringbuf_reset()` in keyboard protocol initialisation
16. **Protocol PIO IRQ dispatcher:** Missing centralised `pio_irq_dispatcher_init()` or deprecated direct `irq_set_priority()` usage
17. **Indentation consistency:** Enforces 4-space indentation width; detects files using 2-space base indentation
18. **Trailing whitespace:** No trailing spaces in `.c`/`.h` files; single trailing spaces disallowed in `.md` files (double trailing spaces permitted as Markdown hard line breaks)
19. **Local const hex-literal variables:** Detects `const TYPE var = 0x...` inside function bodies — algorithm and protocol constants must be file-scope `#define`s (clang-tidy does not catch this pattern)

**Run before every commit:**

```bash
./tools/lint.sh
```

**Expected result:** 0 errors, 0 warnings. Script exits with code 0.

**CI enforcement:** Pull requests automatically run lint checks in strict mode. Violations block merging.

**Detailed documentation:** See [`tools/lint.sh`](../../tools/lint.sh) for the definitive checklist and [`tools/README.md`](../../tools/README.md) for comprehensive check descriptions and fix examples.

### Static Analysis

The project uses [Clang-Tidy 19.1.7](https://discourse.llvm.org/t/llvm-19-1-7-released/84062) and [Cppcheck 2.19.0](https://cppcheck.sourceforge.io/) for language-level static analysis through the same Docker container used for firmware builds. Running the analyser locally lets you see and address any findings before they appear in code review.

Both tools run inside the same Docker build container used for firmware builds, so they see the exact compiler flags, include paths, and generated PIO header files that the real build uses. This matters because PIO headers (`.pio.h` files generated from `.pio` programs) don't exist until after the build step — running analysis without building first causes spurious missing-file errors.

**Running the analyser:**

```bash
# Build + analyse in one step (recommended)
docker compose run --rm -e KEYBOARD="modelf/pcat" analyser

# With a different configuration
docker compose run --rm -e KEYBOARD="modelm/enhanced" analyser
```

**What Clang-Tidy checks (`bugprone-*`, `clang-analyzer-*`, `cert-*`, `readability-*`):**

- Potential logic errors and incorrect API usage
- Null pointer dereferences, use-after-free, dead code
- CERT C secure coding rules
- Naming, clarity, and formatting issues

**What Cppcheck checks:**

- Performance and portability issues
- Missing or unresolvable include paths

**Suppressing a finding inline:**

If a finding is a known false positive, suppress it with an inline comment rather than adjusting the global configuration:

```c
// clang-tidy suppression
#define _TUSB_CONFIG_H_ // NOLINT(bugprone-reserved-identifier) -- required by TinyUSB

// cppcheck suppression
// cppcheck-suppress someCheckId
some_code_here;
```

See [`tools/README.md`](../../tools/README.md) for full documentation of the analysis pipeline.

### Memory Safety

The converter avoids dynamic allocation where possible, preferring stack-based allocation:

**Memory safety patterns:**

- **Stack allocation:** Local variables, function parameters, small buffers
- **Static allocation:** Protocol state, ring buffer, HID reports
- **No malloc/free:** Eliminates heap fragmentation and memory leaks
- **Bounds checking:** Array accesses validated before use
- **Const correctness:** Read-only data marked const

**Testing approach:**

- Build with address sanitiser (requires native build, not ARM cross-compile)
- Review .map file for unexpected heap usage
- Check stack usage doesn't exceed safe limits
- Verify no global variable overflow

---

## Continuous Integration

The CI pipeline (see [`.github/workflows/ci.yml`](../../.github/workflows/ci.yml)) builds every configuration on every commit:

**Build matrix:**

- All keyboards in [`src/keyboards/`](../../src/keyboards/)
- With and without mouse support
- Debug and release builds

**Automated checks:**

1. **Lint enforcement:** `tools/lint.sh` must pass
2. **Build verification:** All configurations must compile
3. **Memory limits:** Flash < 230KB, RAM < 150KB
4. **PIO compilation:** All .pio files must compile without errors
5. **Link verification:** No undefined references or multiple definitions

**When CI fails:**

- Check build log for specific error
- Reproduce locally: `docker compose run --rm -e KEYBOARD="..." builder`
- Fix issues and push updated code
- CI reruns automatically on push

---

## Regression Testing

Whilst the converter doesn't have automated unit tests (integration testing on hardware is more valuable for this project), manual regression testing catches issues:

**Regression test checklist:**

1. **Existing keyboards still work** - Test representative keyboards from each protocol
2. **Command Mode still functions** - Verify all commands work
3. **LEDs still update** - Test lock key indicators
4. **Protocol error recovery** - Power-cycle test
5. **Multibyte sequences** - Test extended keys and Pause
6. **Fast typing handling** - Burst typing test
7. **Build system works** - All configurations compile
8. **Memory usage acceptable** - No significant size increases

Run this checklist before releasing new firmware or merging significant changes.

---

## Test Documentation

When adding new keyboards or protocols, document your testing:

**What to document:**

- Which keyboard models were tested
- Any quirks or edge cases discovered
- Protocol timing characteristics observed
- Signal quality issues encountered
- Special configuration required

**Example test documentation:**

```markdown
# Testing Notes - IBM Model M Enhanced

**Hardware:** IBM Model M Enhanced (1391401), manufactured 1994
**Protocol:** AT/PS2, Scancode Set 2
**Connection:** 5-pin DIN → level shifter → RP2040 GPIO 2/3

**Testing performed:**

- Basic functionality: ✓ All keys work correctly
- Fast typing: ✓ No dropped keys at 30+ CPS
- LED indicators: ✓ Caps/Num/Scroll Lock all function
- Protocol timing: ✓ Clock ~11 kHz, stable

**Quirks discovered:**

- Sends garbage scancode 0xAA on power-up (handled by protocol init)
- Caps Lock LED slightly dimmer than Num Lock (cosmetic, works fine)

**Signal quality:**

- Clean 5V logic levels on CLK/DATA
- No noise or ringing observed
- Rise/fall times < 100ns
```

This documentation helps future contributors understand what's been tested and what to watch for.

---

## Performance Testing

Whilst the converter hasn't been extensively benchmarked with timing equipment, you can measure key performance characteristics:

### Latency Measurement

**Method 1: Logic analyser**

1. Connect logic analyser to keyboard CLK/DATA and USB D+/D-
2. Press a key and capture signals
3. Measure time from keyboard clock edge to USB D+ transition
4. Repeat 10-20 times to get average and variance

**Method 2: Software timing**

1. Enable DEBUG logging level
2. Add timestamps to key pipeline stages
3. Log time at: PIO IRQ, ring buffer read, HID report ready, USB transmission
4. Capture UART output and analyze timing

**Expected latency:**

- Protocol transmission: varies by protocol — determined by clock rate and frame length, not software-controlled (for clock rates and frame structure, see the [protocol docs](../protocols/); for example, [docs/protocols/at-ps2.md](../protocols/at-ps2.md) covers AT/PS2 clock frequency, frame length, and bit timing; exact values are hardware- and implementation-dependent and vary between keyboards)
- Processing pipeline: <100μs (PIO→IRQ→ring buffer→scancode→HID) — theoretical; based on pipeline step count, not measured
- USB polling wait: 0–8ms (`bInterval = 8` in `usb_descriptors.c`; average 4ms assuming uniform phase distribution)
- Total: these figures are theoretical estimates; actual end-to-end latency depends on USB polling phase (as of the time of writing, no precise measurements have been taken)

### Throughput Measurement

**Test maximum throughput:**

1. Write script to simulate rapid keypresses
2. Monitor UART for dropped scancodes or buffer overflow warnings
3. Measure maximum sustained keypress rate without errors

**Expected throughput:**

- Theoretical max: 125 reports/second (8ms USB polling)

### Resource Monitoring

**Monitor memory usage:**

1. Check build output for Flash/RAM consumption
2. Verify usage stays well below limits (230KB Flash, 150KB RAM)
3. Review .map file for large functions or data structures

**Monitor CPU usage:**

- No direct CPU monitoring in current implementation
- PIO handles protocol timing autonomously (zero CPU during bit reception)
- Main loop operates in non-blocking architecture
- USB polling dominates timing (8ms intervals)

---

## Debugging Techniques

### UART Logging Levels

The converter provides configurable logging levels (see [Logging guide](../features/logging.md)):

- **ERROR:** Critical failures only
- **WARN:** Protocol errors, unexpected conditions
- **INFO:** Initialisation messages, state changes
- **DEBUG:** Detailed scancode traces, timing information

**For testing:** Use DEBUG level to see everything. For production: INFO or WARN.

### Logic Analyser Protocol Decoding

Some logic analyser software includes protocol decoders:

1. **AT/PS2 decoder:** Shows scancodes, parity errors, timing violations
2. **UART decoder:** Displays UART output alongside protocol signals
3. **USB decoder:** Some analysers can decode USB HID reports

**Debugging workflow:**

1. Capture signals during problematic behaviour
2. Review protocol decoder output for errors
3. Cross-reference with UART logging
4. Identify timing violations or unexpected scancodes

### GDB Debugging

The .elf file includes debug symbols for GDB debugging:

```bash
# Start OpenOCD (connects to RP2040 via SWD)
openocd -f interface/cmsis-dap.cfg -f target/rp2040.cfg

# In another terminal, start GDB
arm-none-eabi-gdb build/rp2040-converter.elf
(gdb) target remote localhost:3333
(gdb) monitor reset halt
(gdb) break main
(gdb) continue
```

**Use GDB for:**

- Setting breakpoints in protocol handlers
- Inspecting ring buffer state
- Stepping through scancode processing
- Analyzing crash dumps

---

## Test Reports

When submitting bug reports or requesting support, include:

1. **Hardware details:**
   - Keyboard make/model
   - Protocol type (AT/PS2, XT, Amiga, M0110)
   - Converter board type (RP2040 variant)

2. **Software version:**
   - Git commit hash or release version
   - Build configuration (keyboard + mouse)
   - Enabled features

3. **Test results:**
   - Which tests passed/failed
   - UART log output (if available)
   - Logic analyser captures (if available)
   - Steps to reproduce issue

4. **Environment:**
   - Host operating system
   - USB hub/KVM switch (if used)
   - Power supply details

---

## Related Documentation

- [Architecture](architecture.md) - Understanding the system for effective testing
- [Performance](performance.md) - Expected performance characteristics
- [Build System](build-system.md) - Building test firmware
- [Code Standards](../development/code-standards.md) - Architecture rules and patterns
- [Logging](../features/logging.md) - Configuring debug output
- [Hardware Setup](../getting-started/hardware-setup.md) - Physical connections

---

**Questions about testing or found an issue?**
Use [GitHub Discussions](https://github.com/PaulW/rp2040-keyboard-converter/discussions) or [open an issue](https://github.com/PaulW/rp2040-keyboard-converter/issues) if you've found a problem.

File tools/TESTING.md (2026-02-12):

# Testing Enforcement Tools

This guide covers testing the enforcement mechanisms themselves—you'll need this when modifying lint.sh, git hooks, or CI checks. For regular development, just run `./tools/lint.sh` before committing (see [QUICKTEST.md](QUICKTEST.md)).

## Automated Test Suite

The meta-testing suite validates that enforcement tools detect violations correctly:

```bash
./tools/test-enforcement.sh
```

This runs through multiple scenarios checking that the lint script catches violations, git hooks block problematic commits, and CI checks function correctly. You'll only need this when modifying the enforcement tools—not for regular keyboard development or bug fixes.

All tests should pass, confirming the enforcement tools work as expected.

---

## Manual Testing Guide

### 1. Test Lint Script

#### Test 1.1: Clean Run
```bash
./tools/lint.sh
```

**Expected Result**:
- ✅ Passes with 0 errors, 0 warnings
- All intentional violations properly annotated with LINT:ALLOW comments

#### Test 1.2: Strict Mode
```bash
./tools/lint.sh --strict
```

**Expected Result**: Passes (codebase is clean with proper LINT:ALLOW annotations)

#### Test 1.3: Create Violation and Test
```bash
# Create a test file with blocking operation
cat > src/test_violation.c << 'EOF'
#include "pico/stdlib.h"
void bad_function(void) {
    sleep_ms(100);  // Violation!
}
EOF

# Run lint (should detect violation)
./tools/lint.sh

# Clean up
rm src/test_violation.c
```

**Expected Result**: Lint script detects `sleep_ms()` and reports error

---

### 2. Test Git Hooks

#### Test 2.1: Commit Message Hook (docs-internal reference)
```bash
# This should FAIL (hook blocks it)
git commit --allow-empty -m "Add feature (see docs-internal/notes.md)"
```

**Expected Result**: ❌ Commit blocked with error message

#### Test 2.2: Commit Message Hook (clean message)
```bash
# This should SUCCEED
git commit --allow-empty -m "Add test feature"

# Clean up (undo commit)
git reset --soft HEAD~1
```

**Expected Result**: ✅ Commit allowed

#### Test 2.3: Pre-commit Hook (docs-internal files)
```bash
# Create test file
mkdir -p docs-internal
echo "test" > docs-internal/test.md

# Try to force add (note: .gitignore prevents normal staging)
git add -f docs-internal/test.md

# Try to commit (should FAIL at pre-commit)
git commit -m "test commit"

# Clean up
git reset HEAD docs-internal/test.md
rm docs-internal/test.md
```

**Expected Result**: ❌ Pre-commit hook blocks the commit

#### Test 2.4: Bypass Hooks (--no-verify)
```bash
# This SUCCEEDS but is discouraged
git commit --allow-empty -m "Test bypass" --no-verify

# Clean up
git reset --soft HEAD~1
```

**Expected Result**: ✅ Commit succeeds (bypass works) - but you should NEVER do this except for testing

---

### 3. Test Commit Template

#### Test 3.1: View Template
```bash
# Check if template is configured
git config commit.template

# View template contents
cat .gitmessage
```

**Expected Result**: Shows `.gitmessage` with docs-internal reminder

#### Test 3.2: Use Template
```bash
# Create commit using template (editor will open)
git commit --allow-empty

# You should see the template with reminders
# Cancel with :q! (Vim) or Ctrl+C
```

**Expected Result**: Commit message editor shows template with checklist

---

### 4. Test CI Checks (Simulate Locally)

#### Test 4.1: Check for docs-internal Files in Repo
```bash
# This simulates the CI check
if git ls-files | grep -q "^docs-internal/"; then
    echo "ERROR: docs-internal/ files found in repository!"
    git ls-files | grep "^docs-internal/"
    exit 1
else
    echo "✓ No docs-internal/ files in repository"
fi
```

**Expected Result**: ✅ No files found

#### Test 4.2: Build Matrix (Docker Required)
```bash
# Test one configuration
docker compose run --rm -e KEYBOARD="modelm/enhanced" builder
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

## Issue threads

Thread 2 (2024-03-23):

No Visibility for Lock States on keyboards with no Lock Lights

PaulW, 2024-03-23:
When using a keyboard which has either no lock lights (ie, MicroSwitch 122ST13), or the protocol doesn't allow commands to be sent to the keyboard (XT Protocol), there is no visible state to identify what key locks are set.

When connecting to a Windows device, a HID report is sent to the keyboard to ensure the correct Lock Lights are set, and also with other devices (MacOS, Android, etc), Lock Light reports are sent when the state changes.

PaulW, 2024-03-23:
This condition does not apply to *all* XT keyboards, however.  The Cherry G80-1104H has integral Lock Lights, but these are controlled by the internal keyboard controller and not set via the Host.

However, there may be a time where these become out of sync, and as such the true state is not represented (in the case of being connected to a Macbook, the Caps state only changes internally when held for more than 100ms, however, the Cherry keyboard can change it's own LED state outside of this window, so can give a false-positive).

PaulW, 2024-03-23:
Ideally, we would like to have visibility on the following states:

Converter State (connection, etc)*
Caps Lock
Num Lock
Scroll Lock

*Converter State
This should give visibility (via colour representation) to the state of the converter at the time.  For example:
Green: All OK
Yellow: Initialising/Connecting to Keyboard
Red: Error (communication error, invalid data, reboot condition)
Purple: Bootloader Mode (when initialised via the Keyboard Macro)

Again, these are just ideas.

To do this, we can utilise the [WS2812](https://cdn-shop.adafruit.com/datasheets/WS2812.pdf) LED, as this will allow us to control multiple LED's from a single GPIO.  These are 5v LEDs, so can be driven directly via VSYS (5v), and use a BSS138 N-Channel Logic Shifter to handle the data line voltage (as used for the current Clock/Data Lines).

As the LEDs are also individually addressable, there is no need to handle PWM states, so controlling brightness and colour is manages using a 32bit integer for each LED.

PaulW, 2024-04-14:
https://github.com/PaulW/rp2040-keyboard-converter/commit/aa6344710f44c8c346adc1ccaf8e558b59bcefcd

This commit adds LED Support.

PaulW, 2024-04-14:
https://github.com/PaulW/rp2040-keyboard-converter/pull/4

Closed 2024-04-14.

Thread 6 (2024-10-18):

build fails with cannot open output file /usr/local/builder/build/rp2040-converter.elf: Permission denied

lindoran, 2024-10-18:
when following the directions to build I get the following:

[100%] Linking CXX executable /usr/local/builder/build/rp2040-converter.elf
/usr/lib/gcc/arm-none-eabi/12.2.1/../../../arm-none-eabi/bin/ld: cannot open output file /usr/local/builder/build/rp2040-converter.elf: Permission denied
collect2: error: ld returned 1 exit status
gmake[2]: *** [CMakeFiles/rp2040-converter.dir/build.make:1544: /usr/local/builder/build/rp2040-converter.elf] Error 1
gmake[1]: *** [CMakeFiles/Makefile2:1749: CMakeFiles/rp2040-converter.dir/all] Error 2
gmake: *** [Makefile:91: all] Error 2

I have a freshly installed Kubuntu install and Docker.  I can't seem to figure out what the issue is.

I absolutely love the project -- Id like to contribute my keyboard to it but  it won't work to compile.

Any help would be appreciated

dave

PaulW, 2024-10-21:
Seen this a couple of times, sometimes it's due to the `build1 folder not being able to be written to from the container.  Can you check the permissions on that folder please? Usually a simple case of running `chmod 0777 build` from the folder you checked the source out into.

lindoran, 2024-10-21:
This worked!  -- that's interesting -- I wonder if that's an issue with docker or the docker configuration files... either way might be a good idea to put that work around in the build instructions for the time being?

Thanks for the help!

 I have a "Comp Key" keyboard mech with an AT/XT switch -- the AT signaling is not quite AT and the XT signaling is bog standard.  SO I figured I would use this project to make a profile to use the keyboard.

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

PaulW, 2024-10-22:
Oh that looks interesting! I'd be curious to know what the AT signal is doing though, I wonder if perhaps it's behaving like a Z-150 where it pulls the stop bit LOW when sending but also doesn't pull clock LOW when sending the ACK response after being sent a command.  I've unfortunately not been able to get my hands on one of these as of yet to work it out.

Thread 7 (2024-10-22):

AT Protocol issue with Comp Key keyboard.

PaulW, 2024-10-22:
This worked!  -- that's interesting -- I wonder if that's an issue with docker or the docker configuration files... either way might be a good idea to put that work around in the build instructions for the time being?

Thanks for the help!

 I have a "Comp Key" keyboard mech with an AT/XT switch -- the AT signaling is not quite AT and the XT signaling is bog standard.  SO I figured I would use this project to make a profile to use the keyboard.

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

_Originally posted by @lindoran in https://github.com/PaulW/rp2040-keyboard-converter/issues/6#issuecomment-2426335357_

PaulW, 2024-10-22:
@lindoran could you please check against the following branch?

https://github.com/PaulW/rp2040-keyboard-converter/tree/stop_bit_test

I've removed the validation check for now against the Stop bit, as this is the only thing I can initially identify which may be causing the issue if it is indeed following the method used by the Z-150 where the Stop Bit is LOW and not HIGH when receiving data from the keyboard.

Also, if you have a USB to TTL Serial adaptor (or another way to interface), please can you connect to GPIO pins 0 and 1 (TX and RX) on your WaveShare RP2040-Zero, as this will allow you to read the output to try and understand where the AT protocol may be failing.

lindoran, 2024-10-22:
I might not get a chance to check for a bit of time depending on how much
time I get at the bench this week.  I am currently splitting my efforts
between launching an open hardware project and playing around with the
keyboard. I'll definitely have some time over the weekend. I have an
oscilloscope and a logic analyzer so we can probably check out signals that
way too the biggest issue Is I don't actually have the native computer
motherboard that goes with it, and probably will never have it. What I
bought was just the case, keyboard mech and floppy drive.  The motherboard
and graphics card all fit inside the keyboard, kind of like an Amega 500
but a 386. Generally speaking it does seem to be initialized like an AT
keyboard so it should work,  it just doesn't -- that being said I haven't
tried with an actual AT motherboard -- so I'm not 100% if it should work
that way either... I couldn't get it to work with PS/2 either..  The stop
bit issue is a good place to start as any.

On Tue, Oct 22, 2024, 8:02 AM Paul Bramhall ***@***.***>
wrote:

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

PaulW, 2024-10-22:
No worries, honestly just raising the issue is enough to get me putting a bit of thought into it! I can only test as much as I can with what I have currently, so it's good to know when something isn't quite right with something else!  I did do some reading on what your board was for as good as I can and it looks like a really interesting piece of kit!

lindoran, 2024-10-25:
Paul,

So I got a chance to look at this - I just dropped the test build for the model F onto the dev board and flipped it into AT mode -- just to make sure I was getting the same results I was getting with my PS2 cable and interface... wouldn't you know now it works (mostly -- the key map is wrong so some keys don't work.) but where the keys line up its fine.  So now I am assuming its something with the initial initialization (or) some other discrete  incompatibility when plugged with an adapter into a PS/2 port. As a matter of fact,  I am typing this with the key mech and it is quite responsive.  So that being said, it appears the issue is when plugged into a PS/2 port it doesn't work, but plugged into the rp2040 keyboard converter its fine.  I did go back and try the mech on a much older ps/2 port on my PS/1 2155 and the keyboard is less responsive there.  It might also be power availability some other issue like that.  The internal header only has 4 pins hooked up and the reset pin on the keyboards MCU is tied to an RC network so it just resets 1x with power on and the bi-directional reset command is what resets it.. I had a look at the actual output stage of the keyboard and it has a open collector buffer inverter (like usual) and pull up resistors to VCC.    values for the pull ups look quite low  - 2K.  That's not super unusual but would draw a lot more current than say a 4.7k pull up if the line were pulled low and the edge rate would be super fast.  I suppose it COULD be just a simple  case of not enough power at the +5v pin in the thin client and the PS/1.  but the mech itself only draws like 80mA according to my bench top power supply...   So its kind of a good news bad news thing.  Good news is it works.  But I don't think its the stop bit in this case because it just responds to the interface exactly like a Model F would.

PaulW, 2024-10-30:
Ok thanks for testing that!  So with you using the Model F keyboard as a base for the build, this will still perform and operate the same as if you used the Model M Enhanced config, as they both utilise the AT protocol.  The only difference between the two does come down to the layout itself, the protocol will still issue all the same init and bi-directional commands.

Without the change to the stop bit check in the `keyboard_input_event_handler()` function, this would always cause any key response (and in effect any command) to fail when anything is received from the keyboard, so it wouldn't even get to the point of it initialising properly as would forever reach timeouts & keep issuing 0xFF to reset the keyboard.

With what you say about the PS/2 adaptor failing, it may be that the controller which is interfacing with the keyboard is strict with the stop bit validation also, so again would just get into a bit of a state with communicating with it.

Power wise, PS/2 was specced to deliver 5v at upto 275mA, but if you've measured it as only drawing 80mA then unless your PS/1 is struggling to deliver that I'm not sure what may be causing the response issues there.  Without understanding the signal generated from the keyboard though it's difficult to pinpoint.

I'll merge in the branch changes though to master, as like you said it did work with that change applied which is good to know, but does raise more questions as to why it's having issues elsewhere!

As for the layout, have a try with using the Model M Enhanced config (this will map more of the keycodes which the F/AT doesn't have), or feel free to have a go at creating a layout for it!

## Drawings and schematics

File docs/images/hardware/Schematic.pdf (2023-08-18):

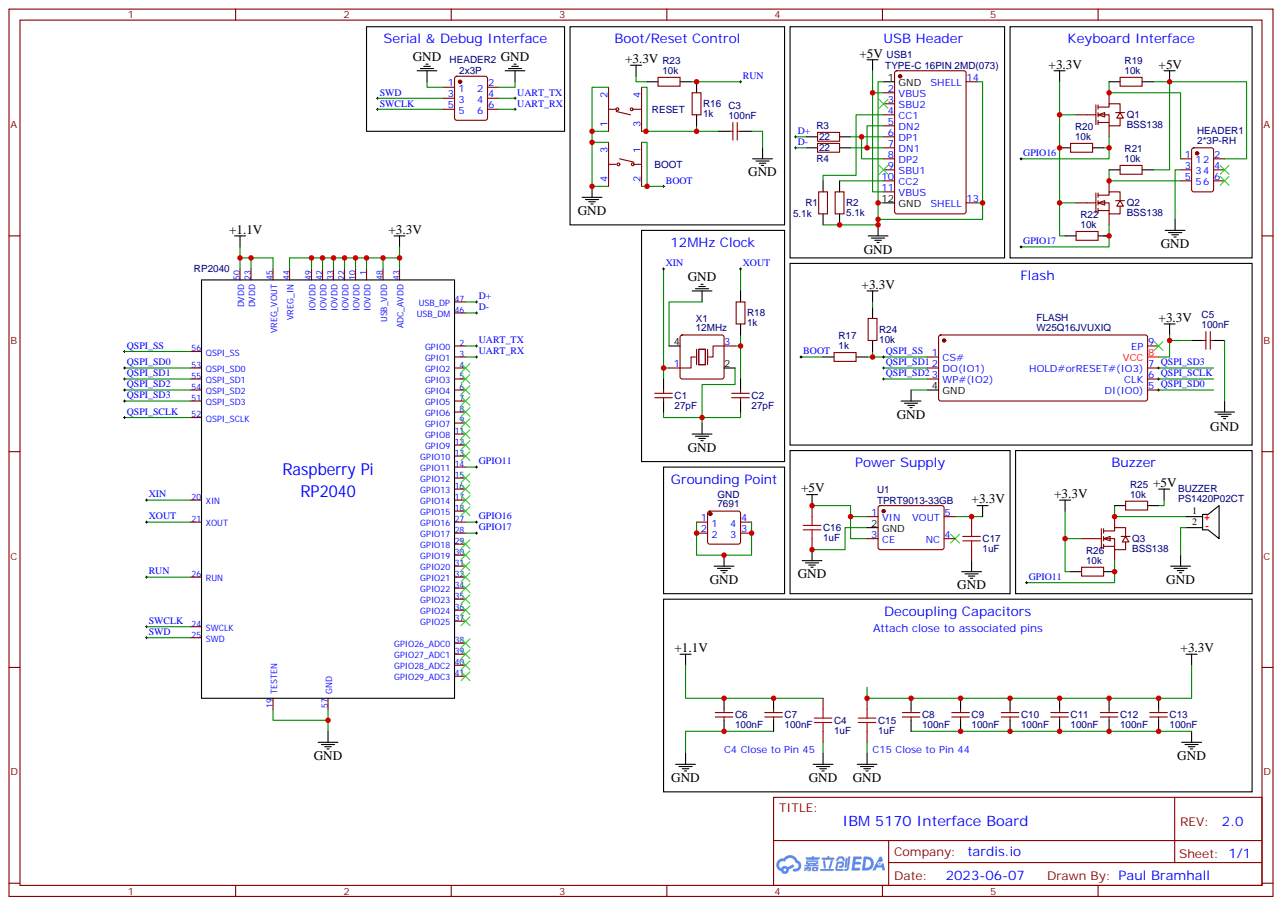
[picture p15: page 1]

Decoupling Capacitors
Attach close to associated pins

Drawn By: Paul Bramhall

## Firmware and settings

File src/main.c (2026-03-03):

/*
 * This file is part of RP2040 Keyboard Converter.
 *
 * Copyright 2023-2026 Paul Bramhall (paulwamp@gmail.com)
 *
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
 * You should have received a copy of the GNU General Public License
 * along with RP2040 Keyboard Converter.
 * If not, see <https://www.gnu.org/licenses/>.
 */

/**
 * @file main.c
 * @brief Firmware entry point, subsystem initialisation, and cooperative main loop.
 *
 * Initialises all subsystems in order then runs a cooperative task loop. No RTOS is
 * used; tasks are short non-blocking functions called in sequence. All timing-critical
 * work happens in PIO IRQ handlers which write to ring buffers; the main loop drains
 * those buffers and dispatches through the HID pipeline.
 *
 * Initialisation Sequence:
 *  1. hid_device_setup()         — TinyUSB stack and USB device controller
 *  2. init_uart_dma()            — DMA-backed UART logging
 *  3. flow_tracker_init()        — pipeline latency instrumentation (no-op if disabled)
 *  4. command_mode_init()        — command mode state machine
 *  5. config_init()              — load persistent settings from flash
 *  6. log_set_level()            — apply saved log verbosity
 *  7. keylayers_init()           — layer system and restore saved layer state
 *  8. ws2812_setup()             — WS2812 LED PIO (if CONVERTER_LEDS defined)
 *  9. keyboard_interface_setup() — keyboard protocol PIO and IRQ (if KEYBOARD_ENABLED)
 * 10. mouse_interface_setup()    — mouse protocol PIO and IRQ (if MOUSE_ENABLED)
 *
 * Main Loop Tasks (cooperative, non-preemptive):
 * - keyboard_interface_task() — drains keyboard ring buffer, calls process_scancode()
 * - mouse_interface_task()    — drains mouse ring buffer, generates mouse HID reports
 * - command_mode_task()       — manages command mode timeout and LED state updates
 * - tud_task()                — TinyUSB device task (USB event processing)
 *
 */

#if !PICO_NO_FLASH && !PICO_COPY_TO_RAM
#error "This must be built to run from SRAM!"
#endif

#include <stdint.h>

#include "pico/unique_id.h"

#include "bsp/board.h"
#include "tusb.h"

#include "command_mode.h"
#include "config.h"
#include "config_storage.h"
#include "flow_tracker.h"
#include "hid_interface.h"
#include "keylayers.h"
#include "log.h"
#include "uart.h"

#if KEYBOARD_ENABLED
#include "keyboard.h"
#include "keyboard_interface.h"
#endif

#if MOUSE_ENABLED
#include "mouse_interface.h"
#endif

#ifdef CONVERTER_LEDS
#include "ws2812/ws2812.h"
#endif

// --- Public Functions ---

/**
 * @brief Firmware entry point.
 *
 * Initialises all subsystems in order then runs the cooperative main loop.
 * See the \@file documentation for the complete initialisation sequence and
 * main loop task descriptions.
 *
 * @return int Never returns in normal operation; returns 0 if the main loop exits.
 * @note Main loop only.
 */
int main(void) {
    hid_device_setup();
    init_uart_dma();
    flow_tracker_init();  // Initialise flow tracker (no-op when FLOW_TRACKING_ENABLED=0)
    command_mode_init();  // Initialise command mode system

    // Load persistent configuration from flash
    if (!config_init()) {
        LOG_WARN("Using factory default configuration\n");
    }

    // Apply saved log level
    log_set_level(config_get()->log_level);

    // Initialise layer system and restore saved layer state
    keylayers_init();

    char pico_unique_id[32];
    pico_get_unique_board_id_string(pico_unique_id, sizeof(pico_unique_id));
    LOG_INFO("--------------------------------\n");
    LOG_INFO("RP2040 Device Converter\n");
    LOG_INFO("RP2040 Serial ID: %s\n", pico_unique_id);
    LOG_INFO("Build Time: %s\n", BUILD_TIME);
    LOG_INFO("--------------------------------\n");

#ifdef CONVERTER_LEDS
    ws2812_setup(LED_PIN);  // Setup the WS2812 LEDs.

    // Apply saved LED brightness from configuration
    uint8_t saved_brightness = config_get_led_brightness();
    ws2812_set_brightness(saved_brightness);
    LOG_INFO("LED brightness set to %u (0-10 range)\n", saved_brightness);
#endif

    // Initialise aspects of the Interface.
#if KEYBOARD_ENABLED
    LOG_INFO("Keyboard Support Enabled\n");
    LOG_INFO("Keyboard Make: %s\n", KEYBOARD_MAKE);
    LOG_INFO("Keyboard Model: %s\n", KEYBOARD_MODEL);
    LOG_INFO("Keyboard Description: %s\n", KEYBOARD_DESCRIPTION);
    LOG_INFO("Keyboard Protocol: %s\n", KEYBOARD_PROTOCOL);
    LOG_INFO("Keyboard Scancode Set: %s\n", KEYBOARD_CODESET);
    LOG_INFO("--------------------------------\n");
    keyboard_interface_setup(KEYBOARD_DATA_PIN);  // Setup the keyboard interface.
#else
    LOG_INFO("Keyboard Support Disabled\n");
#endif

#if MOUSE_ENABLED
    LOG_INFO("Mouse Support Enabled\n");
    LOG_INFO("Mouse Protocol: %s\n", MOUSE_PROTOCOL);
    LOG_INFO("--------------------------------\n");
    mouse_interface_setup(MOUSE_DATA_PIN);  // Setup the mouse interface.
#else
    LOG_INFO("Mouse Support Disabled\n");
#endif

    // Main loop: run interface tasks and USB stack continuously.
    while (1) {
#if KEYBOARD_ENABLED
        keyboard_interface_task();  // Keyboard interface task.
#endif
#if MOUSE_ENABLED
        mouse_interface_task();  // Mouse interface task.
#endif
        command_mode_task();  // Command mode LED updates and timeout handling
        tud_task();           // TinyUSB device task.
    }

    return 0;
}

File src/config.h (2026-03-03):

/*
 * This file is part of RP2040 Keyboard Converter.
 *
 * Copyright 2023-2026 Paul Bramhall (paulwamp@gmail.com)
 *
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
 * You should have received a copy of the GNU General Public License
 * along with RP2040 Keyboard Converter.
 * If not, see <https://www.gnu.org/licenses/>.
 */

/**
 * @file config.h
 * @brief Top-level compile-time configuration: hardware pins, feature flags, and build parameters.
 *
 * Central location for all user-configurable compile-time settings. Values are set here
 * with sensible defaults; the CMake build system passes keyboard/mouse-specific values as
 * `_<VAR>` prefixed defines which are then exposed without the prefix.
 *
 * Configuration Sections:
 * - UART Hardware:      GPIO pin and baud rate for debug serial output
 * - UART DMA:           Buffer size, queue depth, queue-full policy (DROP/WAIT_FIXED/WAIT_EXP)
 * - Log Levels:         Runtime log verbosity constants (ERROR/INFO/DEBUG) and startup default
 * - LED:                WS2812 enable, LED type, brightness (1–10), and per-state colours
 * - GPIO Pins:          KEYBOARD_DATA_PIN, MOUSE_DATA_PIN, LED_PIN starting addresses
 * - Caps Lock Toggle:   Hold time for make-before-break CapsLock toggling (macOS compatibility)
 * - Debug Features:     FLOW_TRACKING_ENABLED for pipeline latency instrumentation
 * - CMake Build Vars:   KEYBOARD_ENABLED, KEYBOARD_MAKE, KEYBOARD_MODEL, KEYBOARD_PROTOCOL,
 *                       KEYBOARD_CODESET, MOUSE_ENABLED, MOUSE_PROTOCOL
 *
 * At least one of KEYBOARD_ENABLED or MOUSE_ENABLED must be set; a compile-time error
 * is raised otherwise. clang-format is disabled for this file to preserve comment alignment.
 */

#ifndef CONFIG_H
#define CONFIG_H

// Turn off clang-format for this file as we want to keep the formatting as is
// clang-format off

// --- UART Hardware Configuration ---
#define UART_TX_PIN 0       // GPIO pin for UART transmission (typically GP0)
#define UART_BAUD   115200  // UART transmission baud rate

// --- UART DMA Buffer Configuration ---
// Controls memory allocation for the DMA-based UART logging system.
//
// UART_DMA_BUFFER_SIZE: Maximum length of a single log message (bytes)
//   - Typical: 256 bytes (sufficient for most log messages)
//   - Memory impact: BUFFER_SIZE × QUEUE_SIZE total RAM usage
//   - Messages longer than this will be truncated
//
// UART_DMA_QUEUE_SIZE: Number of messages that can be queued
//   - Must be a power of 2 (enforced by compile-time check)
//   - Typical: 64 entries (handles initialisation bursts)
//   - Memory usage: 256 × 64 = 16KB (current configuration)
//   - Larger queue = more burst tolerance but more RAM usage
//
#define UART_DMA_BUFFER_SIZE 256  // Size of each message buffer in bytes (max message length)
#define UART_DMA_QUEUE_SIZE  64   // Number of queued messages (must be power of 2)

// --- UART DMA Debug Statistics ---
// Uncomment to enable drop statistics tracking and reporting.
// When enabled, the system tracks and reports when messages are dropped due to queue full.
// Statistics are reported automatically when drops occur (event-triggered, non-interactive).
//
// Memory overhead: ~12 bytes (counters)
// CPU overhead: One atomic increment per drop + occasional printf
//
// #define UART_DMA_DEBUG_STATS

// --- UART DMA Queue Policy Configuration ---
// Controls behaviour when the message queue becomes full during logging bursts.
// The policy is selected at compile time for zero runtime overhead.

#define UART_DMA_WAIT_US 5000  // Maximum wait time in microseconds (applies to WAIT policies)

// UART DMA Policy Constants - do not modify these values
#define UART_DMA_POLICY_DROP        0  // Immediately drop messages if queue is full
#define UART_DMA_POLICY_WAIT_FIXED  1  // Wait up to UART_DMA_WAIT_US with tight polling
#define UART_DMA_POLICY_WAIT_EXP    2  // Exponential backoff delays (CPU-friendly)

// Define the UART DMA Policy - choose ONE of the following:
//
// UART_DMA_POLICY_DROP:       Immediately drop messages if queue is full
//                              * Real-time safe (never blocks)
//                              * Recommended for keyboard converter application
//                              * May lose messages under extreme load
//
// UART_DMA_POLICY_WAIT_FIXED: Wait up to UART_DMA_WAIT_US with tight polling
//                              * Better message preservation
//                              * CPU intensive during waits
//                              * May cause timing issues in real-time code
//
// UART_DMA_POLICY_WAIT_EXP:    Exponential backoff delays (1μs, 2μs, 4μs, ...)
//                              * CPU-friendly waiting with progressive delays
//                              * Good balance of message preservation and performance
//                              * Delays capped at 1024μs per step
//
#define UART_DMA_POLICY UART_DMA_POLICY_DROP
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

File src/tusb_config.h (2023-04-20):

/*
 * The MIT License (MIT)
 *
 * Copyright (c) 2019 Ha Thach (tinyusb.org)
 *
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
 */

#ifndef _TUSB_CONFIG_H_
#define _TUSB_CONFIG_H_

#ifdef __cplusplus
extern "C" {
#endif

//--------------------------------------------------------------------
// COMMON CONFIGURATION
//--------------------------------------------------------------------

// defined by board.mk
#ifndef CFG_TUSB_MCU
#error CFG_TUSB_MCU must be defined
#endif

// RHPort number used for device can be defined by board.mk, default to port 0
#ifndef BOARD_DEVICE_RHPORT_NUM
#define BOARD_DEVICE_RHPORT_NUM 0
#endif

// RHPort max operational speed can defined by board.mk
// Default to Highspeed for MCU with internal HighSpeed PHY (can be port
// specific), otherwise FullSpeed
#define BOARD_DEVICE_RHPORT_SPEED OPT_MODE_FULL_SPEED

// Device mode with rhport and speed defined by board.mk
#if BOARD_DEVICE_RHPORT_NUM == 0
#define CFG_TUSB_RHPORT0_MODE (OPT_MODE_DEVICE | BOARD_DEVICE_RHPORT_SPEED)
#elif BOARD_DEVICE_RHPORT_NUM == 1
#define CFG_TUSB_RHPORT1_MODE (OPT_MODE_DEVICE | BOARD_DEVICE_RHPORT_SPEED)
#else
#error "Incorrect RHPort configuration"
#endif

#ifndef CFG_TUSB_OS
#define CFG_TUSB_OS OPT_OS_NONE
#endif

// CFG_TUSB_DEBUG is defined by compiler in DEBUG build
// #define CFG_TUSB_DEBUG 2

/* USB DMA on some MCUs can only access a specific SRAM region with restriction
 * on alignment. Tinyusb use follows macros to declare transferring memory so
 * that they can be put into those specific section. e.g
 * - CFG_TUSB_MEM SECTION : __attribute__ (( section(".usb_ram") ))
 * - CFG_TUSB_MEM_ALIGN   : __attribute__ ((aligned(4)))
 */
#ifndef CFG_TUSB_MEM_SECTION
#define CFG_TUSB_MEM_SECTION
#endif

#ifndef CFG_TUSB_MEM_ALIGN
#define CFG_TUSB_MEM_ALIGN __attribute__((aligned(4)))
#endif

//------------- CLASS -------------//
#define CFG_TUD_HID 2
#define CFG_TUD_CDC 0
#define CFG_TUD_MSC 0
#define CFG_TUD_MIDI 0
#define CFG_TUD_VENDOR 0

// Define both Keyboard and Consumer interface buffer sizes.
#define KEYBOARD_EP_BUFSIZE 8
#define CONSUMER_EP_BUFSIZE 16

#ifdef __cplusplus
}
#endif

#endif /* _TUSB_CONFIG_H_ */

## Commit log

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2023-06-07 Update build files & tweak source file locations
    Move defined Keymaps for keyboard into keymaps/xxx folder.
    Add build options to CMakeLists.txt to allow (if required) ability to specify which keymap to build with (Currently limited to 6450225 Layout)
    Rename keymap.[c|h] files to avoid confusion.
    Change macro name for keyboard maps from KEYMAP to KEYMAP_5170
2023-08-18 Add Buzzer Support
    This adds basic support for notification sounds to be issued via a
    Piezo buzzer. For reference, we are testing with a TDK-PS1240P02BT
    [buzzer.c, main.c]
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2024-01-13 Performance updates
    Change how we send commands to the keyboard controller from `pm_sm_put_blocking` to `pm_sm_put`, and reduce debugging output during LED toggling.
    This is to try and reduce the likelyhood of the keyboard locking up when spamming any of the Lock keys. Unfortunately it doesn't completely resolve the issue, but does seem to reduce the chance of it happening.
    To be honest though, who spams a Lock key on a keyboard? Behave!
2024-01-13 Update Keyboard Init Process
    There has always been an issue where upon power up, the process of initialisation would always
    result in an initial invalid read from the keyboard (resulting in getting 0x54 with invalid
    parity bit) instead of 0xAA which signifies the keyboard has passed BAT. Originally we would
    mitigate against this by passing 0xAA to the event processor function after a 100ms delay, so
    tricking the initialisation process to begin. This would then cause the converter to send
    multiple 0xFF reset commands to the keyboard on power up.
    Although this worked, it was messy.
    As part of the Keyboards initialisation process, it will pull the CLOCK line low, and only bring
    it high once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
    [main.c]
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2024-01-26 Multiple updates
    Quite a few chunks have been changes as part of this commit, but a quick summary of what has been done:
    - Rework how we determine the Clock Multiplier for the State Machine. This now allows paramater-based
    adjustment by setting the desired clock speed in kHz.
    - Fix issue with sending data to AT/PS2 Keyboard. IBM Model F and '88 Model M seems to be quite
    forgiving in when it receives commands from the host, however when testing with other PS2 keyboards,
    the correct flow & checking methods were quite critical to ensure the SM didn't lock up.
    - Add new keyboard layout for IBM Model M (1390131) as I now have this keyboard to develop and test
    with.
    - Update PCAT flow to allow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
    [config.h, main.c]
2024-02-11 Start of Multi-Keyboard and Protocol Support
    This commit is the start of future enhancements to allow multiple Keyboard and Protocol support.
    Previously, source files would need to be modified to allow the use of the extra Model M Keyboard, so this has now been changed to allow selection at build time, and no longer require updating of source files to change/select different keyboards.
    A quick overview of changes:
    - Better support for Multiple Keyboards (as added)
    - Add support for Compile-time Protocol selection (based on `keyboard.config` for the relevant Keyboard we are building for)
    - Add more output to the start of the program to indicate build time & compile time options relating to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
    [config.h, interface.c, keyboard_converter_board.h]
2024-02-16 Set binary type to copy_to_ram
    Previously, all convert code would be running from FLASH, which although likely performant enough, could potentially cause slowdowns or latency. This change now set the following build-time option
    `pico_set_binary_type(${PROJECT_NAME} copy_to_ram)`
    This ensures that before the code is executed, the contents of it is copied to RAM.
    We also use this option instead of `no_flash`, as the latter would cause the program to no longer be persistent between power cycles, but also prevent us from reading the unique Flash ID which is how we set the devices serial number.
    [interface.c, main.c]
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2024-04-14 Add LED Support
    This adds support for displaying the Status of the converter, as well as Lock Lights to display state of CapsLock, NumLock and ScrollLock, using a strip of WS2812 (NeoPixel) LEDs.
    Different types of LED are also supported. For development, I've used 4 x WS2812 NeoPixel LED's from Adafruit. You can use any other type of WS2812-compatible NeoPixel, but please ensure you set the correct LED Type. As part of this commit, only the following types are supported:
    RGB (Red Green Blue)
    RBG (Red Blue Green)
    GRB (Green Red Blue)
    GBR (Green Blue Red)
    BRG (Blue Red Green)
    BGR (Blue Green Red)
    Please refer to common/lib/types.h for available options, this can be set within config.h b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
    [config.h, interface.c, main.c]
2024-04-14 Fix PIO Assignment for AT/PS2 Keyboards following LED Code.
    When sending commands to the Keyboard, we hard-set pio1 as the receiver, however, with the new dynamic PIO assignment code, this changed.
    This didn't come to light until testing the MicroSwitch 122ST13 keyboard, as using the Model M and Model F boards, these default to the correct typematic settings, so didn't directly show this issue.
    [interface.c]
2024-04-20 Update Status LED to signal issues.
    The Status LED would not update if a keyboard is disconnected and then reconnected, or if the attached keyboard later has transmission issues and causes a controller reset. This ensures we always correctly update the Status LED in these events.
    [interface.c]
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2024-06-13 Refactor lock LED handling.
    * **Move lock state logic to protocol:** This commit removes the definition of `ps2_lock_values` from the LED helper. Lock state calculations and comparisons are now handled directly within the keyboard protocol itself.
    * **Reduce complexity for future interfaces:** By centralizing lock state logic, we avoid defining per-protocol lock LED masks in the LED helper. This prevents unnecessary bitwise operations and streamlines future support for additional interfaces.
2024-06-22 Allow in-built mice to be overriden
    Some keyboards which may have an inbuilt mouse, previously we would simply force this to be used and not allow the mouse to be overriden.
    This allows users to still specify the `MOUSE` flag during compilation, and this will in effect override the one which may be specified within the keyboard configuration.
    It may be the inbuit one is either not functional or broke, or it may be that it is preferred to use one external to the keyboard as-is.
    [main.c]
2024-09-11 Fix build warnings for pico-sdk 2.0.0
    pico-sdk 2.0.0 now requiretd picotool to be built prior to compilation of any code, so we now build this as part of the docker build.
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2025-10-07 Add Command Mode for 2KRO-Compatible Bootloader Entry (#13)
    * feat: Add Command Mode for 2KRO-compatible bootloader entry
    Replaces the 3-key simultaneous macro (Fn+Shifts+B) with a time-based
    Command Mode that works on 2-key rollover (2KRO) keyboards.
    Entry Method:
    - Hold ONLY both shifts (Left + Right) for 3 seconds
    - Status LED flashes Green/Blue at 100ms intervals
    - Press 'B' to enter bootloader, or wait 3s to timeout
    - Strict entry: pressing any other key during shift hold aborts
    Features:
    - State machine: IDLE → SHIFT_HOLD_WAIT → COMMAND_ACTIVE
    - LED feedback: Green/Blue alternating (100ms intervals)
    - HID behavior: Normal reports during wait, suppressed during command
    - Empty re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
    [main.c]
2025-10-07 Add gamma-corrected brightness control to WS2812 LED driver
    - Implement perceptually linear brightness scaling using gamma correction (γ = 2.5)
    - Add static const BRIGHTNESS_LUT[11] lookup table for O(1) brightness conversion
    - Apply brightness multiplier with explicit uint8_t casts for optimal performance
    - Add comprehensive docstrings explaining gamma correction theory and implementation
    - Maintain ~300ns per LED performance (3% of main loop time)
    - Preserve compile-time brightness range validation (1-10)
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2025-10-08 Feature/command mode enhancements (#14)
    * feat(logging): Add runtime log level filtering system
    Introduces runtime-configurable log level control to replace compile-time
    filtering. This allows field debugging without firmware reflashing.
    - Three log levels: ERROR, INFO, DEBUG
    - Runtime control via log_set_level()/log_get_level()
    - New macros: LOG_ERROR(), LOG_INFO(), LOG_DEBUG()
    - Minimal overhead: 5-10 cycles when level disabled
    - Zero binary bloat: 84KB stable
    Implementation details:
    - log.c: Runtime filtering logic with atomic access
    - log.h: Public API and convenience macros
    - config.h: Added LOG_LEVEL_* constants
    - uart.c: Initialize log system during UART setup
    Performanc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
    [config.h, main.c]
2025-10-09 feat: Add persistent configuration storage system (#15)
    * feat: Add persistent configuration storage system
    Implements persistent configuration storage using RP2040 flash memory
    (PR #14 future enhancement). Configuration survives reboots and firmware
    updates.
    - Flash-based storage (last 4KB sector, dual-copy redundancy)
    - Persistent log level (Command Mode 'D' key)
    - Factory reset command (Command Mode 'F' key with auto-reboot)
    - RAM-resident for performance (0-cycle reads, 25ms writes)
    - Automatic version migration (forward/backward compatible)
    - Extensible TLV storage (2KB for future macros/remapping)
    - CRC-16/CCITT validation and wear leveling
    Architecture:
    - Storage: 0x101FF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
    [main.c]
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2025-10-11 feat: Implement Commodore Amiga keyboard protocol with smart CAPS LOCK synchronization (#17)
    * feat(amiga): Add Commodore Amiga keyboard protocol support
    Implements complete Commodore Amiga keyboard protocol with PIO-based
    timing and hardware handshake. This protocol is bidirectional and
    synchronous, featuring:
    - **PIO Handshake**: 85µs KCLK pulse implemented in hardware using
    192-iteration loop with nop delays (no blocking operations)
    - **Bit Rotation**: Handles Amiga's unique bit order (6-5-4-3-2-1-0-7)
    - **Simple State Machine**: 2 states (UNINITIALISED → INITIALISED)
    following XT protocol pattern
    - **Special Codes**: Reset warning (0x78), lost sync (0xF9/0xFA),
    and initializat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
    [config.h]
2025-10-12 fix(amiga): Correct handshake timing from 19ms to 100µs
    Simplified PIO handshake loop to achieve proper 85µs minimum timing
    as required by the Amiga Hardware Reference Manual specification.
    Previous Implementation:
    - Nested loop: 25 × 31 × 5 cycles = 3,875 cycles
    - Timing: 3,875 × 4µs = 15.5ms (measured ~19ms with overhead)
    - Issue: 182× longer than required, designed for wrong divider
    Current Implementation:
    - Simple loop: 25 cycles × 4µs = 100µs (measured ~110µs)
    - Protocol compliance: 100µs > 85µs minimum requirement ✓
    - Safety margin: +15µs above minimum (29% buffer)
    - Performance: 172× faster handshake response
    Timing Validation:
    - Hardware tested: Oscilloscope confi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
2025-10-12 fix(protocols): Correct protocol handshake timing implementations
    This commit addresses timing corrections for two keyboard protocols:
    **Amiga Protocol (keyboard_interface.pio):**
    - Fixed handshake pulse timing from 19ms to 110µs (measured)
    - Simplified nested loop structure to straightforward 25-cycle loop
    - Clock divider 500 → 4µs/cycle, 25 cycles = 100µs calculated
    - Exceeds 85µs minimum requirement per Amiga Hardware Reference Manual
    - Added comprehensive timing documentation with validation notes
    - Hardware tested and confirmed compliant with A500/A2000/A3000/A4000
    **AT/PS2 Protocol (interface.pio):**
    - Corrected host-to-device Inhibit phase to explicitly control CLK
    - Original: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
2025-10-13 build: Add automatic build analysis and validation to Docker builds
    - Add comprehensive build analysis after successful builds
    - Include memory usage breakdown and resource percentages
    - Add automatic health checks with warnings at 75%/90% Flash and 70%/85% RAM
    - Display build configuration summary
    - Use ARM toolchain from Docker container (no local install needed)
    - 100% backward compatible - no workflow changes required
    Benefits:
    - Consistent analysis across all development platforms
    - Immediate feedback on resource usage
    - Early warning of capacity issues
    - Better visibility into build artifacts
2025-10-19 Fix issue #19: Prevent duplicate keys in HID report (#20)
    * Fix issue #19: Prevent duplicate keys in HID report
    Implemented fix for duplicate key bug where a key could appear twice
    in the HID report array when multiple keys are pressed/released in
    rapid succession (e.g., gaming, fast typing).
    Root cause: Original implementation would add a key to an early empty
    slot before checking all remaining slots for duplicates.
    Solution: Single-loop approach that scans all 6 slots to check for
    duplicates while tracking the first empty slot, then adds only if
    the key is not already present.
    Implementation optimizations for RP2040/ARM Cortex-M0+:
    - Use uint8_t types for loop counter and slot tracking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
2025-10-21 Fix Pause Key Support on AT/PS2 Keyboards (Issue #21) (#22)
    * debug: Add scancode logging for Issue #21 Pause key investigation
    Add timestamped debug logging to track raw scancodes and HID translations:
    - Log all received scancodes at protocol layer (AT/PS2)
    - Log HID keycode translations and reports
    - Enable verification of keyboard behavior across different hardware
    This will help confirm the scancode sequences sent by different keyboards.
    Refs #21
    * Fix Pause key not working on AT/PS2 keyboards (Issue #21)
    The Pause key wasn't working, and after digging into it with some
    debug logging, found two separate issues:
    Problem 1: Wrong HID code for regular Pause
    When you pressed Pause, it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
2025-10-22 Refactor: Optimize HID Report Sending and Enhance Documentation (#23)
    * refactor(hid): optimize HID report sending and enhance documentation
    - Replace hid_print_report() with integrated hid_send_report() wrapper
    - Eliminate duplicate hex dump construction (47% faster on DEBUG+failure)
    - Simplify call sites from 9 lines to 2 lines each
    - Add Report ID to hex dumps (matches USB wire format)
    - Enhance error messages with instance/report_id/len details
    - Update all docstrings with comprehensive documentation
    - Zero overhead in production (1.8µs unchanged)
    - Flash: -16 bytes
    Performance improvements:
    - DEBUG+failure: 27.3µs → 14.5µs (47% faster)
    - Production: 1.8µs → 1.8µs (unchanged)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
2025-10-24 Add Pico SDK 2.2.0 as submodule and improve portability
    - Add Pico SDK 2.2.0 as git submodule in external/pico-sdk
    - Pin to commit a1438df (tag 2.2.0) with nested submodules
    - Update CMakeLists.txt with smart SDK detection (env var → submodule → error)
    - Update README.md with clone instructions (--recurse-submodules)
    - Add comprehensive Pico SDK documentation to copilot-instructions.md
    - Remove hardcoded personal paths from documentation
    - Portable: Works on any system without PICO_SDK_PATH configuration
    - Version controlled: SDK pinned to exact version (2.2.0)
    - Nested submodules: TinyUSB, lwIP, btstack, mbedtls, cyw43-driver included
    - Backward compatible: PICO_SDK_PATH env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
2025-10-25 Remove buzzer/piezo speaker support (#24)
    Remove buzzer support to achieve 100% non-blocking architecture compliance.
    The feature was edge-case hardware (custom PCB only), redundant with LED
    feedback, and used alarm callbacks that introduced timing complexity
    incompatible with microsecond-precision PIO protocol handling.
    Changes:
    - Remove src/common/lib/buzzer.c and buzzer.h (326 lines removed)
    - Remove CONVERTER_PIEZO and PIEZO_PIN defines from config.h
    - Remove buzzer initialization from main.c
    - Remove buzzer calls from AT/PS2 protocol (preserve LOG_DEBUG output)
    - Remove hardware_pwm library dependency from CMake (no longer needed)
    Rationale:
    - Violates "strictly non-blocking" architec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
    [config.h, main.c]
2025-10-25 Add comprehensive enforcement tools for architecture compliance (#25)
    * Add comprehensive enforcement tools and testing framework
    Implements automated architecture compliance checks to prevent violations
    of critical project rules identified in earlier review.
    **New Tools:**
    - Lint script (tools/lint.sh): Detects 7 types of violations
    - Blocking operations (sleep_ms, busy_wait_us, etc.)
    - Multicore API usage (single-core architecture only)
    - printf in IRQ context
    - Unsafe ringbuf_reset() usage
    - Repository policy violations
    - Missing copy_to_ram configuration
    - Git hooks (.githooks/): Pre-commit and commit-msg validation
    - Commit template (.gitmessage): Built-in reminders
    - Test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
2026-02-11 Docs/public documentation structure (#29)
    Completely reworked and consolidated all documentation from scattered locations (src/, doc/) into unified docs/ hierarchy. READMEs for keyboards, protocols, and scancodes now live under docs/ with proper categorisation.
    Updated CodeRabbit configuration and copilot instructions to reflect new paths. Added source file links throughout documentation for easier navigation.
    Any old/obsolete documentation has now been removed.
    [BOM_PCB_IBM Model F AT Converter_2024-01-14.csv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]
2026-02-12 refactor: code quality and tooling enhancements (#30)
    * refactor: code quality and tooling enhancements
    Git Hooks:
    - Fixed comment line filtering in commit-msg and pre-commit hooks
    - Hooks now correctly ignore git comment lines (lines starting with #)
    - Prevents false positives when internal docs appears in commit templates
    Include Order Standardisation:
    - All source files now follow consistent include order
    - Order: own header, standard lib, Pico SDK, external libs, project headers
    - Blank lines between groups for readability
    Header Guard Consistency:
    - Fixed keyboard.h files using KEYMAP_H guard (should be KEYBOARD_H)
    - Affects: amiga/a500, apple/m0110a, cherry keyboards, microswitch, m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
    [config.h, main.c]
2026-02-12 Ci/docker optimization (#31)
    * perf(ci): optimize Docker builds with GitHub Actions cache and artifact reuse
    * ci: add workflow_dispatch for manual triggering
    * revert: remove workflow_dispatch - will test via PR
    * perf(ci): switch to cache mode=min for faster exports
    * refactor(ci): upgrade docker/build-push-action to v6 and improve .env parsing robustness
    * fix(ci): update all GitHub Actions to latest versions (v6/v7 with Node.js 24)
    - actions/checkout: v4 → v6.0.2
    - actions/upload-artifact: v4 → v6.0.0
    - actions/download-artifact: v4 → v7.0.0
    - docker/setup-buildx-action: v3 → v3.12.0
    - docker/build-push-action: already on v6.19.2 (latest)
    All actions now use Node.js 24 run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
2026-02-15 feat(protocols): standardize protocol implementation patterns and enhance validation (#34)
    * feat(protocols): standardize protocol implementation patterns and enhance validation
    Implement comprehensive protocol setup standardization with supporting
    documentation and automated validation to ensure consistency across all
    keyboard and mouse protocol implementations.
    Code Changes:
    1. Amiga Protocol Fixes (src/protocols/amiga/keyboard_interface.c)
    - Add LED state initialization before ringbuf_reset (setup step 1)
    - Add ringbuf_reset() call before PIO/IRQ setup (setup step 2)
    - Add IRQ priority configuration (setup step 13)
    - All changes follow the standard 13-step protocol setup pa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
2026-02-25 feat(layers): Multi-layer support, PIO IRQ improvements and protocol robustness (#38)
    * Refactor: Implement unified layer system (Phase 1-2)
    Add layer keycodes (0xF0-0xFF): MO/TG/TO/OSL operations
    Replace keymap_actions with proper layer state tracking
    Migrate all 8 keyboards to unified system
    All builds tested and lint checks passed
    * Docs: Update layer system documentation
    Updated documentation to reflect the new unified layer system:
    - docs/development/custom-keymaps.md: Complete rewrite of multi-layer section with comprehensive explanation of MO/TG/TO/OSL keycodes, layer priority system, and practical examples
    - docs/keyboards/README.md: Updated layer example to show MO_1/TG_1/TO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
    [config.h, keyboard_converter_board.h]
2026-02-26 feat(tools): add Docker-integrated static analysis pipeline (#39)
    * feat(tools): add Docker-integrated static analysis pipeline
    Adds Clang-Tidy 14 and Cppcheck 2.19.0 to the main build container,
    matching the versions used by CodeRabbit. Analysis runs after a
    successful build (ANALYZE=1) so all PIO-generated headers are
    available, avoiding the linking failures of the previous standalone
    approach.
    - .clang-tidy: project-specific check configuration
    - tools/analyse.sh: orchestrates clang-tidy and cppcheck
    - tools/filter_compile_db.py: strips SDK entries from compile database
    - tools/parse_compile_db.py: extracts files, includes, and safe defines
    - Dockerfile/docker-compose.yml/entrypoint.sh: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
2026-03-01 docs: fix missing cross-links and index entries across docs section R… (#42)
    * docs: fix missing cross-links and index entries across docs section READMEs
    Three documentation index files updated. No source code or functional
    changes; this is purely documentation link/index hygiene.
    docs/README.md
    --------------
    - Added a new "🔢 Scancodes" section between Features and Advanced
    Topics, with a one-paragraph introduction and link to scancodes/README.md.
    The scancodes section existed in full but had no entry in the top-level
    docs index at all.
    - Added a "Understand scancode translation → Scancode Sets" row to the
    Quick Reference table to match the new section.
    docs/features/READ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
2026-03-01 docs: update AI instructions, code standards, and README accuracy (#43)
    - copilot-instructions.md: add code standards check to per-response
    workflow; restructure AI guidelines with explicit validation source
    priority order; add training data policy (last resort only — must
    tell user and confirm before acting); remove duplicate File
    Organization section; expand Repo Structure to reflect actual src/
    layout including board_config/, cmake_includes/, and full common/lib/
    library inventory
    - code-standards.md: correct .clang-format existence claim (file does
    exist in repo root); add __force_inline guidance for hot-path inline
    functions; add Static Scope section under Code Organis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
2026-03-03 code quality: include audit, Doxygen standardisation, and C11 style fixes (#44)
    * code quality: include audit, Doxygen standardisation, and C11 style fixes
    Applies a comprehensive code quality pass across all protocol and scancode
    modules, addressing includes, documentation, type definitions, and minor
    accuracy issues surfaced during an include-chain audit.
    Include audit
    -------------
    All files now include only what they directly use — no transitive reliance:
    - amiga: replaced bsp/board.h with tusb.h (tud_hid_ready(), not board_millis())
    - apple-m0110, at-ps2/keyboard, xt: added tusb.h explicitly alongside bsp/board.h
    - at-ps2/common_interface, at-ps2/mouse, amiga/scancode, apple-m0110/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
    [config.h, keyboard_converter_board.h]
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

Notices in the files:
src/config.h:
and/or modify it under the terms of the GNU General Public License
